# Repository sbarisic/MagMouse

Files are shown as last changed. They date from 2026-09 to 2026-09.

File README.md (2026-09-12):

# MagMouse

An open-source wired mouse exploring contactless magnetic buttons, programmable
electromagnetic click feedback, and a motorized haptic scroll wheel.

**Status: three Rev-A bench PCBs routed; supplier/CAM and hardware approval pending.**
Open the active [Main project](hardware/modular/main/Main.kicad_pro) or
[Wheel project](hardware/modular/wheel/Wheel.kicad_pro). Both have zero unrouted
connections and zero physical DRC/parity issues. See the
[routing review](hardware/modular/MAIN_SIGNAL_ROUTING.md) and
[modular hardware package](hardware/modular/README.md). The original monolithic
project is retained as a reference. These are not fabrication-ready designs;
mechanics, manufacturing and hardware qualification remain open. Contactless sensing removes
electrical switch contacts; it does not eliminate mechanical wear or other failures.

The current [Rev-A bench package](hardware/bench/README.md) targets five bare
three-board panels, one self-assembled population and one stencil, with U32
unpopulated. Encoder now uses the common four-layer construction. The
[cost checkpoint](hardware/bench/COST_CHECKPOINT.md) records historical delivered
prices of EUR 224.55 for economy panels/stencil, EUR 252.46 with paid impedance
control and EUR 335.96 for separate boards. These precede the wire revision. Components, wires and bench
mechanisms are additional; the complete delivered total remains unverified.
The files are for quote/review only, pending supplier, assembly, bench-fit and
CAM checks. Earlier [PCBA quote packages](hardware/quotes/README.md) remain as
historical comparisons, not the selected purchasing plan.

Nine internal connectors now use labelled soldered-wire arrays. The
[wire map](hardware/bench/package/wire-map.svg) retains all conductors and grounds;
[printable PETG fixtures](mechanical/bench/README.md) include editable build123d,
STEP/STL parts and assembly drawings. Fixed button magnets use
[per-button calibration](docs/button-calibration.md); runnable firmware remains
separate. The revised electronics subtotal from saved prices is EUR 73.84 for
one set, excluding optics, freight/taxes and unpriced fixture/wire materials.

## V1 concept

- ESP32-S3 with native USB Full-Speed HID; target report interval: 1 ms.
- PMW3360DM-T2QU + LM19-LSI optical sensor for cursor movement; ICM-42688-P for supplementary motion.
- Three elastic button paddles provide passive return. Each uses a TMAG5253
  position sensor with its own magnet, plus a custom moving-magnet actuator with
  a stationary wound coil, ADS7038 feedback, and a DRV8231A bidirectional driver.
- MA735 angle sensing and a GB1806 motor driven by DRV8316R for scroll haptics.
- One USB-C cable for data and 5 V power, with force limits based on detected
  source capability. A powered Type-C hub/adapter is the intended full-power source.

## Repository map

| Directory | Contents |
| --- | --- |
| [hardware](hardware/README.md) | Electronics, preliminary BOM, schematic and PCB work |
| [mechanical](mechanical/README.md) | Housing, button mechanisms, scroll assembly |
| [firmware](firmware/README.md) | Embedded architecture and bring-up plan |
| [software](software/README.md) | Future PC configuration application |
| [docs](docs/README.md) | Requirements, interfaces, power and roadmap |

Start with the [architecture](docs/architecture.md), [interface plan](docs/interfaces.md),
and [button prototype plan](mechanical/button-mechanisms/README.md), then the
[roadmap](docs/roadmap.md). [ideas.md](ideas.md) preserves the original
brainstorming notes; the organized documents distinguish selected directions from
open engineering questions.

## Contributing and licensing

See [CONTRIBUTING.md](CONTRIBUTING.md). The next milestone is mechanical-interface
CAD, resulting PCB adjustments and whole-board review before manufacturing closure.

Hardware/mechanical: **CERN-OHL-S-2.0**. Firmware, PC software and supporting code:
**GPL-3.0-or-later**. General documentation: **CC-BY-SA-4.0**.
See [LICENSE.md](LICENSE.md) for scope and full texts.

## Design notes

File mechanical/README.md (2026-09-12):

# Mechanical design

Status: editable Rev-A bench fixture CAD and optical datums; final shell and
in-mouse mechanisms remain provisional.

- [housing](housing/README.md): enclosure, optics and component packaging.
- [scroll-wheel](scroll-wheel/README.md): wheel, shaft, motor and encoder alignment.
- [button-mechanisms](button-mechanisms/README.md): three contactless haptic buttons.
- [optical](optical/README.md): PMW3360/LM19-LSI stack and aperture reference dimensions.
- [bench](bench/README.md): build123d source, 19 printable PETG part designs,
  STEP/STL exports, removable supports, wire clamps and dimensioned assembly views.

The bench fixture uses build123d 0.11.1. Optical and motor dimensions that lack
supplier evidence remain parameters requiring measurement.
Validate magnet separation with wheel and custom button-coil fields active, including
temperature and full travel. Preserve physical stops and passive return behavior
so loss of power does not depend on actuator control to constrain the mechanism.
The elastic button paddles provide passive return; validate their material,
geometry, print process, creep and fatigue as functional springs.

License: CERN-OHL-S-2.0; see [LICENSE](LICENSE).
Source location: <https://github.com/sbarisic/MagMouse>.

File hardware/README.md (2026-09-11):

# Electronics

Status: the independent main and wheel PCBs are routed, with zero unrouted
connections and zero physical DRC/parity issues. Mechanical integration,
manufacturing review and hardware qualification remain open.

- [Main project](modular/main/Main.kicad_pro) and [Wheel project](modular/wheel/Wheel.kicad_pro): active editable designs.
- [Rev-A bench panel and assembly package](bench/README.md): current cost-reduction
  variant, four-layer Encoder, one-population purchasing list and quote-only
  manufacturing files. The derived panel does not replace the source boards.
- [Modular package and reviews](modular/README.md): current routing, cable and mechanical status.
- [Original KiCad project](kicad/README.md): retained monolithic reference and circuit documentation.

- [schematics](schematics/README.md): circuit partition and review requirements.
- [pcb](pcb/README.md): layout and release requirements.
- [bom](bom/README.md): candidate component inventory.

Use the [interface allocation](../docs/interfaces.md) and
[power plan](../docs/power.md) as design inputs. Exact package variants, GPIOs,
passive values, protection circuitry and connectors remain to be validated.

License: CERN-OHL-S-2.0; see [LICENSE](LICENSE).
Source location: <https://github.com/sbarisic/MagMouse>.

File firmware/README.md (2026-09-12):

# Firmware

Target: ESP32-S3. Status: subsystem plan only; no build, flash command, device
drivers or USB implementation yet. Framework/toolchain selection is pending the
timing feasibility work. The revision 0.4 [GPIO/peripheral allocation](../docs/interfaces.md)
is checked against the schematic; runtime deadlines remain unproven.
Do not interpret this directory as runnable firmware.

The small-batch [button calibration contract](../docs/button-calibration.md)
uses secured magnets with measured released/pressed endpoints and hysteresis.
Precision matching of button magnets is not a Rev-A fabrication prerequisite.

## Planned responsibilities

| Subsystem | Responsibility |
| --- | --- |
| Board support | Validated pin map, rails, safe boot and recovery |
| Device drivers | PMW3360, ICM-42688-P, two ADS7038 devices, MA735, DRV8231A and DRV8316R |
| Input processing | Optical reports, calibrated Hall thresholds/hysteresis and wheel movement |
| Button control | Position/current feedback and bounded bidirectional click/release pulses; elastic paddle supplies passive return |
| Wheel control | Encoder calibration, commutation/FOC and bounded detent torque |
| Power/fault manager | Source capability, total budget, hardware faults and stale-sample shutdown |
| USB HID | Three buttons, relative X/Y and wheel; target 1 ms report interval |
| Configuration | Versioned profiles, validation and persistence |
| Status | Single-data-pin addressable RGB through RMT; exact LED protocol pending |

Reserve MCPWM group 0 for wheel 3-PWM and group 1 for six independent button
commands. SPI2 owns five shared devices; SPI3 serves only the wheel ADC.
Use one bounded owner per bus. Generic per-sample SPI API calls are not proof
of the required motor-current acquisition timing; measure the complete path.
Do not let a motor/LED library silently reallocate these resources.

Bring up USB and sensing with actuators disabled first. Add one current-limited
coil, then the wheel, then combined power allocation. Firmware must enforce
limits regardless of values supplied by the PC application. Define explicit
uninitialized, ready, active and fault states with actuator-off reset behavior.

The custom actuator needs a measured force/current map across position and both
polarities. Firmware commands only the added haptic force; it does not generate
the paddle's baseline spring force. Account for direction changes, current decay
and valid ADC sampling windows rather than assuming current follows PWM instantly.
Calibrate sensing with coil and wheel interference present.

Use explicit per-effect duration, duty/repeat-rate and current limits, with zero
commanded coil current after an effect and while held at rest. Include driver
wake latency in click timing and use the actual IN1/IN2 controls documented in
[interfaces](../docs/interfaces.md). The revision 0.3 schematic gates commands
with a hardware heartbeat timeout. Implement its startup, heartbeat and USB-state
contract from [power](../docs/power.md); do not assume button-driver fault telemetry
is available.

When implementation begins, add reproducible builds, host-testable control/power
logic, hardware integration checks and CI. USB VID/PID assignment, report layout,
control-loop rates and configuration transport are unresolved. Check redistribution
rights before adding optical-sensor firmware blobs or third-party motor libraries.

See [interfaces](../docs/interfaces.md), [power](../docs/power.md), and
[roadmap](../docs/roadmap.md). License: GPL-3.0-or-later; see [LICENSE](LICENSE).

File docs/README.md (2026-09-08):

# Design documentation

- [Architecture and requirements](architecture.md)
- [Electrical interfaces](interfaces.md)
- [Wheel driver, acquisition and brake implementation contract](wheel-control.md)
- [Power and actuator constraints](power.md)
- [Custom button mechanism and prototype targets](../mechanical/button-mechanisms/README.md)
- [Development roadmap](roadmap.md)
- [Reference sources](references.md)

These documents maintain the design decisions, including the custom button
actuator revision. [The original ideas](../ideas.md) are preserved as historical
notes. The current documents are a planning baseline, not a verified schematic
or a declaration of hardware compatibility.

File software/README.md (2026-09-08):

# PC configuration software

Status: scope only; no application, dependencies, build or installation workflow.
Choose supported operating systems and an application stack once the firmware
configuration protocol is defined.

Planned functions:

- Discover the mouse and display firmware/protocol compatibility.
- Configure button actuation thresholds and bounded haptic profiles.
- Configure wheel detent behavior and profile selection.
- Guide calibration and display power/fault state.
- Import/export versioned profiles with validation and explicit device writes.

Ordinary mouse input must work without this application. The device remains
responsible for current, thermal and source-power limits. Define units, ranges,
schema versioning, persistence and incompatible-profile behavior before UI work.
Configuration transport is TBD; do not assume a vendor HID or serial protocol yet.

License: GPL-3.0-or-later; see [LICENSE](LICENSE).

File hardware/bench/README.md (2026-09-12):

# MagMouse Rev-A bench prototype

**Rev-A bench prototype — pending supplier/CAM approval. Do not order yet.**

Purchasing is limited to private-consumer suppliers; the user has no business.
CODICO business-only offers are excluded. Distinguish EU-stock items from
imports with Croatia shipping; see SOURCING.md for current evidence.

This variant targets five bare panels, one populated Main/Wheel/Encoder set,
and one unframed stencil. Main and Wheel remain the maintained routed source
boards. Encoder now shares their four-layer construction. U32 is omitted only
from the bench purchasing and paste variant; its schematic and footprint remain.

## Review files

- `MANUFACTURING_REVIEW.md`: completed local manufacturing review and JLC handoff.
- `package/CAM-review-attachments.zip`: consolidated, hashed CAM review attachments.
- `L1_REVIEW.md`: implemented Bourns replacement and local buck review.
- `HARNESS_REVIEW.md`: soldered-wire pin maps, lengths and pending optical identity.
- `STENCIL_REVIEW.md`: package dispositions and remaining process limits.
- `BENCH_ACCESS_REVIEW.md`: probe access, support and local copper findings.
- `supplier-drafts/`: unsent Ploopy/JLC CAM drafts and the superseded Würth follow-up;
  exported CAM draft identifies the actual ZIP hashes.

- `Panel.kicad_pro` / `Panel.kicad_pcb`: derived 151 x 139 mm, three-design panel.
- `panel-mechanical.svg`: printable outline and component-boundary review.
- `panel-manifest.json`: source hashes, board/reference mapping and translations.
- `package/Panel-Gerbers-QUOTE.zip`: copper, mask, silkscreen, routed edges and drills.
- `package/Stencil-QUOTE.zip`: top paste with U32 and hand-fitted parts excluded.
- `package/one-set-purchasing.csv`: exact MPN groups, references, quantities,
  minimum purchases, spares and public supplier observations.
- `package/all-vias.csv`: via-only fill/cap inventory. Never fill component holes,
  tooling holes or perforation holes.
- `BENCH_FIXTURE.md`, `bench-fixture.svg`: adjustable bench arrangement; no shell claim.
- `mechanical/bench/`: editable build123d, STEP/STL parts and dimensioned fixture views.
- `package/button-calibration.md`: fixed magnet endpoint calibration; runnable firmware is separate.
- `package/harness-pin-map.csv`: all 46 wires, component-side and mirrored solder-side views.
- `population-contract.json`: 282 retained parts, nine replaced connectors and U32 exclusion.
- `ASSEMBLY_AND_BRINGUP.md`: preparation, practice assembly and staged hardware tests.
- `SOURCING.md`, `WURTH_ENQUIRY.md`: supplier evidence and unresolved interfaces.
- `ORDER_READINESS.md`: remaining PCB work for a testable bench revision.
- `COST_CHECKPOINT.md`, `quote-observations.json`: live bare-board comparisons
  and the incomplete one-population cost estimate.
- `package/evidence/acceptance.json`: fresh native and strict electrical checks.
- `package/copper-review/`: exported copper and reference-plane views.

## Construction for both quotes

Order quantity five panels, **three different designs per panel**. Use FR4 TG155,
nominal 1.6 mm, four layers **JLC041611-2116**, 1 oz outer and 1 oz inner copper,
green mask, white silkscreen, ENIG 1 microinch and epoxy-filled/copper-capped vias.
The smallest vias are 0.20 mm drill / 0.45 mm pad; retain the source drill sizes.
The website's drill selection bucket does not authorize enlarging these holes.
Require CAM confirmation of the drill and fill specification.

The guaranteed variant requests 90 ohm differential USB, tolerance +/-10%.
The economy variant omits paid impedance control/testing only. Both retain
F.Cu width 0.1466 mm, gap 0.1501 mm and In1 ground reference. Do not accept a
stack substitution without a fresh impedance and return-path review.

All functional copper belongs to an individual board. No electrical connection
crosses a tab. The panel uses 2 mm separation clearance, ten 5 mm tabs with
five 0.6 mm perforations each, 0.9 mm pitch and 0.3 mm webs. Cut while supported
and **before population**. Do not bend populated boards to depanel them.

Selected Rev-A stencil: one 220 x 200 mm unframed stainless sheet, 0.10 mm thick,
three identifiable TOP aperture groups. Apply `paste_variant.py` for the
reviewed Hall/WSON/ADC apertures; copper and coordinates remain 1:1. JLC's multi-board option requires
permission to rearrange groups: approve the final CAM group positions before
building the alignment jig. A reordered stencil requires a regenerated jig.

## Reproduce and verify

Run with KiCad 10.0.6 Python, Shapely 2.1.2 and NumPy 2.4.6. The builder searches
`build/bench-python` for the latter libraries; dependencies are not vendored.

```powershell
& '<KiCad>/bin/python.exe' hardware/bench/build_panel.py
& '<KiCad>/bin/python.exe' hardware/bench/verify_bench.py
& '<KiCad>/bin/python.exe' hardware/bench/export_bench.py
& '<KiCad>/bin/python.exe' -m unittest discover -s hardware/bench -p 'test_*.py'
```

Two native panel builds were byte-identical. Export ZIP hashes change with KiCad
timestamps; the package hashes identify each exported snapshot. Copper/pad/via
and saved ground-fill transforms are checked against the individual source
boards. Source modification requires rebuilding and rerunning checks.

## Manufacturing and assembly items still open

The L1 replacement and soldered-wire migration are implemented; see ORDER_READINESS.md.
Ploopy is the user's selected optical supplier; exact lens/part confirmation
remains open. Wire/fixture fit, optical mounting and final ergonomic shell
development are assembly/mechanical tasks, not bench bare-board ordering gates.

1. Exact wire product, insulation/strand fit, continuity and strain-relief checks.
   The FFC enquiry requirement is superseded; no follow-up is sent.
2. Complete delivered parts/harness/mechanism/consumables pricing. Catalogue
   stock is not a reserved order; missing lines are not zero-cost parts.
3. Received lens/motor dimensions and practical bench fixture fit. Final shell,
   paddle geometry, optical retention and ergonomic wheel support remain open.
4. The 0.10 mm stencil design is selected; see STENCIL_REVIEW.md for accepted
   aperture geometry and volume tradeoffs. CAM confirms manufacturability.
   Paste/profile setup, practice reflow and hidden-joint inspection are assembly
   tasks, not bare-board ordering gates.
5. Fabricator acceptance of tab support, routability, minimum vias and selective
   fill/cap instructions. Zero native DRC is not manufacturing approval.
6. Complete delivered project total. The identical-stack separate-board
   comparison is complete and favors the panel. Never treat a partial subtotal
   as the €400 target.

CAD connectivity, DRC and regression results do not establish USB operation,
motor/brake behavior, analog noise, thermal performance or assembly yield.

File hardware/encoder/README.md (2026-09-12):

# Upright wheel encoder

## Current soldered-wire revision

J7 now uses eight plated solder holes in a 2×4 array on 2.54 mm pitch,
0.8 mm nominal holes / 1.8 mm pads. All eight signals, including three grounds,
remain connected to Main J6 by the 150 mm AWG28 harness. There is no JST purchase
or paste on these lands. Sensor position and board outline are preserved; local
termination routing is updated. See the [wire map](../bench/package/wire-map.svg)
and [printable carrier](../../mechanical/bench/README.md). The historical connector
description below is superseded for Rev-A.

## Rev-A bench stack migration, 2026-09-11

The current PCB uses the same four-layer **JLC041611-2116** construction as
Main and Wheel. Original outer-layer routing, 17 through vias, sensor datum
and connector orientation are preserved. In1/In2 have ground copper. Native
DRC, schematic parity and connectivity pass. The historical description below
predates this migration; use [the bench package](../bench/README.md) for the
current panel, self-assembly variant and unresolved ordering gates.

Revision 0.8, 2026-09-09, KiCad 10.0.6. The separate **14 x 18 mm** encoder PCB
is fully routed. ERC, physical DRC and schematic parity pass; there are zero
unconnected items. These checks do not establish mechanical fit or operation.
**This is a prototype design, not a fabrication release.**

Open [Encoder.kicad_pro](Encoder.kicad_pro), then its
[schematic](Encoder.kicad_sch) and [PCB](Encoder.kicad_pcb). Keep the repository
directory structure: the library tables reference the shared MagMouse libraries
in `../kicad`. U27 and C62 have been removed from the motherboard project.

## Parts and connection

The encoder assembly BOM contains U27 MA735GGU-P, C62 local 1 uF bypass and
J7. The motherboard BOM contains J6, the switched encoder supply U28 and the
existing U29/U25 SPI buffers. No ESP32 pin allocation changed.

Both connectors use **JST SM08B-SRSS-TB(LF)(SN)**, an eight-pin, 1 mm pitch,
right-angle SMT SH header, [JLCPCB C160407](https://jlcpcb.com/partdetail/JST-SM08B_SRSS_TB_LF_SN/C160407).
The catalog listing was checked on 2026-09-09; refresh stock and assembly
eligibility when quoting. Use KiCad's standard
`Connector_JST:JST_SH_SM08B-SRSS-TB_1x08-1MP_P1.00mm_Horizontal` footprint.

| Motherboard J6 | Encoder J7 | Signal |
| --- | --- | --- |
| 1 | 1 | ENC_3V3, switched supply |
| 2 | 2 | GND |
| 3 | 3 | ENC_SCLK_LOCAL, buffered clock |
| 4 | 4 | GND |
| 5 | 5 | ENC_MOSI_LOCAL, buffered data |
| 6 | 6 | ENC_CS_LOCAL, buffered select |
| 7 | 7 | GND |
| 8 | 8 | ENC_MISO_LOCAL, return to U25 |

[harness.json](harness.json) is the machine-checked wiring specification.
Use eight separate conductors, including all three ground contacts. Check
continuity by pin number; connector appearance and wire colours do not prove
correct ordering. Do not substitute an unverified mirrored cable.

The harness needs two **SHR-08V-S-B** housings and sixteen **SSH-003T-P0.2-H**
contacts. JST specifies AWG 28-32 wire with 0.4-0.8 mm insulation diameter for
these contacts. The prototype wire-length target is **50 mm**, subject to fit
and waveform measurements. Housings, crimp contacts, wire and harness assembly
are separate from the two SMT assembly BOMs. See the
[JST SH drawing and contact specification](https://www.jst-mfg.com/product/pdf/eng/eSH.pdf).

## Placement and mechanical datums

The two-layer board has nominal 1.6 mm thickness and bounds X=50..64,
Y=50..68 mm in KiCad. All three components are on the front.

- U27 centre: (57,55.5) mm, 7 mm from the left edge and 5.5 mm from the top.
  The front of the sensor faces the shaft magnet.
- C62 centre: (56.8,52.2) mm. Its supply-pad-to-VDD route is 1.525 mm.
- J7 centre: (57,64.5) mm. Its mating direction is toward +Y, past the lower edge.
- Dwgs.User lines at X=51.5/62.5, Y=50..60 reserve provisional side clip lands.
  There are no mounting holes. The mating housing, cable bend and support need
  separate clearance beyond the PCB outline.

Signals use 0.15 mm tracks; the incoming supply uses 0.25 mm tracks.
Ground pours cover both copper layers with local return and stitching vias.
Through vias are 0.60/0.30 mm. The project uses 0.15 mm default clearance and
a 0.127 mm absolute minimum; final stackup and stencil review remain open.

For the proposed horizontal axle the board stands beside a shaft end. Sensor
height, magnet dimensions/gap and support geometry must follow the actual
wheel assembly. The 14 x 18 mm outline is provisional. A routed board does not
prove it fits the motherboard wheel reservation. See
[mechanical integration](../../mechanical/scroll-wheel/ENCODER_BOARD.md) and the
[MA735 datasheet](https://www.monolithicpower.com/en/documentview/productdocument/index/version/2/document_type/Datasheet/lang/en/sku/MA735GGU/).

## Reproduce the checks

Run from the repository root with Python 3 and KiCad 10:

    python hardware/kicad/export_review.py
    python hardware/kicad/export_review.py --schematic hardware/encoder/Encoder.kicad_sch
    python hardware/kicad/verify_encoder.py
    python hardware/kicad/test_encoder_checks.py
    python hardware/kicad/verify_wheel.py
    python hardware/kicad/test_wheel_checks.py
    python hardware/kicad/export_pcb_review.py
    python hardware/kicad/export_pcb_review.py --board hardware/encoder/Encoder.kicad_pcb --require-routed

Encoder outputs go to `build/encoder-review` and `build/encoder-pcb-review`;
motherboard outputs remain in their existing review directories. Each project
gets a separate draft BOM. The wheel checker reads both netlists. The encoder
checker validates the connector identities, switched/buffered boundaries, pin
ordering, local bypass and component split against the harness specification.
Eight encoder tests include seven injected faults. Five wheel tests also pass.

The motherboard has 317 footprints. Its [actuator distribution routing pass](../pcb/ACTUATOR_DISTRIBUTION_LAYOUT.md)
reduces native unrouted connections to 247. Physical DRC and parity pass, but
board-wide routing remains open. Before releasing either
board, verify cable continuity, 10 MHz SPI waveforms under concurrent operation,
power-off isolation, angle repeatability, magnetic interference and mechanical
retention. No Gerbers or placement files are released for ordering.

Motherboard J6 is now rotated 180 degrees at (113, 103.5) mm and mates toward
minus Y, the front edge. Check shell/USB clearance and harness bend radius.
Encoder J7 and the pin-to-pin harness map are unchanged.

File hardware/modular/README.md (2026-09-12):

> Rev-A bench update: internal interfaces now use soldered through-hole arrays.
> The active manufacturing-review package is `hardware/bench/`; its HARNESS_REVIEW.md
> and generated wire maps supersede historical FFC/JST details below. Order scope
> is five bare three-board panels, one component population and one stencil.
> No final-shell or supplier/CAM acceptance is claimed.

# Modular mouse planning package

2026-09-11. **Main and wheel routed with zero unrouted connections. Mechanics remain provisional.**

Independent [main](main/Main.kicad_pro) and [wheel](wheel/Wheel.kicad_pro)
schematics now exist. They include J8/J9 signal headers, J10/J11 power headers
and local disconnect bias. The wheel also has local bulk storage, TVS and a
discharge resistor. Both pass ERC. See the
[interface review](INTERFACE_REVIEW.md) for the implemented changes, verification
commands and remaining power-return, wheel-storage and SPI3 timing findings.
The [wheel PCB](wheel/Wheel.kicad_pcb) has all 87 footprints on its 55 x 60 mm
outline. All connections are routed, with zero native unrouted items and zero
physical DRC/parity issues. See the [routing review](WHEEL_ROUTING.md).
The new [main PCB](main/Main.kicad_pcb) has all 246 footprints placed on the
125 x 80/44 mm outline, with zero physical DRC/parity issues and **zero native
unrouted connections**. The [completed signal/return review](MAIN_SIGNAL_ROUTING.md)
covers analog, USB, both SPI buses, optical, remaining controls and supplies.
The [input-power](MAIN_POWER_ROUTING.md) and
[source/actuator/interlock](MAIN_CONTROLS_ROUTING.md) checks still pass.
See the [main placement review](MAIN_PLACEMENT.md) and
[mechanical interface register](MECHANICAL_INTERFACES.md).

**Panelization is on hold until both boards have stable placement and mechanical
interfaces.** Existing nesting-study files remain unchanged. Neither board is
being released for ordering in this pass.

The prototype assumes fully connected internal cables. Per the user's decision,
child-board damage after disconnection is acceptable; disconnect/partial-insertion
survival does not block layout or require extra protection. Normal connected
power, thermal, signal and regeneration checks remain applicable.

The target order is five assembled panels, each with one main, one wheel and
one encoder board, delivered to Croatia, 43000. The finished main-board outline
uses the approved 125 mm length, 80 mm maximum width and 44 mm front edge.
Curvature and width-transition locations are draft assumptions from the sketch.

Panel nesting concept

## Concrete outputs

- [Main.kicad_pcb](main/Main.kicad_pcb): all 246 split-main footprints placed
  in the shaped 80 x 125 mm outline, with a 44 mm front edge.
- [Main-envelope.kicad_pcb](planning/Main-envelope.kicad_pcb): historical
  outline-only planning source with the source motherboard's four-layer stackup.
- [Wheel-envelope.kicad_pcb](planning/Wheel-envelope.kicad_pcb): provisional
  55 x 60 mm reservation. Its electronics now fit the independent wheel PCB;
  mounts, mating cables and assembled mechanical fit remain unproven.
- [Encoder-envelope.kicad_pcb](planning/Encoder-envelope.kicad_pcb): 14 x 18 mm
  reservation with the common four-layer stack. The existing routed encoder
  has not yet been converted or transferred into this file.
- [Panel-nesting-study.kicad_pcb](planning/Panel-nesting-study.kicad_pcb):
  147 x 135 mm drawing on Dwgs.User. It has no manufacturing Edge.Cuts, slots
  or breakaway drills. Open in PCB Editor, not 3D Viewer.
- [Partition report](planning/partition-report.json): complete proposed
  reference ownership and both endpoints of every main/wheel boundary net.
- [Partition and harness specification](partition-plan.json): editable inputs.

The files under `planning/` are historical envelope/nesting studies. They are
separate from the editable main and wheel PCB sources. The original motherboard
and routed encoder project remain unchanged.

The panel reserves 5 mm outer handling rails and at least 2 mm between unit
envelopes. Grey areas in the drawing are support-web space, not a finished
solid panel: routed slots and supports must be designed around actual loaded
boards. Perforated tabs connect boards mechanically; no electrical nets cross
them. Final tooling, tab access and unit support are still open.

## Circuit partition and interface

The fresh source netlists account for 320 footprints: 241 main, 76 wheel and
3 encoder. Counts include test points and exclude new modular-interface parts.
They are not the number of components that JLCPCB would populate.
The split schematics add 13 interface and 3 local power parts: current counts
are 246 main, 87 wheel and 3 encoder. The nesting drawing retains baseline
ownership counts. See [local power review](LOCAL_POWER_REVIEW.md).

Wheel ownership contains U21 DRV8316, U22 disable gates, U23 ADC2 with local
filters/reference/bypass, U24/U26 forward buffers and the complete brake
including comparator, reference, MOSFET, resistors and local capacitors.
SOA/SOB/SOC, their filters and all brake sense/gate/reference connections stay
within that board. Re-place them together before carrying any routes across.

U25 and C53 remain on main for return buffering. The switched encoder power
U28, forward buffer U29/C55 and J6 also remain on main. Retain the existing
[J6-to-J7 harness](../encoder/harness.json) directly to the encoder; routing
encoder traffic through the wheel board is no longer the preferred plan.
The wheel board still needs the ESP32 or a test fixture to commutate the motor.

The main/wheel boundary has **17 nets: 14 digital signals, +3V3, ACT_5V and GND**.
The signal harness has 30 contacts. Main J8 odd pins are GND; the J8 even pins
below each have an adjacent return. A flat same-side FFC between facing headers
maps J8.N to J9.(31-N), so wheel J9 even pins are GND. A prototype Hirose
FH12-30S-0.5SH(55) header is selected; cable orientation and conductor construction
remain unapproved. See the interface review.

| Main J8 pin (wheel J9 = 31 minus this pin) | Net | Direction |
| --- | --- | --- |
| 2 | SPI_SCLK | Main to wheel |
| 4 | SPI_MOSI | Main to wheel |
| 6 | CS_DRV8316 | Main to wheel |
| 8 | DRV_MISO_LOCAL | Wheel to main |
| 10 | MOTOR_SPI_SCLK | Main to wheel |
| 12 | MOTOR_SPI_MOSI | Main to wheel |
| 14 | CS_ADC2 | Main to wheel |
| 16 | ADC2_MISO_LOCAL | Wheel to main |
| 18 | WHEEL_PWM_A | Main to wheel |
| 20 | WHEEL_PWM_B | Main to wheel |
| 22 | WHEEL_PWM_C | Main to wheel |
| 24 | ACT_DRIVE_EN | Main to wheel |
| 26 | WHEEL_RUN_REQ | Main to wheel |
| 28 | DRV_FAULT_LOCAL_N | Wheel to main |
| 30 | +3V3 | Main to wheel |

ACT_5V and its power return use a separate two-contact harness provisionally.
A candidate is JST SM02B-PASS-TB(LF)(SN),
[JLCPCB C495198](https://jlcpcb.com/partdetail/JST-SM02B_PASS_TB_LF_SN/C495198).
JST rates the [PA family](https://www.jst-mfg.com/product/pdf/eng/ePA-F.pdf)
at 3 A with AWG22. This is not approval for a 3 A motor load: voltage drop,
regenerative pulses, connector temperature, wire size and protection still
need a budget. The no-boss header footprint and mating parts are now specified
in the interface review; stock, cable sourcing and assembly sign-off remain
open. A 50 mm signal cable is a provisional target, not a tested limit.

## Implemented interface and remaining connected-operation review

Extraction and local bias additions are implemented. Current closure status
and quantitative findings are in
[INTERFACE_REVIEW.md](INTERFACE_REVIEW.md). Physical harness and power-ramp
acceptance remains open even where settled-DC bias checks pass.

- Keep the implemented wheel-local low defaults on RUN/PWM and main R77 boot
  strap. The existing bias circuitry remains fitted.
- Retain local ACT_DRIVE_EN pulldown R84 and review independent power-up/down
  of +3V3 and ACT_5V. Keep autonomous brake operation independent of the host.
- Retain the implemented CS and U25 return-input bias. Normal connected reset
  and startup logic levels still need to be correct.
- Review partial-power behavior of every buffer, ADC and gate, including
  signal injection when one rail is absent. Confirm from the actual parts'
  datasheets; moving the existing buffers is not proof of safe sequencing.
- Review normal current sharing between power and signal ground conductors
  with both cables fully seated. Open-return and disconnect survival are outside
  prototype acceptance; do not add protection solely for those cases.
- Budget SPI3 round-trip delay through cable, buffers and ADC, plus SPI2 loading
  and branches. Provide appropriate source termination after that review and
  verify waveforms on hardware. SPI frequency alone does not define edge quality.
- Select actual connector MPNs and matched cable pin numbering, then add both
  connector endpoints, new bias components and test access to the schematics.
  Verify all 17 boundary nets by pin number in both assembled harnesses and CAD.

## Quote obtained and what remains

New [quote-only manufacturing packages](../quotes/README.md) are available for
five separate Main, Wheel and Encoder boards each. They contain actual routed
Gerbers/drills, validated BOM/CPL files and exact via-fill inventories. All three
jobs are now priced: EUR 779.84 in merchandise; the address-specific DHL DDP
checkout is USD 1,187.35 including shipping and duties/taxes. Main R25, Wheel U31 and Encoder U27
are out of stock; the PMW3360 and non-PCBA items are separate. See the linked
quote report for the full scope. Encoder stays two-layer in this comparison;
no production panel has been created and no order was submitted.

The [live JLCPCB calculator](https://cart.jlcpcb.com/quote) displayed
**US $179.47 for five bare 147 x 135 mm panels**, or **$35.89 per set in PCB
fabrication alone**. See the [recorded inputs and itemization](jlcpcb-quote-2026-09-10.json).
Settings: three different designs, four layers, nominal 1.6 mm,
JLC041611-2116, 1 oz outer/inner copper, green mask, ENIG, impedance control
and epoxy-filled/copper-capped vias. The quoted dimensions are provisional.

The calculator also gave $157.08 with ordinary plugged vias. That option is
excluded from the baseline because the current U1/C32/U21 in-pad vias require
filled/capped processing. Merely changing the order checkbox is not a valid
cost reduction for that layout. The browser was restored to filled/capped.

**The earlier bare-panel session obtained no assembled or delivered total.** Its assembly screen required
Gerbers before proceeding. The destination selector returned an empty country
list, so shipping to Croatia could not be calculated. No files were uploaded,
no supplier quote ID was issued and no order was placed. Components, assembly,
cables, shipping and taxes are absent from the $179.47 figure.

JLCPCB treats separable circuits as
[different designs](https://jlcpcb.com/help/article/different-design-in-your-pcb-files).
One panel therefore does not avoid mixed-design fees. Obtain assembly acceptance
for three designs on this panel and delivery with tabs intact. Follow its
[panelization guidance](https://jlcpcb.com/blog/mouse-bite-panelization-guide)
when creating the actual slots and tabs. The price above does not establish
acceptance of the unimplemented assembly panel.

To obtain a final assembled quote, finish the interface schematics, place and
route all units, validate the common encoder stackup, finish panel tooling and
export matching Gerbers/drills/BOM/panel-coordinate CPL. Resolve sensor and
connector sourcing and any assembler exclusions, then price five panels with
all 15 unit boards populated and shipping/tax for Croatia 43000. Compare against
separate boards shipped together before choosing the manufacturing format.

## Regenerate and validate the planning package

Export fresh XML netlists with KiCad before running the generator:

```powershell
$kicadCli = 'C:/Users/cartm/AppData/Local/Programs/KiCad/10.0/bin/kicad-cli.exe'
New-Item -ItemType Directory -Force build/modular | Out-Null
& $kicadCli sch export netlist --format kicadxml -o build/modular/main-netlist.xml hardware/kicad/MagMouse.kicad_sch
& $kicadCli sch export netlist --format kicadxml -o build/modular/encoder-netlist.xml hardware/encoder/Encoder.kicad_sch
python hardware/modular/build_planning.py --main-netlist build/modular/main-netlist.xml --encoder-netlist build/modular/encoder-netlist.xml
```

The generator verifies reference ownership, encoder uniqueness, complete
logical boundary coverage, absence of sensitive analog/phase/brake nets on
the cable, main-board dimensions and panel-envelope spacing. These checks
establish planning consistency only; they do not establish electrical
connectivity, DRC, return paths, thermal performance, mechanical fit or
manufacturing readiness of the future split.

Validation on 2026-09-10: KiCad loaded all four planning files with four copper
layers and no footprints or tracks. All three unit outlines form closed native
polygons; the panel drawing correctly has no board outline. Source PCB reference
sets match the fresh netlists (317 main-source and 3 encoder). Moving an ADC2
filter resistor into the main partition was rejected as two uncovered analog
boundary nets. Quote line items sum to $179.47. The source motherboard SHA256
is unchanged from the start of this planning pass.

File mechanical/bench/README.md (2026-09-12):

# Rev-A printable bench fixture

These are adjustable bench supports, not mouse-shell or final mechanism CAD.
Use `build_fixture.py` with build123d 0.11.1. The editable dimensions are in
`PARAMS`; an optional JSON `--config` overrides them. Run `python
mechanical/bench/build_fixture.py` to regenerate STEP, STL, assembly views and
validation. Print the dimensioned SVG at 100% and check its 100 mm scale.

Print PETG parts separately, with the broad flat face on the bed. Use a nozzle
and line width that can resolve the 0.3 mm saddle lip (for example a 0.25 mm
nozzle); do not assume a 0.4 mm extrusion reproduces that feature. Start with
0.2 mm layers and four perimeters; orient the lever on its side so the thin
flexure is not printed as an unsupported cantilever. Inspect the flexure and clamp sample before
printing the complete set. These are trial print settings, not a strength or
fatigue qualification. The largest pieces are 125 × 130 mm, below 180 × 180.

Build one fixture from four base tiles. Join the vertical seam with four
`tile_joiner_x` bridges centred at x=127.5 and grid y coordinates clear of
boards; join the horizontal seam with four rotated `tile_joiner_y` bridges
centred at y=130 and grid x coordinates. Confirm all chosen holes align before
tightening. Use M3 screws, washers and nuts. Keep the optical window unobstructed.

Use eight saddles/caps for Main and Wheel at the coordinates in
`generated/assembly-clearance.json`. M3 threaded rods, paired nuts and washers
set board height from 15 to 35 mm above the base top. Use nonconductive caps
with no more than 0.3 mm edge engagement. Verify copper/component clearance
against `package/support-clearances.csv`; never clamp a solder joint. The STEP
assembly includes board-outline envelopes and supports; it does not model all
real component heights. Measure underside parts and retain at least 5 mm free
below the lowest part or joint. Solder protrusions must remain below 1.5 mm.

The motor plate has general-purpose slots, a shaft clearance hole and an
optional measured bolt circle. `motor_bolt_circle=None` means no motor pattern
is claimed. Mount only the stationary motor structure. The upright carrier
supports a separately adjusted Encoder board using removable side clips; fit
clips to clear edge regions and leave the sensor face unobstructed. Verify
shaft/magnet alignment and gap after receiving parts. Do not run an unsecured
magnet. Lens retention width is likewise unset until the Ploopy lens is measured.

Print one lever/stop sample, then three after checking passive return and travel.
The magnet pocket's 5 mm diameter / 2 mm thickness defaults are editable trial
dimensions. Bond the magnet securely after polarity checks. Position the holder
over the unchanged Hall sensor, add shims and a hard stop that prevents contact,
then calibrate in software. The printed flexure requires fatigue and return-force
tests; it is not a production paddle. See `docs/button-calibration.md`.

Use a clamp at each end: two ribbon clamp pairs, two encoder clamp pairs and
eight compact pair clamps for power and coils. Shim the channel to grip insulation without
crushing it; the channel is deliberately adjustable for the selected wire.
Allow slack between clamp and board. Install wires after reflow and before
optical fitting. No clamps or new mounting holes are added to the PCBs.

Hardware purchasing starts with 150 M3 nuts, 150 washers, 100 M3×16/25 screws and
twelve 60 mm M3 threaded rods, plus any measured motor-adapter fasteners. These
are a provisional kit allowance, not an exact priced BOM. Wire, PETG, adhesive,
fastener and mechanism prices remain unquoted in EUR. Assembly tools are excluded.

Open physical checks: wire insulation/strand fit, encoder clip fit, lens stack
and retention, motor pattern, probe-barrel approach, actuator/coil attachment,
flexure performance, thermal behaviour and complete assembly interference.
CAD solid validity and board-envelope checks do not close these checks.

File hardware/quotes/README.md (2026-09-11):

# JLCPCB quote packages

**Latest comparison:** the [corrected fabrication quote](cost-reduction-2026-09-11/CORRECTED_QUOTE.md)
is **USD 774.51 DHL DDP delivered, approximately EUR 665.85 for two assembled
sets**, without the optional IMU. Five PCBs per design are fabricated and two
assembled. This removes an unnecessary small-via pricing tier while retaining
the actual CAD, fill/cap and Main USB impedance specification. The price is
about EUR 73.47 below the earlier two-set quote. Stock/optical/mechanical
exclusions remain; no order was submitted. Main/Wheel consolidation has a
[placement assessment](cost-reduction-2026-09-11/COMBINED_BOARD_ASSESSMENT.md),
not a finished combined layout or supplier quote. Earlier observations follow.

The [2026-09-11 snapshot](2026-09-11/validation.json) exports the current routed
Main, Wheel and Encoder boards from CAD commit `743d7f1`. It is **for pricing
only**, not a fabrication or assembly release. The boards and schematics are
unchanged. All three Gerber/BOM/CPL jobs have been uploaded and priced in the
signed-in JLCPCB workflow. With the user-provided shipping address for Croatia
43000, checkout quotes **USD 1,187.35 delivered by DHL DDP for five sets**:
USD 907.11 merchandise + USD 36.20 shipping + USD 244.04 customs duties/taxes.
This is **USD 237.47 per set**, approximately **EUR 1,021 total / EUR 204 per set**.
The EUR conversion uses the same cart's EUR 779.84 / USD 907.11 merchandise
values; checkout itself displays USD, so this is not a guaranteed EUR payment
amount. **The stock and optical/mechanical exclusions below still apply.**
No order or payment was submitted; the payment step was not entered.
See the [itemized live quote](jlcpcb-live-2026-09-11.json).

The [cost-reduction study](cost-reduction-2026-09-11/README.md) contains an
independent Main quote with U32 omitted, at EUR 411.26 for five boards, and
six-layer manufacturing comparisons. The original CAD and baseline cart are
unchanged. The measured changes suggest about 19% delivered savings for the
half-ounce six-layer/no-IMU case, subject to redesign and a fresh checkout;
they do not establish the requested 50% reduction.

The later [two-set quote](cost-reduction-2026-09-11/TWO_SET_QUOTE.md) is
**USD 859.98 DHL DDP delivered, approximately EUR 739.32**, with U32 IMU omitted.
It fabricates five of each design and assembles two, leaving three bare spares
per design. This reduces total spending by about 28%, while increasing the
cost per assembled set. It retains the stock/optical/mechanical exclusions.
The new three cart jobs are separate from the preserved five-set baseline;
neither is a breakaway panel. No order or payment has been submitted.

| Five-board job | PCB | Components | PCBA including components | Quote-page total |
| --- | ---: | ---: | ---: | ---: |
| Main | EUR 152.24 | EUR 233.19 | EUR 351.06 | EUR 503.29 |
| Wheel | EUR 99.58 | EUR 77.18 | EUR 145.99 | EUR 245.57 |
| Encoder | EUR 17.62 | EUR 1.50 | EUR 13.35 | EUR 30.97 |

The PCBA column includes the components column; do not add them again. The cart
rounds individual PCB/PCBA lines separately and is EUR 0.01 above the sum of
the three quote-page totals. Component purchases total EUR 311.87, including
the supplier's attrition quantities. Main/Wheel use Standard PCBA; Encoder
uses Economic PCBA and remains two-layer.

**Stock exclusions:** Main R25 / C23259 (887k resistor), Wheel U31 / C139302
(LM4040AIM3-2.5/NOPB), and Encoder U27 / C17233427 (MA735GGU-P). Exact-MPN
encoder search also found zero public and idle stock. No substitutes were
selected. The priced population is 205 Main + 81 Wheel + 2 Encoder references
per set, rather than the requested 291. Main J2/J3/J4 and SW1/SW2 were initially
unchecked by matching and were explicitly included before pricing.

These are partial-population quotes, not functional complete sets. The optical
sensor and mechanical/cable exclusions below also remain. The earlier
country-level shipping estimate of EUR 23.09 gave EUR 802.93 before tax.
The later address-specific DDP quote above supersedes that delivered-cost
estimate. The user authorized entering the address and phone for this quote.
Those personal details are not stored in repository artifacts. Supplier
placement rotation, small-board handling and manufacturing review are not
approved by obtaining this price.

Quote five of each design (five complete electronic sets) for Croatia, 43000.
Upload each row as a separate job, using its matching Gerber archive, BOM and
CPL. Supply the [manufacturing notes](2026-09-11/MANUFACTURING_NOTES.md) and each
board's via map/inventory with the quote request.

| Job | Gerbers/drills | BOM | CPL | Quoted components per board |
| --- | --- | --- | --- | ---: |
| Main | [ZIP](2026-09-11/Main/Main-Gerbers-QUOTE.zip) | [BOM](2026-09-11/Main/Main-BOM-QUOTE.csv) | [CPL](2026-09-11/Main/Main-CPL-QUOTE.csv) | 206 |
| Wheel | [ZIP](2026-09-11/Wheel/Wheel-Gerbers-QUOTE.zip) | [BOM](2026-09-11/Wheel/Wheel-BOM-QUOTE.csv) | [CPL](2026-09-11/Wheel/Wheel-CPL-QUOTE.csv) | 82 |
| Encoder | [ZIP](2026-09-11/Encoder/Encoder-Gerbers-QUOTE.zip) | [BOM](2026-09-11/Encoder/Encoder-BOM-QUOTE.csv) | [CPL](2026-09-11/Encoder/Encoder-CPL-QUOTE.csv) | 3 |

These files request **291 placements per set, 1,455 across five sets**. Main U35
PMW3360 is separately sourced/installed and is excluded from both assembly input
files. Its existing catalog ID and status remain in Main's procurement list.
The 44 copper-only test points are excluded explicitly. Lens, motor, coils,
cables, magnets, bearings, wheel and shell need separate cost lines.

## Validation

All **336 schematic/PCB references** are accounted for: 291 assembly components,
44 copper test points and one separately installed sensor. BOM and CPL have
identical population sets and no duplicates. Component values, footprints,
DNP/exclusion flags, connected pin/net assignments, native placement positions,
rotations and board sides are checked against current CAD.

Fresh native DRC/parity and connectivity checks pass on all three boards:
zero physical violations, parity issues and unrouted connections. All required
copper, mask, paste, silkscreen, outline and separate PTH/NPTH drill files were
generated. Every exported via drill hit matches CAD diameter/position, allowing
0.000501 mm for the 1 µm Excellon coordinate precision. Gerbers use 4.6 metric
coordinates; all manufacturing files share the absolute origin.

| Board | CAD vias | Vias whose drill overlaps an SMD pad | Quote treatment |
| --- | ---: | ---: | --- |
| Main | 875 | 102 | Fill/cap all 875 actual vias |
| Wheel | 196 | 36 | Fill/cap all 196 actual vias |
| Encoder | 17 | 0 | Ordinary tented vias |

Component holes and USB shell slots must remain open. The overlap list includes
partial drill/pad intersections; it is broader than a list of vias centred in
exposed pads. [Main map](2026-09-11/Main/via-map.svg),
[Wheel map](2026-09-11/Wheel/via-map.svg) and exact per-board CSV coordinates
identify the locations. Main/Wheel use the selected four-layer JLC041611-2116
stack; Main requests the existing 90 Ω USB geometry. Encoder stays two-layer.

Eight exporter fault-injection tests pass, including missing/duplicate references,
wrong quantities, mirrored coordinates and an off-centre drill/pad overlap.
Native assembly and via-map SVGs were visually inspected. Source hashes were
checked unchanged after export; each snapshot contains output checksums and
fresh netlist/DRC/position/drill evidence. This validates the pricing inputs;
it does not establish stock, JLC rotation conventions, mechanical fit or production
process acceptance. The existing 59 routing tests were not rerun because no CAD
or routing code changed.

## Generate a new snapshot

Use KiCad 10's Python interpreter and a **new** output directory:

```powershell
& 'C:/Users/cartm/AppData/Local/Programs/KiCad/10.0/bin/python.exe' hardware/quotes/export_quote_packages.py --output build/new-pcba-quote
& 'C:/Users/cartm/AppData/Local/Programs/KiCad/10.0/bin/python.exe' -m unittest discover -s hardware/quotes -p 'test_quote_exports.py'
```

The exporter does not overwrite existing snapshots or save/refill CAD sources.
It aborts on coverage/DRC/parity/source-change failures and leaves an
`INCOMPLETE_DO_NOT_UPLOAD.txt` marker. Do not use incomplete output. Read
`validation.json` and verify the current source hashes before reusing an older
snapshot. The generated CSVs are CAD machine inputs, not a cost spreadsheet.

## Next pricing and release steps

Resolve the three stock shortages and optical sourcing, then reprice with full
population. Inspect supplier placement rotations and confirm via processing,
stackup, 90 Ω tolerance/testing, connector soldering and assembler handling
panels. Reprice final production files and population before payment. The earlier
$179.47 bare-panel estimate is a different scope.

Final production panel work remains after mechanical freeze, PCB adjustments,
whole-board review, encoder stack migration and manufacturing closure.

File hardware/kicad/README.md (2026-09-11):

# KiCad electronics

This directory is the **retained monolithic reference**. Current work uses the
independent [Main project](../modular/main/Main.kicad_pro) and
[Wheel project](../modular/wheel/Wheel.kicad_pro), both now routed with zero
unrouted/DRC/parity issues. See the [modular package](../modular/README.md).
The revision and instructions below describe the older reference project.

Revision 0.8, 2026-09-09, KiCad 10.0.6. USB-C power, MCU allocation and wheel/brake, IMU, RGB and PMW3360 circuits are connected.
A [60 x 95 mm motherboard placement](../pcb/README.md) is available as of
2026-09-09, with all 317 footprints on-board. U27/C62 and J7 are in a separate,
fully routed [14 x 18 mm encoder project](../encoder/README.md). Both are editable
development drafts; **the motherboard is partially routed and neither board is
order-ready**. Firmware, measurements and mechanical fit remain open.

## Open the retained reference

1. Open [MagMouse.kicad_pro](MagMouse.kicad_pro) in KiCad Manager.
2. Open [MagMouse.kicad_sch](MagMouse.kicad_sch).
3. Enter a sheet and press **E** on a component to inspect its MPN, footprint,
   LCSC number and sourcing status.
4. Open [MagMouse.kicad_pcb](MagMouse.kicad_pcb) in PCB Editor for the initial
   layout. Enable Dwgs.User for reservations and F.Fab/B.Fab for references.

Use the standard KiCad 10 libraries. The local symbol and footprint libraries
are registered by [sym-lib-table](sym-lib-table) and [fp-lib-table](fp-lib-table).
No JLCPCB plugin is needed. Edit the schematic files directly.

| Sheet | Implemented content |
| --- | --- |
| Overview | Eighteen-page hierarchy and remaining work |
| 01 Power / USB | USB-C data/CC protection, TUSB320 sink detection, TPS62162 fixed 3.3 V regulator |
| 02 MCU | ESP32-S3 module, USB, reset/boot, recovery pads and power-control GPIOs |
| 03 Buttons | Three DRV8231A bridges, VREF/current feedback, input pulldowns and coil connectors |
| 04 Sensing | Three switchable Hall sensors, ADS7038; all eight ADC channels assigned |
| 05 Protected power | Separate input/actuator eFuses, UVLO/OVLO, ramps, fault/reset and enable clamp |
| 06 Actuator interlock | Hardware heartbeat timeout, source/reset/sensor-qualified arm and six input gates |
| 07 Power monitor | CC-selected current-limit resistors, buffered input-current sensing, VBUS presence and ACT voltage |
| 08 Actuator rail | Input/actuator transient clamps, ACT storage/discharge and test pads |
| 09 Interface reservations | MCU interfaces, test pads and boot/control bias |
| 10 Wheel driver | DRV8316R, 3-PWM hardware shutdown, charge pump, unused-buck termination and motor wire pads |
| 11 Wheel SPI | Driver/ADC2/encoder power-domain buffers and fault return |
| 12 Wheel feedback | Second ADS7038, phase-current filters, switched encoder supply and J6 cable header |
| 13 Regeneration brake | ACT-powered comparator/reference, MOSFET and four power resistors |
| 14 IMU | ICM-42688-P, shared SPI2, INT1 and supply bypass |
| 15 RGB status | Single-data-pin LED, enabled regulator and logic buffer |
| 16 Optical power | Sensor-enabled ramp switch, 1.9V LDO, illumination feed and bypass |
| 17 Optical sensor | PMW3360, isolated SPI/CS and strong reset buffer |

VBUS_USB feeds PWR_5V through U12; U13 supplies ACT_5V. These rails replace the
disconnected pending nets. The TPS62162 and 3.3 uH inductor replace the original
TLV62569/divider circuit. See [power behavior and firmware requirements](../../docs/power.md)
and [power sourcing/package review](POWER_REVIEW.md).

Each button bridge retains the provisional 0.333 A trip setting:
1.65 V / (0.0015 × 3300 ohms). Actual force, current accuracy, winding heating
and pulse duration require the mechanical experiment. Coils, magnets, paddles
and wiring are external assemblies, not SMT parts.

## Review exports

From the repository root, run these commands with Python 3 and KiCad 10:

    python hardware/kicad/export_review.py
    python hardware/kicad/export_review.py --schematic hardware/encoder/Encoder.kicad_sch
    python hardware/kicad/verify_encoder.py
    python hardware/kicad/test_encoder_checks.py
    python hardware/kicad/verify_power.py
    python hardware/kicad/verify_resources.py
    python hardware/kicad/verify_wheel.py
    python hardware/kicad/test_wheel_checks.py
    python hardware/kicad/verify_peripherals.py
    python hardware/kicad/test_peripheral_checks.py
    python hardware/kicad/verify_optical.py
    python hardware/kicad/test_optical_checks.py

The exporter accepts --kicad-cli PATH. The checker accepts --footprints PATH
for a nonstandard KiCad footprint installation. Generated files go to
build/kicad-review: eighteen SVG sheets, XML netlist, ERC JSON, DRAFT-bom.csv,
review-status.json, power-checks.json, resource-checks.json, wheel-checks.json, peripheral-checks.json and optical-checks.json. Sources are not overwritten.

The motherboard has **273 BOM components**, all with catalog IDs, MPNs and
footprints; 43 copper test pads, J5 motor wire pads and four power flags are
excluded from its BOM. The separate encoder has one schematic sheet and three
BOM components/footprints: U27, C62 and J7. Across both projects there are 19
schematic pages, 276 BOM components and 320 footprints. Encoder review outputs
and its separate draft BOM go to `build/encoder-review`; its two incoming power
flags are excluded from assembly. Export both netlists before running the wheel
checker. The encoder checker also verifies the actual harness contract.
**Both projects: ERC zero errors and zero warnings, without new waivers.**
The additional checker verifies 195 critical power pin connections, 317 motherboard footprint
assignments, complete source-to-export coverage and 4,096 Boolean interlock
cases. The resource checker verifies all 39 module GPIOs: 38 assigned and GPIO46
reserved low for boot-safe expansion. See [the full allocation](../../docs/interfaces.md).
The wheel checker adds 266 pin checks, 32 shutdown cases, 58 custom land checks
and 128 brake corners; five wheel tests include four fault injections.
Optical adds 81 pin checks, ten identities, 16 land coordinates and eight fault injections.
See [optical implementation](OPTICAL_DESIGN.md) for pending sample and firmware evidence.
See [wheel design and evidence](WHEEL_REVIEW.md) and [IMU/RGB review](PERIPHERAL_REVIEW.md). Analog timing, firmware
deadlines, thermal behavior and USB compliance are not simulated.

Catalog identity does not reserve stock. U11's current JLCPCB listing requires
Standard PCBA; refresh service eligibility and pricing before placing an order.
These schematic tools do not produce manufacturing files. Use
`python hardware/kicad/export_pcb_review.py` for the separate PCB placement/DRC
review; see [board setup and remaining layout work](../pcb/README.md).
The first [buck routing pass](../pcb/BUCK_LAYOUT.md) also provides native copper
connectivity checks and fault-injection tests, run with KiCad's bundled Python.

## Work before full-board freeze

A bench prototype and preliminary placement can proceed before all measurements
are complete. Full-mouse routing needs settled circuitry, pin allocation and
mechanical dimensions. The following tests are acceptance gates, including tests
that require a prototype PCB; finished firmware is not required to start layout.

- Implement and measure USB startup, configuration, suspend/resume and source
  changes. Verify the 100 mA startup and 2.5 mA suspend requirements.
- Prototype one button; measure force/current, winding properties, current-sense
  accuracy, heating, passive return and magnetic interference.
- Test timeout/reset/short-circuit behavior, cable drop, inrush, reverse current,
  regenerative clamp behavior and component temperatures.
- Qualify the [PMW3360 circuit](OPTICAL_DESIGN.md), samples, SROM and optical stack.
  Review and measure the [IMU/RGB circuits](PERIPHERAL_REVIEW.md). Validate wheel current/angle
  acquisition and the provisional autonomous regeneration brake on hardware.
- Validate the [allocated SPI/PWM timing budgets](../../docs/interfaces.md), review symbols,
  land patterns and stencil requirements, then perform board layout and DRC.

See [SOURCING.md](SOURCING.md) for retained component evidence and
[the roadmap](../../docs/roadmap.md) for the broader project.

The [input-power routing pass](../pcb/INPUT_POWER_LAYOUT.md) adds C88,
USB-to-eFuse-to-buck copper, protection and source-selection routes, and
a board-wide In1 ground reference. USB geometry is recorded in the
[selected stackup](../pcb/STACKUP.md); the [USB/ILM pass](../pcb/USB_LAYOUT.md)
now routes the pair over continuously checked In1 ground. Full-board routing remains open.

The [Type-C routing pass](../pcb/TYPEC_LAYOUT.md) completes the detector inputs,
returns and source-selection supplies. The [U13 local routing pass](../pcb/ACTUATOR_POWER_LAYOUT.md)
adds C89 and connects its feed, bypass and protection network. Native connectivity
has 204 unrouted connections after the [USB/ILM pass](../pcb/USB_LAYOUT.md).
Actuator feeds, driver/brake outputs, current sensing, interlocks and gate supplies
are connected and checked, as are USB data and buffered input-current telemetry.
SPI, optical and remaining board routing are open.
Six component-land vias at U1/C32/U21 require filled/capped fabrication and stencil review.

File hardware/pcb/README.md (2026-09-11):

# Motherboard PCB

The active shaped [Main PCB](../modular/main/Main.kicad_pcb) and separate
[Wheel PCB](../modular/wheel/Wheel.kicad_pcb) are now routed. See the
[current modular package](../modular/README.md). The rest of this document
describes the retained monolithic routing baseline.

Routing draft, 2026-09-09, KiCad 10.0.6. Open the editable
[MagMouse.kicad_pcb](../kicad/MagMouse.kicad_pcb) from the
[KiCad project](../kicad/MagMouse.kicad_pro).
**This is a partially routed prototype draft, not a fabrication release.**

The [new modular-panel brief](MODULAR_PANEL_PLAN.md) records the user's
125/80/44 mm shaped PCB dimensions and requested detachable assembly panel.
The existing board below remains the historical 60 x 95 mm baseline. The shaped
main and wheel extraction are implemented in the modular projects; the production
panel remains on hold for stable mechanical interfaces and manufacturing closure.

## Starting geometry

The board is a provisional **60 x 95 mm**, nominal 1.6 mm (1.578 mm CAD laminate), with 3 mm corner
chamfers. Its bounds are X = 95..155 mm and Y = 100..195 mm in KiCad;
the USB/front edge is Y = 100 mm. These are layout assumptions, not dimensions
from a measured enclosure. No mounting holes or optical aperture have been cut.

All **317 motherboard footprints** are inside the outline: 273 BOM components,
43 test pads and J5 motor wire pads. The [60 mm placement pass](PLACEMENT_60MM.md)
was followed by the [separate encoder project](../encoder/README.md): U27/C62
moved to that board and J6 was added here. The input-power pass added local
output bypass C88; the U13 pass added input bypass C89 and moved C40 beside
U13 OUT. No off-board staging parts remain.
All BOM components on the motherboard remain on the front; 40 test pads are on
the back and three on the front. Pads do not require backside component assembly.

The outline was widened symmetrically from 50 to 60 mm. The USB connector,
ESP32 module and optical centre remain fixed. U35 is at X=125.5, Y=157.5mm on
F.Cu, rotation 270 degrees. Some earlier circuit groups and optical supplies
were moved to make space for the wheel driver, ADC2, brake, IMU and RGB.
The [optical placement notes](OPTICAL_PLACEMENT.md) describe the current arrangement.
The shell will be designed around the PCB and its mechanical interfaces.
Test pads and J5 are excluded from the BOM and placement export. MPN, LCSC and datasheet fields are
retained. Future schematic changes can use KiCad's **Update PCB from Schematic
(F8)**; do not import another set of footprints manually.

| Area | Initial placement |
| --- | --- |
| Front | USB-C connector, data/CC protection, Type-C detection, input eFuse, buck and J6 encoder cable header |
| Front sides | Left/right coil connectors, bridge drivers and Hall sensors |
| Left middle | Middle button, actuator storage/clamp, current monitor, ADC1 and optical supplies |
| Right middle | Actuator eFuse, wheel driver and ADC2; brake resistors along the edge |
| Centre | Provisional wheel/encoder mechanics, optical group and IMU; RGB near USB |
| Rear | ESP32, interlock, ADC2 SPI buffer, brake comparator/reference, reset/boot and test access |

Drawings on **Dwgs.User** identify the reserved areas. The wheel rectangle
prohibits copper, vias, pads and footprints on all four copper layers. The optical
rule area now follows the proposed aperture at X=121.20..129.80,
Y=148.68..165.94mm and prohibits copper, vias and pads on all four layers.
Footprints may straddle that aperture, as U35 must; review physical body clearance
separately. A 20 x 22mm drawing reserves space below for the lens assembly.
These are planning envelopes, not verified clearances for the GB1806,
shaft, bearings, encoder, lens or sensor. The complete wheel assembly may need
more area or a separate board. Hall positions and coil connector locations must
move to match the measured paddle/magnet assembly; their present proximity does
not establish acceptable magnetic crosstalk.

The ESP32 antenna faces the rear. Its library keepout is retained on all copper
layers; preserve the clearance outside the board in the enclosure too. The
ESP32-S3-MINI-1 uses KiCad's shared **ESP32-S2-MINI-1** land pattern. See
[Espressif's module layout guidance](https://docs.espressif.com/projects/esp-hardware-design-guidelines/en/latest/esp32s3/pcb-layout-design.html)
and the [module datasheet, v1.7](https://documentation.espressif.com/esp32-s3-mini-1_mini-1u_datasheet_en.html).

## Draft routing setup

Four copper layers are enabled. The intended allocation is front components and
signals, In1 ground reference, In2 power/slow signals, and back signals/test pads.
The [buck routing pass](BUCK_LAYOUT.md) is now followed by the
[input-power and source-selection subset](INPUT_POWER_LAYOUT.md), including
USB-to-U12 and U12-to-buck power copper and a filled In1 ground plane. The
[Type-C pass](TYPEC_LAYOUT.md) connects detector inputs and source-logic supplies.
The [U13 pass](ACTUATOR_POWER_LAYOUT.md) adds its local feed, bypass and protection copper.
The [control pass](ACTUATOR_CONTROL_LAYOUT.md) connects enable fanout and power-fault/reset wiring.
The [distribution pass](ACTUATOR_DISTRIBUTION_LAYOUT.md) connects actuator feeds,
driver/brake current paths, sensing and remaining interlocks. U21 now requires
four filled and capped vias in its exposed pad. The [USB pass](USB_LAYOUT.md)
adds two more at U1/C32, compacts U12 ILM and routes the data pair with a
checked continuous In1 reference. Include all six component-land vias in the quote.
[JLC041611-2116](STACKUP.md) is selected with 1 oz outer/inner copper;
board-wide routing and thermal review remain open.

The project starts with 0.15 mm net clearance, a 0.127 mm absolute minimum,
0.25 mm default tracks, 0.60/0.30 mm through vias and 0.30 mm copper-to-edge
clearance. The four supply nets have a 0.75 mm suggested track width. These are
editor starting values: size power paths, copper and thermal vias from measured
current and temperature limits. Neck-downs and pad escapes require local review.
The USB netclass now uses the supplier-calculated 0.1466 mm width and
0.1501 mm gap for the 90-ohm target on the selected stackup. The saved USB
route/reference audits pass; manufacturer impedance acceptance and USB hardware
tests remain open. See [USB layout](USB_LAYOUT.md) and [stackup notes](STACKUP.md).

Reference designators are on the fabrication layers for placement review;
component outlines remain on silkscreen. Add a readable final silkscreen after
placement is settled. No parts require backside soldering in this draft.

## Review and next work

From the repository root:

    python hardware/kicad/export_pcb_review.py

This reads the live schematic/PCB and produces front/back SVGs, native DRC JSON
and a summary under `build/pcb-review`. The legacy-named
`placement-with-staging.svg` now has no off-board encoder parts. The
exporter accepts `--kicad-cli PATH`.
The default exit status checks placement and schematic parity; add
`--require-routed` to also fail on incomplete connectivity. Neither mode
establishes manufacturing or electrical acceptance.

Current check: **0 physical DRC violations and 0 schematic parity issues**,
without new DRC exclusions. Native connectivity counts **200 unrouted connections**;
the current DRC report also lists 200 entries. The buck, input-power/source-selection,
U13, actuator distribution, driver/brake, interlock, ILM/telemetry and USB subsets are routed.
See [USB layout and native copper checks](USB_LAYOUT.md) and the subsequent
[actuator high-current review](HIGH_CURRENT_REVIEW.md) for resistance screening,
local ground spreading and the corrected capacitor inventory.
The subsequent [analog pass](ANALOG_LAYOUT.md) connects the Hall outputs and
checks all analog nets. Correct project-aware filling resolves the fixed analog
front-reference shadows; switching proximity and other analog findings remain open.
Hall geometry is explicitly deferred, while Hall connectivity remains mandatory.
The analog/brake cleanup removes redundant track branches and adds whole-net
copper length guards. BRAKE_OUT is now 12.336 mm total copper; the 80.480 mm
BRAKE_GATE and remaining sense/phase coupling still require review.
The following control pass reroutes BTN_R_IN2 and DRV_INHC, removes redundant
command/PWM branches and clears five fixed wheel-sense proximity findings.
There are 36 fixed findings left; the strict analog review still fails.
Component placement, analog copper and high-current tracks are unchanged in
that pass, and all BOM components remain on the front.
For future refills, run `hardware/kicad/refill_pcb_zones.py` with KiCad Python
against the PCB beside its matching project/rule files, then rerun native DRC
and saved-copper checks. A scratch PCB without its project can use default
netclasses and produce different reference-plane clearances.
This checks local footprint geometry and synchronization, not board fit, operation, magnetic
separation, heat dissipation, signal integrity or enclosure fit.

1. Fit the implemented upright encoder board, its harness and the complete wheel
   assembly; allocate paddle magnets, mounting holes and connector access.
   Design the shell/base around the board and verified optical height.
2. Qualify [PMW3360 samples, SROM and optical fit](../kicad/OPTICAL_DESIGN.md).
   Optical, [IMU and RGB](../kicad/PERIPHERAL_REVIEW.md) circuits are drawn.
   The wheel/ADC2/encoder and provisional brake circuits are drawn; their
   [timing and energy measurements](../kicad/WHEEL_REVIEW.md) remain open.
3. Qualify the reviewed actuator current paths, effective decoupling and analog
   returns on hardware; measure driver/brake heating and confirm the
   filled/capped U1/C32/U21 vias. Static resistance and local ground-area checks
   now protect the saved geometry; they do not replace these measurements.
4. Route SPI, optical and remaining sensing/control; obtain USB impedance acceptance.
   Shorten circuitous control routes, add ground stitching and review return
   paths, thermal paths and test access.
5. Complete ERC/DRC and package/stencil review before exporting revision-matched
   Gerbers, drills, assembly drawings, BOM and placement files for JLCPCB.

The custom button coils remain mechanical assemblies wired to J2/J3/J4; there
are no PCB spiral actuators. No manufacturing files are provided yet. See the
[roadmap](../../docs/roadmap.md) for schematic and bench-validation gates.

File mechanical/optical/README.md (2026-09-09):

# PMW3360 / LM19-LSI mechanical starting point

The selected pair is PMW3360DM-T2QU + **LM19-LSI**. Dimensions below come from
Figures 3, 4 and 6 of the
[PixArt PMW3360 datasheet R1.50](https://datasheet.lcsc.com/datasheet/pdf/c018c3e1d470821feefadd37e2f785d5.pdf?productCode=C20612443).
They are reference dimensions, not measurements of delivered parts or approval
of the current 60x95mm motherboard outline.

Optical vertical datums

The drawing is a dimensional diagram, not an optical solid model. Z=0 is the
tracking surface. The **2.4mm nominal working height starts at the bottom of
the lens flange**, not at the PCB. The specified operating range is 2.2..2.6mm.
With the illustrated 1.6mm PCB, its top is nominally 7.40mm above the surface
and its bottom 5.80mm above it. The lens sets the sensor height; changing PCB
thickness does not authorize changing lens-to-surface spacing.

| Datum or envelope | Nominal reference |
| --- | --- |
| Lens flange bottom above tracking surface | 2.40mm; operating range 2.20..2.60mm |
| PCB top / bottom above surface | 7.40mm / 5.80mm with 1.60mm PCB |
| Chip die / package top above surface | 8.84mm / 9.81mm |
| Bottom of sensor lead frame to lens flange bottom | 6.71mm, +0.08/-0.04mm |
| Lead frame bottom to package top | 0.70mm, +/-0.05mm |
| Lens flange XY envelope | 21.15 x 18.85mm; not centered on the optical axis |
| Recommended PCB opening | 17.26 x 8.60mm, asymmetric about optical center |

The custom footprint uses the optical center as (0,0). In its top view the
mouse front points along -X. Pin 1 is (5.66,-5.35)mm; pins 1..8 run left in
1.78mm steps. Pin 9 is (-7.69,5.35)mm; pins 9..16 run right in 1.78mm steps.
Recommended finished holes are 0.70mm. The opening spans X=-8.82..8.44mm and
Y=-4.30..4.30mm. It is shown on Dwgs.User only until fit is reviewed. It is not
a standard DIP-16 footprint, nor is that opening the baseplate light aperture.

The lens drawing is PNLR-019-LSI-G8_011. Do not replace its guide posts, molded
optical surfaces, retention details or baseplate opening with the rectangular
envelope above. Obtain the matching supplier drawing/application note
PMS0122-LM19-LSI-AN before designing retention or heat staking.

The PCB-first placement now uses optical centre X=125.5, Y=157.5mm in KiCad,
30.5mm from the board's left edge and 57.5mm behind its front edge. U35 is on
F.Cu at 270 degrees so its front points toward USB (-Y). The sensor body sits
above the PCB and its lens below; do not flip the sensor to B.Cu. A conservative
20 x 22mm underside assembly envelope is drawn about this centre, allowing for
the flange's asymmetric position. This envelope is a planning guide, not a
replacement for the lens shape or a verified clearance to every part.

Provisional motherboard placement can proceed without an outer-shell model.
Before freezing the optical mounting, measure an exact sensor/lens pair, confirm
the seating relationship and lead fit, and make a 1:1 aperture coupon. Set the shell,
feet thickness/compression/wear and local PCB supports so button forces do not
change optical height. Keep feet close enough to stabilize the tracking region.
Check travel across the full working-height range and representative surfaces,
with wheel/button haptics active. Then freeze mounting holes, the baseplate
light opening and board cutout together. No supplier has confirmed samples yet.

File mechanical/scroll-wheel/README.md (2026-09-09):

# Scroll-wheel assembly

Reserve editable wheel/shaft/mount CAD here. Integrate the encoder-free GB1806,
bearings and a dedicated diametric MA735 magnet. Define air gap, concentricity,
shaft retention, clearance and middle-button load path. Verify rotor and button
magnetic fields do not corrupt angle sensing. Motor dimensions and pole-pair
count from the notes require confirmation against the purchased variant.

The selected architecture uses a [small upright encoder board](ENCODER_BOARD.md)
for U27/C62, facing a shaft-end magnet. The motherboard is provisionally
60 x 95 mm. The [14 x 18 mm encoder PCB and JST harness](../../hardware/encoder/README.md)
are implemented; mounting, cable fit and full wheel fit remain to be verified.

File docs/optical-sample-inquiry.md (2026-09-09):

# Optical sample procurement draft

Prepared 2026-09-09. **Not sent; no order or supplier commitment.**
Candidate: [Yushakobo A080040-01-1](https://shop.yushakobo.jp/en/products/11274),
PMW3360DM-T2QU / LM19-LSI. Select the LM19-LSI option explicitly.

## Listing refresh, 2026-09-09

The selected A080040-01-1 PMW3360DM-T2QU / LM19-LSI option displayed
35 units in stock and JPY 3,190 including tax at the retailer link above.
The retailer states that it sources through an authorized domestic distributor.
These are listing observations, not a reservation or independent provenance
verification. Croatia shipping, final landed price, sample fit and SROM rights
remain unconfirmed. No inquiry has been sent and no parts have been ordered.

## Supplier inquiry text

We are developing a wired mouse prototype and would like to source two
PMW3360DM-T2QU sensors with matching LM19-LSI lenses, product A080040-01-1.
Please confirm:

- Delivery to Croatia, available quantity, lead time, total price and shipping.
- Exact sensor and lens MPNs/revisions, genuine-part provenance and whether
  each sensor includes its lens and protective aperture tape.
- Matching electrical/reference documentation, current lens drawing and
  PMW3360 initialization/SROM payload, including version/checksum information
  and permission to use and redistribute it in ESP32-based firmware.
- Required soldering temperature/process, cleaning restrictions and fixture
  or seating-height instructions; availability of PMS0122-LM19-LSI-AN.
- Whether the same exact pair can be supplied for a later small production run.

## Separate assembly quote requirements

Ask JLCPCB to quote the rest of the SMT assembly with U35 customer-supplied
or excluded for post-assembly fitting. Obtain explicit acceptance for the exact
sensor, protected no-wash soldering, seating-height fixture and optical aperture
protection. Quote lens installation separately; a catalog sensor listing does
not include the lens. Supply the final board cutout and assembly drawing only
after sample fit, package review and layout completion.

## Receiving checks

Record invoice/provenance, lot markings, lens identity and any supplied firmware
terms. Inspect contamination and aperture protection. Measure leads, holes,
seating, guide posts and flange height. Validate a coupon and bench motion read
before freezing the motherboard opening or ordering assembled motherboards.

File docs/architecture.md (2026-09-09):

# V1 architecture

V1 is a wired USB mouse with three independently sensed, actively haptic buttons
and a motorized scroll wheel. Wireless operation and additional functional ICs
are outside the current feature scope; supporting power/protection circuitry
is drawn; remaining peripheral circuitry and physical validation are open.

| Requirement | Target / interpretation |
| --- | --- |
| Cursor | PMW3360DM-T2QU + LM19-LSI optical X/Y tracking |
| Supplementary motion | ICM-42688-P lift/orientation experiments; not the cursor source |
| Buttons | Left, middle, right; magnetic position sensing without switch contacts |
| Button return | Elastic paddle/flexure supplies passive return with coil current off |
| Button feedback | Custom moving magnet and stationary wound coil; transient bidirectional effects with position/current feedback |
| Scroll | MA735 absolute angle, programmable BLDC detents/torque |
| Host connection | USB 2.0 Full-Speed HID, target 1 ms report interval |
| Power | 5 V USB-C, source-aware limits; intended 3 A advertised source for full effects |
| Indicator | One RGB status/profile LED |
| Recovery | Reset, boot, programming/test access |

```mermaid
flowchart TD
    PC[PC] --> Hub[Externally powered Type-C hub or adapter]
    Hub -->|USB data| MCU[ESP32-S3]
    Hub -->|5 V VBUS| Power[Protected power distribution]
    Power --> Logic[3.3 V logic supply]
    Logic --> MCU
    Logic --> Optical[PMW3360 and switched 3.3 V / local 1.9 V supplies]
    Optical -->|X/Y| MCU
    IMU[ICM-42688-P] --> MCU
    Hall[Three TMAG5253 sensors] --> ADC[ADS7038 #1]
    ADC --> MCU
    MCU --> Buttons[Three DRV8231A drivers and custom wound coils]
    Buttons -->|Current feedback| ADC
    Buttons -->|Magnetic force| Paddles[Elastic paddles with actuator magnets]
    Paddles -->|Separate sensing magnets| Hall
    MCU --> Wheel[DRV8316R and GB1806]
    Angle[MA735 wheel angle] --> MCU
    Wheel -->|Phase current| ADC2[ADS7038 #2, dedicated SPI3]
    ADC2 --> MCU
    Power --> Buttons
    Power --> Wheel
    CC[TUSB320 Type-C current detection] --> MCU
```

The button direction was revised on 2026-09-08: custom moving-magnet actuators
replace the industrial linear actuators, and elastic paddles provide return
instead of an active holding force or a dedicated magnetic return arrangement.
Each paddle carries separate sensing and actuator magnets. The stationary wound
coil adds bounded press/release effects; it is not required to support the paddle
continuously. Zero commanded coil current is the normal resting/held state after
an effect ends; driver and sensing electronics still consume power.

Retain bidirectional DRV8231A drive for resistance and brief assistance during
snap-through. A single-transistor driver, vibration exciter, and LRA are not the
selected V1 implementation. The smaller dimensions and 0.2-0.4 N actuator-force
target in the [button plan](../mechanical/button-mechanisms/README.md) are
unvalidated prototype targets. Measure force versus position and current before
freezing the coil, magnetic circuit, current limits, or PCB placement.

The mouse is a USB device. An external powered hub is a separate accessory, not
an assumption that every powered downstream port provides 3 A. A custom adapter
is optional future work; its controller, power switch, and Type-C source behavior
need their own design. USB2512B in the notes is only a candidate.

The [GPIO/resource allocation](interfaces.md) uses SPI2 for buttons/system ADC,
optical, IMU, angle and driver configuration; SPI3 is dedicated to the second
wheel ADC. Wheel control uses 3-PWM and RGB uses one RMT data pin. Validate
transaction latency, signal levels and sampling windows before routing. Loop
rates, current limits, USB identifiers, firmware framework and host protocol
still require implementation decisions and measurement.

Actuators must remain disabled until power capability, calibration, fault handling,
and limits are valid. Optical tracking and ordinary HID operation should remain
usable with haptics disabled.

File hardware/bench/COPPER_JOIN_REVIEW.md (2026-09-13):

# Complete element/contact review — current revision

Final result: 14 native/electrical acceptance checks, 62 bench/contact tests,
60 modular tests, and 47,426 exported contact checks PASS. Whole-copper
comparison covers 17,819 element/layer instances; no additional repair was required.

The latest review found **no additional copper repair required**. The three
marked Main U16 pad entries (6, 10, 13) already extend to pad centres in the
current source boards. Their screenshot showed earlier geometry. A dedicated
U16 regression and regenerated close-up now make this verifiable.

`contact_review.py` inventories every trace, pad and via on each copper layer,
including saved zone contacts. It distinguishes schematic NC pads, unused via
layers and unused layers of plated pads. An unclassified isolated element is a
failure; these classifications do not replace native DRC/parity/connectivity.
Each distinct zone-contact patch is checked locally, without another contact
elsewhere rescuing it. Routed joins retain the existing narrower-conductor
width minus 0.002 mm. Thermal entries use the actual configured spoke width.
Generic solid land-to-zone entries use the existing 0.15 mm zone feature rule,
limited by the land width; this is a geometry screen, not a power-current
rating. Existing strict power and return-path checks remain mandatory.

The Main ground trace near (57.05, 24.55) enters a thermally relieved pad;
it must retain that pad's intentional thermal geometry. Wheel U24.12 has a
pad-local filled island extending about 0.05 mm around the pad. The inventory
explicitly does not count this island as an external plane return; its via and
other-layer connection are checked independently. Neither detail requires
bridging a clearance or widening unrelated copper.

The exported-copper checker now compares **all source copper on all layers**
with the parsed Gerbers (0.0005 mm polygon/export tolerance), and repeats all
enumerated contact witnesses, in addition to the 2,457 historical repair
witnesses. Non-plated USB locating holes are excluded from the expected copper
model. Separate Excellon, plated-hole, via-fill and layer-transform checks
remain required. No source board, pad/via position, drill, route width, USB
geometry, component placement, board outline or stencil aperture was changed
in this pass.

The gallery displays each source hash and uses revision-qualified image links.
See `Main-U16-pad-via.png` for the reported examples. Current validation results
are in `package/evidence/acceptance.json`, `contact-inventory.json`,
`gerber-joins.json` and `full-contact-*.log`. The revised package is local only;
the submitted 2026-09-12 archive remains byte-for-byte unchanged.

## Previous repair pass (historical)

# Latest full-entry review

Final validation: 56 bench/panel/stencil/contact tests and 60 modular tests
pass, with 13 native/electrical/contact acceptance checks and 2,457 current
exported-Gerber width witnesses. Logs are in package/evidence/full-entry-*.log.

All layers on Main, Wheel and Encoder now pass the expanded contact audit.
It checks near-tangent trace caps (including up to 0.002 mm polygon gaps),
trace-to-pad/via entries, and direct pad/via contacts without a trace.
The required corridor is the narrower participating conductor minus 0.002 mm.
Where a narrower trace already supplies a local path between lands, its width
sets that path requirement; incidental overlap does not require widening it
to the whole pad diameter. Intentional zone thermal reliefs are preserved.

The Main B.Cu example is ENC_MOSI_LOCAL at (20.8,32.2) mm. Its 0.20 mm
rounded ends overlapped by about 1 nm. Polygon approximation made the contact
look disjoint, so the old intersection-only candidate search missed it. A
shared-centerline link now closes it at the original 0.20 mm width.

This pass repaired 303 Main contact observations (two observations share one
new bridge) and four Wheel via entries. Encoder needed no copper repair.
Original supply tracks retain their widths. Four added Main entries use the
existing narrower via-land diameter (0.45/0.60 mm) to preserve clearance;
no original power trace was narrowed. A later 0.60 mm entry bridges two
observations of the same PWR_5V via contact.

The Wheel F.Cu diamond was a redundant ADC2_MISO_LOCAL loop. Thirteen local
segments were removed, one incoming segment shortened, and one 0.15 mm link
added. The replacement runs through (36.8,8.45) -> (37.1,8.75) -> (34.15,11.7).
No pad/via was attached to the removed loop. Its two obsolete historical
Gerber witnesses are retained under superseded_loop_witnesses in the manifest.

All native DRC/unrouted/parity and 13 electrical/contact checks pass. The
negative tests now exercise the actual one-nanometre case, a one-micron gap,
a thin pad entry, land-only contact, and the removed Wheel loop. This extends
the earlier test coverage instead of treating connectivity as width acceptance.
Pad/via locations, drills, board outlines, USB segments and fixture geometry
were compared with the pre-pass boards and are unchanged. Manufacturing files
are regenerated locally; the submitted archive remains unchanged.

Close-ups: copper-images/Main-encoder-MOSI.png and Wheel-ADC2-MISO.png.
The following sections retain the previous review history and checkpoint counts.

---

# Copper joins and panel support — 2026-09-13

Working Rev-A bench revision; revised CAM package prepared locally, not submitted.
The exact 2026-09-12 submitted archive remains unchanged.

## Copper

Main has 2,105 repaired contacts and Wheel has 45. Encoder required no repair.
The audit covers straight-track contacts on every populated copper layer,
including ACT_5V, VBUS, GND and control routes. It checks the saved copper union,
not native connectivity alone. Original widths are retained. Pads, vias,
footprint positions and all 152 Main USB segments are unchanged.

Repairs connect track centerlines. Interior landings are split into explicit
vertices; three unused tails of at most 0.05 mm were removed. Two ACT_5V repairs on In2
use short local bends to preserve SPI_MOSI clearance. No arbitrary copper blobs
or thermal-relief changes were introduced.

A required-width corridor uses the narrower adjoining width minus 0.002 mm.
Where an existing corner supplies an alternative local path, erosion by half
that required width must leave both endpoints connected within a local window.
A long board-wide electrical connection cannot satisfy that local test.
All three final source audits have zero findings. The independent Gerber reader
applies dark/clear primitives in order and checks every repair corridor against
exported panel copper. See `evidence/gerber-joins.json` in the generated package.
`copper-join-repairs.json` records coordinates, widths, bends and source hashes.

## Tabs and fixture

Main's right tab is at local (80,68), panel (87,75) mm. Encoder's replacement
top tab is at local (53,50), panel (95,80) mm. The other eight tabs, 5 mm tab
width, perforations, unit outlines, panel dimensions and spacing are retained.
Each tab must intersect both its intended board and frame across its full
5 mm width; global panel connectivity cannot replace this check.
The Main right fixture saddle moves to fixture (105,88) mm. Printable solids,
assembly drawings and clearance evidence are regenerated.

## Verification and boundaries

Native DRC, unrouted and schematic parity are zero on all units; panel DRC is
zero. Existing strict electrical acceptance limits are unchanged. Regression
negatives cover thin/broken joins, wrong-net bridges, dangling/corner-only tabs
and narrowed tabs. Package source, layer, copper and drill transforms remain
checked by the existing panel tests. These are CAD checks, not hardware tests.

Reproduce: build_panel.py; export_fixture_interfaces.py; build_fixture.py;
verify_bench.py; export_bench.py; bench/modular unittest suites;
export_copper_images.ps1. The Gerber reader needs gerbonara installed under
build/gerber-python. Keep the submitted archive separate from regenerated files.

Validation logs: package/evidence/join-repair-*.log. The 47-test bench suite and
60-test modular suite pass; the final focused join suite passes all 10 tests,
including two added local-bend/distant-bypass cases. Final Gerber witnesses:
615 F.Cu, 601 In2.Cu and 934 B.Cu; no In1 repair was needed.

Visual inspection covered the pictured corner beside the OPT_RESET_N via near
Main (51.05,66.75), both replacement tabs and the revised fixture overview.
See the copper-images gallery for labelled close-ups.

## U6.6 via entry follow-up

The original track-to-track audit did not cover the narrow entry to the
BTN_R_COIL_P via at Main (64.9,45.05). A 0.30 mm track now connects the
existing endpoint (64.5,45.25) to the via center. The via and pad stay fixed.
A negative test reproduces the old thin overlap; a board regression checks
the full-width repaired entry. This adds one Gerber witness (2,151 total).
It does not claim a completed board-wide pad/via-entry audit.

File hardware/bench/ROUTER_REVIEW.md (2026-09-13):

# Rev-A panel routing review

Final validation: 71 bench/panel/router tests, 60 modular tests and 14
native/electrical checks PASS. Exported routing has eight closed openings;
minimum perforation-to-slot web is 0.4385236 mm. All 40 retained corner
patches were inspected. Source boards and stencil aperture geometry are
unchanged. See router-images/index.html for the corner review gallery.

Design basis: nominal 2.00 mm router, 1.00 mm internal radius, 0.002 mm
geometric verification tolerance. Factory cutter selection and CAM acceptance
remain pending. These verification paths are not machine G-code.

All eight openings are generated as cutter envelopes, with rounded tab ends.
Wide waste pockets include clearing paths in the coverage model. Exactly
2 mm corridors retain a 0.001 mm-wide numerical centre corridor instead of
being lost by polygon erosion. The nominal 2 mm sweep is checked within
0.002 mm; published removal contours are clipped to the original permitted
removal region. Contours are simplified by at most 0.00025 mm and snapped
to KiCad's grid before serialization; the final Gerber must still pass the
0.002 mm sweep comparison and have exactly closed, non-branching contours.
All individual source-board outlines remain unchanged.

The frame's curved offsets now use finer arc tessellation. The router pass
also corrects a tight transition near the encoder opening. Retained material
is permitted only near convex corners/curves; a narrow passage or inaccessible
pocket cannot silently disappear. Convex external board corners remain valid.

Panel size, board positions/outlines, tab centres, fifty 0.6 mm perforations,
four tooling holes and all functional copper remain unchanged. Tabs are checked
against the actual routed material for a full 5 mm bridge into board and frame,
with at least 0.2 mm of material from perforation edges to routing. Hole-to-hole
webs remain 0.3 mm. Factory routing tolerances still require CAM confirmation.

The panel manifest records the cutter paths, retained corner patches and tab
web measurements. Independent mechanical-Gerber validation is recorded in
package/evidence/router-gerber.json. Source hashes, electrical acceptance,
fixture validation and test logs accompany the local package. Bench fixtures
support individual depanelled boards; remove tab remnants to the documented
unit outline before seating boards in the saddles.

No stencil aperture or source board changed. The submitted 2026-09-12 archive
is preserved separately. This package is local and unsubmitted.

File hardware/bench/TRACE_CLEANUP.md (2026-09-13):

# Copper trace cleanup — 2026-09-13

Simplified Main, Wheel and Encoder copper polylines on every routed layer.
The search handles shared endpoints, nanometre coordinate rounding, and
mutually nearest forward-facing ends with overlapping copper caps. It keeps
net/layer/width transitions, branch vertices, pad and via positions fixed.
Simplified centerlines stay within 0.05 mm of the original run, including the
small cap-overlap joins. Existing USB pair copper is unchanged.

Native DRC rejected some candidate shortcuts; their original chains were
restored. Main VBUS_USB, ACT_5V and CS_PAW were retained after the initial
strict checks exposed power-path screening and reference-coverage regressions.
No electrical acceptance limits were relaxed. This is a clearance-constrained
cleanup, not a claim that every remaining short segment can be removed.

| Board | Accepted runs | Original segments in those runs | Replacement segments |
|---|---:|---:|---:|
| Main | 1,572 | 8,627 | 1,572 |
| Wheel | 358 | 3,308 | 358 |
| Encoder | 5 | 19 | 5 |

The polyline edits remove **10,019 track segments**. One additional zero-length
track inside an unchanged +3V3 via was removed, for **10,020 fewer segments**.
Pads, vias, components, board outlines,
trace widths and net assignments remain unchanged. Native connectivity, physical
DRC and schematic parity pass on each board. The strict analog, USB/reference/ESD,
power, interlock and signal-return checks also pass.

The Main total includes one explicit local repair of the screenshot's CC_OUT1
run: 21 short segments between R26 and the diagonal exit were replaced with
one 0.15 mm trace from (56.325, 31.100) to (57.350, 34.500) mm. This manual
pad-to-exit shortcut is separate from the automatic 0.05 mm corridor rule and
passes the same native and electrical checks.

`straighten_tracks.py` implements the cleanup and rolls back candidates that
fail native DRC. `test_straighten_tracks.py` covers grid runs, overlapping and
separated caps, width transitions, branch points, corners and protected USB.
Re-run the full electrical checks separately after using the tool; its native
DRC result alone is not full electrical acceptance.

Updated images are in `copper-images/index.html`; the vector SVGs are preferable
for detailed inspection. The known unsupported panel tabs are not part of this
trace edit and remain unresolved. No replacement package has been sent to JLC.
The frozen 2026-09-12 submitted archive is preserved under `submissions/`.

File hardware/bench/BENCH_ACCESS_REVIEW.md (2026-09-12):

# Bench access and local return review

2026-09-12. This closes a source-geometry review, not physical fixture assembly.
No board holes, Hall locations or final-shell datums are changed.

- Main L1/C2 close-up: the switch exits directly from U2 to L1 on F.Cu;
  C1 and the exposed-pad ground exits stay local. C2 retains its ground stub
  and nearby via. The changed output connection remains wide. Saved In1 is
  continuous under the local signals. Native DRC and electrical regressions
  remain the quantitative acceptance checks.
- `package/thermal-return-inventory.csv` records ground pads and local vias
  for the regulator, eFuses, bridges, wheel driver, brake MOSFET/resistors and
  encoder. Every checked device ground pad reaches saved In1. Via counts alone
  are not thermal acceptance: U13 has one GND via within 3 mm and Q5 has none
  within that radius, so their connected copper spreading and measured heating
  must be evaluated during limited-current operation. No current limit is raised.
- `package/probe-access.csv` enumerates test pads by side and coordinates, with
  nearby ground test points and a 0.5 mm probe-tip screening envelope. Wheel
  **TP34 is obstructed by C90**; use the accessible J11 pin 1 for ACT_5V and
  pin 2 for its return with a secured, insulated test lead. Do not reach beneath
  C90 with a loose powered probe. Bottom test pads require tilting/removing the
  carrier. Prefer a short local ground spring for switching measurements;
  the nearest named ground pad is not automatically an adequate HF return.
- `support-clearances.csv` locates eight tab-adjacent saddles and two upright
  encoder clips in unit coordinates. It checks 5 mm saddle / 6 mm encoder-clip
  widths and 0.3 mm deep underside contact strips against
  exposed pads. Use nonconductive saddles and removable clamps; inspect top-side
  caps, mask, vias and real component envelopes before tightening.
- The motor/encoder carrier remains in the fixture's 100 x 100 mm area. Start
  with the projected encoder connector near base (150,60) mm, keep its cable
  route <=120 mm before slack/insertion allowance and use the selected 150 mm
  harness. The shorter historical 50 mm encoder lead is not the bench harness.
- Main-Wheel power uses 150 mm paired AWG22. J8/J9 use 150 mm AWG28 ribbon,
  fanned to the numbered solder lands. Fixture clamps grip insulation and
  leave slack at joints. There are no internal latches or FFC stiffeners.
  All 86 lands are also recorded as probe-access locations with nearby ground;
  a soldered wire may require approaching a land from below. USB/SPI probing
  uses compact existing lands, not added wire-loop test points.
- Button harnesses are 200 mm paired AWG24 leads to independent fixtures.
  Keep experimental coils/motor away from the fixed-magnet levers until interference
  is measured. No final actuator gap, paddle motion or motor bolt pattern is
  inferred from a provisional drawing.
- Set the optical slider from the confirmed lens drawing; the adjustable base
  height is not the optical working distance. Ploopy identity and physical lens
  retention remain open. Protect the aperture and keep the slider opening clear.

The generated connector pin views, copper close-ups and full panel/placement
views accompany this review. Planes and returns are checked electrically as
well as rendered; screenshots do not establish impedance or ADC accuracy.
Before combined effects, record local temperatures, rail droop, ADC noise,
brake response and wire/joint voltage drop with secured motor and magnets.

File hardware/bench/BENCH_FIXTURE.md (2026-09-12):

# Adjustable bench fixture

Rev-A electronics test arrangement, not an ergonomic shell. Dimensions are mm.
Use the [1:1 fixture drawing](bench-fixture.svg) as an assembly layout, not as
a drill template for the PCBs. No motherboard or daughterboard holes are added.

## Support and adjustment

Print the editable parts in `mechanical/bench/build_fixture.py` in PETG.
Use four 125 × 130 × 6 mm base tiles to form a 250 × 260 mm base with a 10 mm accessory-hole grid, except
within the optical slider window. Fit removable edge saddles to M3 slots in
the base; saddle lips engage no more than 0.3 mm of the board underside.
Support Main at the four clear tab-adjacent sites recorded in the panel
manifest, then inspect both faces before tightening. Nylon clamping caps bear
only on clear board edges, never on components or test pads. Wheel uses its
four clear tab-adjacent sites; Encoder uses the two reserved side clips.

Main top-view origin is (25,20), component side up. Wheel origin is (60.5,160),
component side up, so the signal headers align in X. Use threaded standoffs
and locking nuts to adjust both board undersides from 15 to 35 mm above the
base. Keep at least 5 mm clear beneath non-optical components and permit
removing the base or tilting the carrier for bottom-side probing. All board
supports are removable: these coordinates do not freeze mouse-shell mounts.

Use a 150 mm 30-way AWG28 ribbon between the new J8/J9 solder arrays, with
printed clamps attached to the fixture. Route the ribbon clear of components
and leave slack at both ends. Follow the selected wire's bend limit; no FFC
stiffener or exposed-contact tolerance applies. Begin digital bring-up at
reduced clock rates and measure at both ends before accepting the final SPI3
schedule. Preserve J8.N to J9.(31-N) mapping and every ground conductor.

## Optical slider

Reserve a 50 x 60 opening in the base centred beneath Main's optical datum
(65.5,92.5). A removable, opaque matte target rides on two external slide rails
below the retained LM19-LSI lens. Provide 0-15 mm target-height adjustment in
0.1 mm steps with screws and shims. Set the final lens/target distance from the
received lens and its drawing; the adjustment range is not a claimed optical
operating range. Add a scale to measure target motion. The lens clip contacts
its retention shoulders only and keeps the optical surfaces and sensor
aperture free of adhesive. No PCB hole is inferred from the copper keepout.

## Motor, encoder and button experiments

Reserve the upper-right 100 x 100 base area for an independent slotted motor
bracket. Attach only to the stator mounting pattern of the exact received
GB1806 variant. The supplier provides a [motor drawing](https://islandcloud.co/link/69c5eb717e87e6e5cd073cc6/5299e636-5e71-45ad-96e0-71a6370926ea),
but the motor-only stock and purchased variant are not yet verified. Therefore
the bolt adapter is explicitly unfrozen; do not clamp the rotating bell.

Use the 150 mm AWG28 soldered encoder harness (the former 50 mm target
is not the bench cable). Start with its connector projected near base
(150,60) mm and keep the routed cable span at most 120 mm before slack.
Use an independently adjustable upright Encoder carrier, with axial slide,
height adjustment and tip/tilt shims. Centre U27 on the shaft magnet and set
the gap by the MA735 field indication and magnet specification. Mount the
encoder magnet mechanically before rotation; do not run an unsecured magnet.
Keep this magnet and the motor away from Hall experiments until interference
has been measured.
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

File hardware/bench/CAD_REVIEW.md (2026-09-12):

# Bench panel review evidence

Review snapshot: 2026-09-12, KiCad 10.0.6. **Pending supplier/CAM approval.**

Main L1 now uses the reviewed Bourns pattern and local routing described in
L1_REVIEW.md. Main/Wheel/Encoder now have soldered-wire arrays with local routing repairs. The derived panel
has been rebuilt from the individual boards.

`package/evidence/acceptance.json` records exact source/panel hashes and native
DRC/connectivity/parity plus strict Main analog, routing, USB/ESD, power,
interlocks and Wheel electrical checks. The modular and bench regression logs
include negative checks for wrong L1 lands and underprinted Hall paste.
Read the generated records for current results, not a historical count.
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

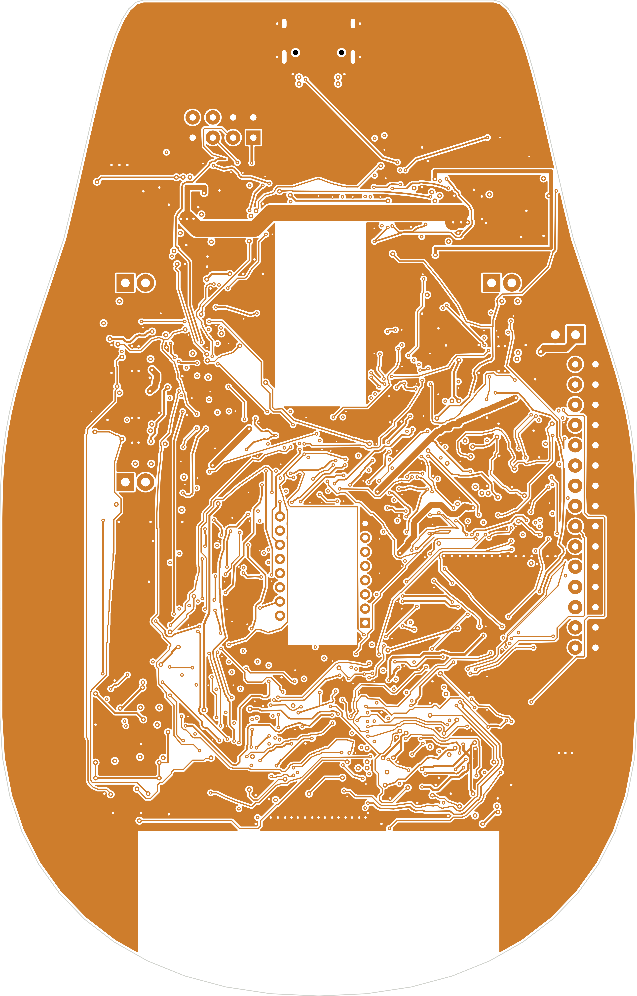
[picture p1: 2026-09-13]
hardware/bench/copper-images/Main-In2.Cu.png

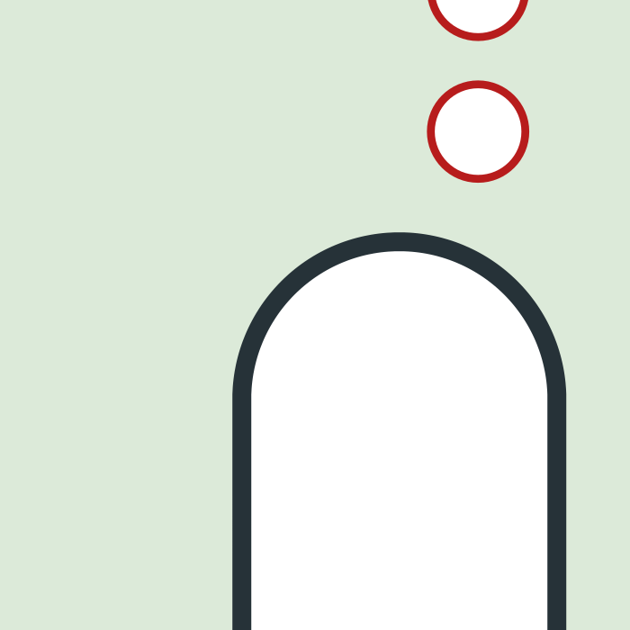
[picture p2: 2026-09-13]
hardware/bench/router-images/corner-11.png

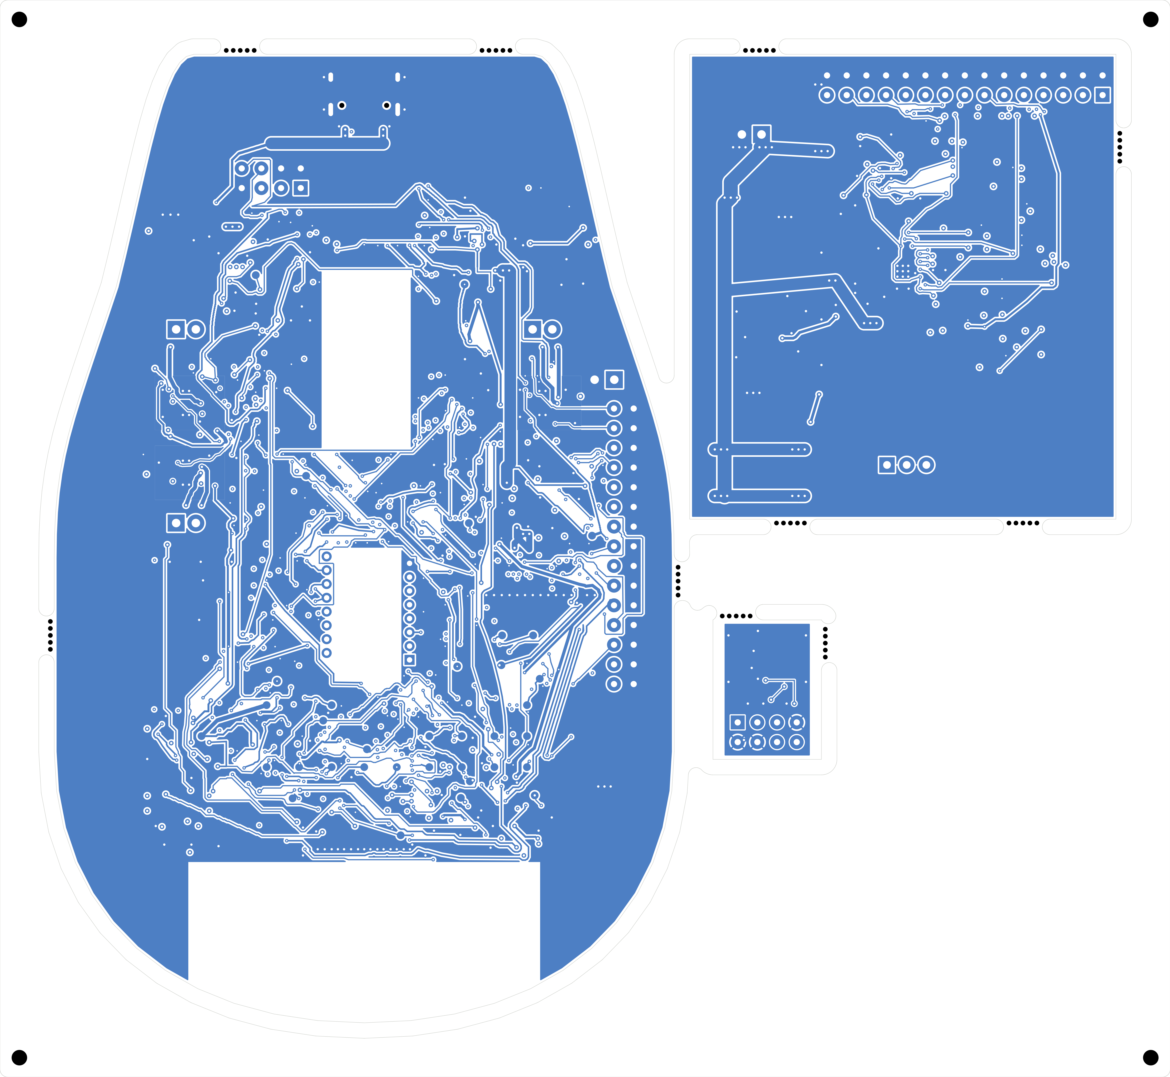
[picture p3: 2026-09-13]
hardware/bench/copper-images/Panel-B.Cu.png

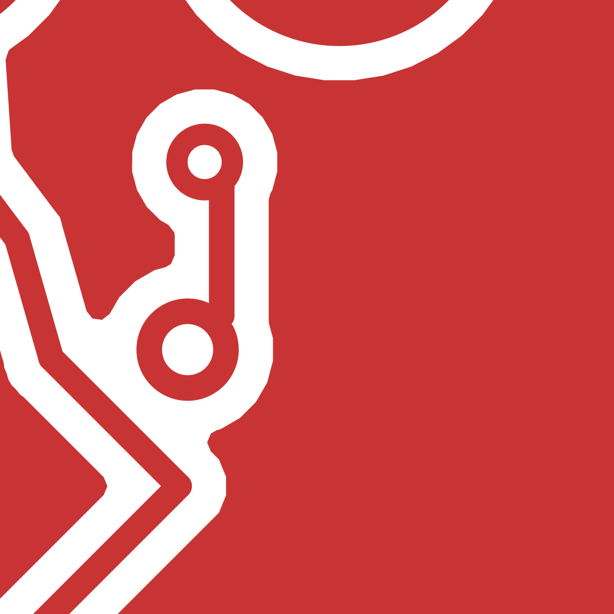
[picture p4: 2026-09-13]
hardware/bench/copper-images/Wheel-ADC2-MISO.png

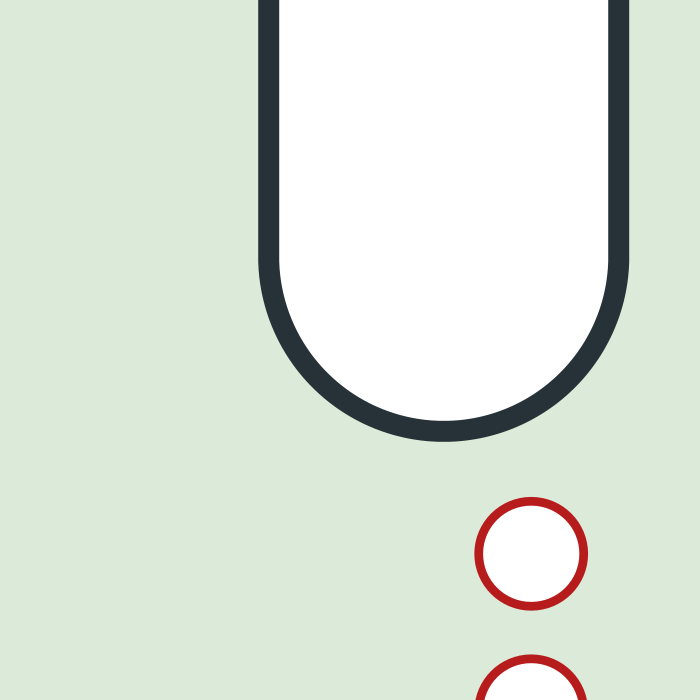
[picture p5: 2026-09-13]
hardware/bench/router-images/corner-02.png

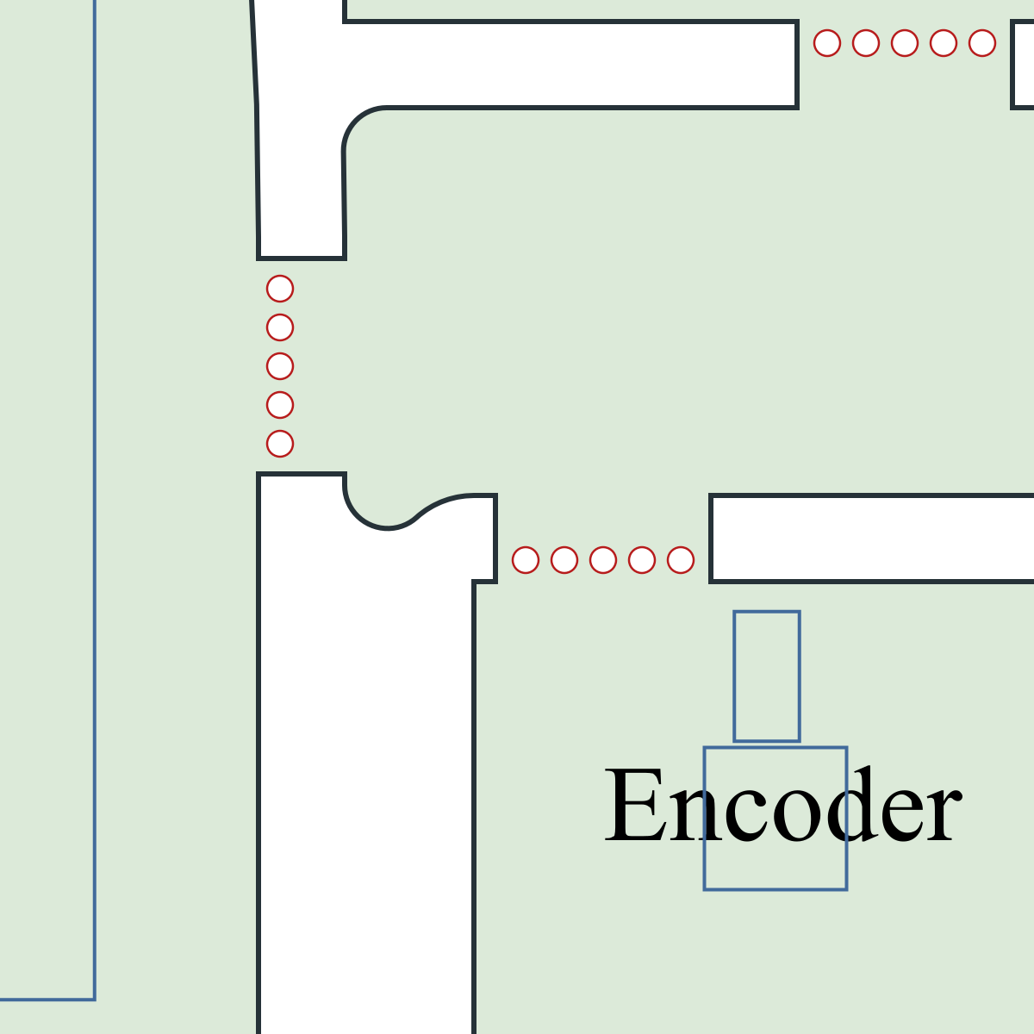
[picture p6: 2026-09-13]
hardware/bench/package/copper-review/Panel-relocated-tabs.png

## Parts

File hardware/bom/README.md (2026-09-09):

# Preliminary V1 component inventory

Planning inventory updated for the elastic-paddle/custom-coil direction selected
on 2026-09-08; not a purchasing or assembly BOM. `ideas.md` is historical.
Quantities are per mouse; alternatives are not additive. Confirm exact orderable
parts, packages, footprints, ratings and availability before procurement.

The [KiCad starter BOM](../kicad/README.md) is the source of truth for circuits
already drawn: revision 0.7 has 272 component instances with complete MPN,
catalog ID and footprint fields. The broader inventory below also includes
subsystems that have not been implemented. See [sourcing evidence](../kicad/SOURCING.md).

| Qty | Candidate | Purpose / unresolved detail |
| --- | --- | --- |
| 1 | ESP32-S3-MINI-1-N8 | GPIO/resource allocation recorded; firmware timing validation pending |
| 1 | PMW3360DM-T2QU | Optical X/Y tracking; U35, sample/SROM and assembly acceptance pending |
| 1 | LM19-LSI | Selected optical lens; reference stack documented, sample fit pending |
| 1 | TLV75519PDBVR | Local optical 1.9V LDO, U36 |
| 1 | ICM-42688-P | Supplementary accelerometer/gyro |
| 3 | TMAG5253BA2 | Left, middle and right analog Hall sensing |
| 3 | Axial NdFeB sensing magnet, TBD | Separate button position magnets; dimensions/grade set by Hall gap/range |
| 2 | ADS7038 | Both drawn: ADC1 for buttons/system; ADC2 phase currents on dedicated SPI3 |
| 3 | Custom stationary wound-copper coil | One per moving-magnet button actuator; prototype OD 6-8 mm, height 2-4 mm; winding TBD |
| 3 | N52 actuator magnet, prototype diameter 4-5 mm x 1.5-2 mm | Moves with paddle; separate from sensing magnet; size/grade not frozen |
| 3 | Printed coil former/mount | Stationary coil support; integrated or separate bobbin TBD |
| 0-3 | Soft-steel yoke/back iron, experimental | Optional magnetic-circuit trial; geometry and effect on passive return TBD |
| 3 | Elastic paddle/flexure assembly | Passive return, mechanical stops and magnet mounts; replaceable-part design target |
| 3 | DRV8231ADSGR | Bidirectional coil drivers with current feedback/regulation; C5139865 |
| 1 | MA735GGU-P | Drawn as U27, C17233427; magnetic alignment and filtering need validation |
| 1 | Diametric magnet, TBD | Dedicated coaxial encoder magnet |
| 1 | SteadyWin/TSL GB1806 (PM1806), no encoder | Scroll motor; verify exact winding and variant |
| 1 | DRV8316RRGFR | Drawn as U21, C5218861; gated 3-PWM with analog current outputs |
| 5 | SN74LVC125APWR | Wheel SPI isolation U24–U26/U29 and optical SPI/reset U37 |
| 1 | TPS22919DCKR | Switched encoder supply, U28 |
| 1 set | TLV1811DBVR, LM4040AIM3-2.5/NOPB, AO3400A and four 47 ohm / 2 W resistors | Autonomous prototype brake; measured energy/thermal limits remain open |
| 1 | SK6805-EC15 | Single-data-pin RGB, D5; RMT data on GPIO45 |
| 1 set | TPS7A2450DBVR + SN74LV1T34DBVR | RGB supply/data interface, U33/U34 |
| 1 | TPS62162DSGR | Selected fixed 3.3 V buck; C40256 |
| 1 | TYPE-C-31-M-12 | Data and VBUS; C165948 |
| 0 | External CC Rd resistors | TUSB320 integrates Rd; do not populate extra parallel terminations |
| 1 | TUSB320LAIRWBR | CC sink/current detector; C132554; GPIO mode |
| 1 | TPD2EUSB30DRTR | USB data ESD protection; C97502 |
| 2 | 33 ohm USB series resistors | Draft value per ESP32 implementation |
| 1 | TS-1088-AR02016 reset/EN button | Recovery; C720477 |
| 1 | TS-1088-AR02016 boot button | Download-mode recovery; C720477 |
| 1 set | Programming/test pads | 3V3, GND, EN, GPIO0, UART and measurements |
| TBD | Decoupling and bulk capacitors | Device-specific, logic and driver transients |
| TBD | Pull-ups/pull-downs | Boot, control and fault states |
| 1 set | SWPA4020S3R3MT and local output capacitors | 3.3 uH filter and 30 uF nominal capacitance; see KiCad BOM |
| 1 set | Optical supply/isolation and passives | TPS22918 U38, SN74LVC1G125 U39 and sheet 16/17 passives; see optical design |
| TBD | Current-setting/scaling/filter components | DRV8231A IPROPI/VREF and wheel feedback |
| 1 set | TPS259470LRPWR x2, TVS clamps, TLV9001 and passives | Input/actuator protection and telemetry; see power review |
| 3 | B2B-PH-SM4-TBT(LF)(SN) | Two-pin SMT coil headers; C265003; harnesses separate |
| 1 | J5 phase-wire pad group | PCB copper only; GB1806 wire gauge and strain relief remain mechanical tasks |
| TBD | Other connectors and mounting hardware | Mechanical assembly |
| 1 set | SN74LVC1G123, SN74LVC08A x4 and SN74LVC2G04 | Heartbeat timeout, source/reset qualification, sensor enable and six drive gates |

The external powered hub/adapter is not included in this mouse BOM. Do not fit
external Rd resistors in parallel with integrated Rd without checking the detector
datasheet. A complete schematic will establish reference designators and values.

The coil/magnet/former rows above describe three custom actuators; do not add a
second set of complete actuators when pricing them. There are six button magnets
(three sensing plus three actuator) and one separate wheel encoder magnet.
Custom windings and paddle/magnet assembly are separate from PCB assembly.

## Cost planning

The supplied design analysis estimates USD 2-10 per custom actuator (USD 6-30
for three), excluding its H-bridge, winding/assembly labor, tooling and development.
Its approximate USD 100-150 total electronics/electromechanics target is an
unquoted planning hypothesis, not a verified BOM total. Confirm winding fabrication,
driver package, optical sourcing, motor variant and supplier quantities before
updating the purchasing estimate. PCB fabrication/assembly, shipping and tax are
additional. See the [prototype plan](../../mechanical/button-mechanisms/README.md).

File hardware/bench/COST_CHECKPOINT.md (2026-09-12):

# Bench prototype cost checkpoint

Fabrication checked 2026-09-11; supplier delivery reviewed 2026-09-12. **Quotes only; no order submitted or payment made.**
Destination Croatia 43000. Five bare complete sets plus one 0.10 mm unframed
stencil. Components, cables and mechanisms are excluded from this first table.

| Fabrication option | PCB fabrication, EUR | Stencil, EUR | Delivered total, EUR (converted) |
|---|---:|---:|---:|
| Five three-design panels, fixed stack, no paid impedance test | 138.11 | 6.59 | 224.55 |
| Same panels, paid 90 ohm impedance service | 166.34 | 6.59 | 252.46 |
| Five each separate Main/Wheel/Encoder, fixed stack, no paid impedance test | 232.25 | 6.59 | 335.96 |

The cart displayed EUR; checkout displayed USD. Delivered figures above are
converted using the ECB 2026-09-11 rate, EUR 1 = USD 1.1592; they are not a
new EUR-denominated checkout guarantee. They include DHL Express DDP and
JLC's calculated duties/taxes. The economy panel saves about EUR 27.91 against
guaranteed impedance and EUR 111.40 against separate boards.
All options retain ENIG, filled/capped vias and the specified four-layer stack.
These historical quotes predate the soldered-wire revision and its drill/paste changes; the regenerated
files have not been uploaded or accepted by CAM in this draft-only task.
The saved separate quotes are Main Y11, Wheel Y12 and Encoder Y13. The panel
is Y10 and the shared stencil is SO12609120215.

## One population of electronics

The generated purchasing list covers 282 populated component references, grouped into
63 MPN/footprint lines. U32 is the only deliberately omitted functional IC.
Sixty-two lines retain public stock/quantity pricing observations, including L1:

| Supplier | Parts subtotal | Scope |
|---|---:|---|
| LCSC | EUR 41.67 | 51 lines; supplier multiples and inexpensive spares included |
| DigiKey | EUR 28.12 | 8 lines, including both ADCs, MA735 and three button drivers |
| Mouser | EUR 4.04 | 3 lines, including three Hall sensors and Main L1 |
| Optical sensor/lens | Separate below | Ploopy consumer candidate; exact identity remains unqualified |

These are **catalogue subtotals, not delivered component quotes**, converted
at the ECB rate above. Priced component lines total approximately EUR 73.84.
The previous sensor/lens estimate is excluded after the failed Croatia/EU
checkout check. Stock is not reserved. See `package/one-set-purchasing.csv`
for original supplier currencies, exact MPNs, quantities and evidence.

Main L1 has now been replaced in CAD by Bourns SRP4020CC-3R3M, using the
recorded Mouser Croatia price of EUR 0.671 for one, included in the historical
priced-electronics subtotal of approximately **EUR 73.84**, before supplier
freight/tax. The generated checkpoint contains 62 priced MPN lines out of 63.
These are the earlier catalogue observations, not a refreshed checkout. CODICO
business-only offers remain excluded.

Ploopy now provides a consumer import candidate: one PMW3360 sensor/optic set
plus tracked shipping to Bjelovar 43000 totals approximately **EUR 29.26**,
before import VAT and handling. The cart quoted CAD 47.01, converted at
EUR 1 = CAD 1.6064 (ECB 2026-09-11). Exact sensor suffix/lens identity still
need confirmation, so this is separate from the qualified parts subtotal.

## Required costs still unverified

- Component shipping/import taxes from the suppliers above; Ploopy's Croatia
  shipping quote is recorded, but optical identity and import charges remain open.
- Fresh stock reservation and delivered quote for L1 and the other component lines.
- AWG28 ribbon and encoder wiring, AWG22 power pair and AWG24 coil pairs:
  exact consumer products, minimum purchases and delivered EUR prices pending.
  No internal connector, housing, contact or FFC purchases remain.
- GB1806 motor: an approximately EUR 10.87 listing has contradictory availability indicators;
  it is excluded from the confirmed subtotal.
- Magnets, coil wire, flexures, bearings/shaft as needed, removable fixture
  supports and fasteners, solder paste, flux, wick and cleaning consumables.

Tools are excluded as requested. No core feature was removed to meet the
target. The **complete delivered total and gap to EUR 400 remain unknown**.
The fixed-stack economy panel is the supported fabrication choice, subject
to CAM acceptance; buying it now would precede the unresolved supplier and
bench-fit checks. Public listing evidence and the separate cost categories
are recorded in `sourcing-observations.json` and `quote-observations.json`.

The connector removal reduces the earlier priced component subtotal by about
**EUR 8.07**, before replacement wire costs. This is a recalculation from saved
observations, not a new supplier checkout. Historical economy fabrication plus
recalculated electronics plus the recorded Ploopy delivery quote sum to
**EUR 327.65**. That is an incomplete planning subtotal, not a delivered project
quote: new fabrication pricing, component freight/tax, optical import charges,
wire, motor, magnets, coils, PETG, fasteners, adhesive and consumables remain open.
Do not treat the apparent EUR 72.35 remainder to the EUR 400 target as savings.

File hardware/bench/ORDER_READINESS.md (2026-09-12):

# Rev-A bench PCB order readiness

Reviewed 2026-09-12. **Pending supplier/CAM approval; not approved to order.**
Scope: five bare three-board panels, one component population and one unframed
stencil. U32 remains DNP; all other core features are retained. Final shell and
ergonomic mechanisms are a later revision. No enquiries, orders or payments
were sent during this review; the supplier communications are drafts only.

## Completed in CAD and the review package

- Local manufacturing review is complete: corrected economy-order job metadata,
  checked actual round/slot drill outputs, and prepared a consolidated CAM
  handoff with exact settings and fill/open-hole drawings. See MANUFACTURING_REVIEW.md.
- Main L1 changed to Bourns SRP4020CC-3R3M with manufacturer lands, a local
  rotation/placement adjustment and a 0.15 mm C2 move. Schematics, PCB and
  purchasing identity agree; original LCSC identity removed. See L1_REVIEW.md.
- Main, Wheel and Encoder remain four-layer, routed and individually checked
  for zero unrouted, physical DRC and schematic-parity findings. Panel/native
  and strict Main/Wheel electrical checks refer to the new source hashes.
- Nine internal connectors are replaced by 86 plated solder holes on 2.54 mm
  pitch. Generated pin maps verify all 46 AWG28/AWG22/AWG24 conductors and
  preserve all grounds. Component-side and mirrored solder-side views identify
  every pad. No connector purchasing identity or paste remains on these lands.
- Hall, WSON and ADC paste patterns now follow the cited package geometry.
  Actual polygon area/perimeter/coverage/volume measurements and package
  dispositions replace the earlier rectangle-only screening as review evidence.
- Support contact strips, test-pad access, local ground/thermal inventory and
  copper close-ups are included. Wheel TP34 is obstructed by C90; J11.1/J11.2
  are the designated ACT_5V/return alternative with secured test leads.
- Panel, Gerber/drill and stencil ZIPs, source/transform manifest, via-only
  filling inventory, purchasing list and assembly aids are regenerated together.
  The exported JLC enquiry draft identifies the exact ZIP hashes.

## Manufacturing handoff and later assembly tasks

1. **During assembly — wire selection and bench fit:** consumer-source wire product, stripped
   strand/insulation fit, clamp fit and solder inspection. The Würth enquiry
   requirement is superseded; its follow-up draft must not be sent.
2. **During bench assembly — optical mounting:** use the selected matched
   Ploopy PMW3360/lens kit and adjust the fixture/case to its alignment and
   working height. No incompatibility is currently confirmed; supplier identity
   evidence remains open, but is not an indefinite bare-board ordering gate.
3. **Stencil design complete:** 0.10 mm is selected for Rev-A with the existing
   reviewed aperture patterns and documented volume tradeoff. Manufacturing
   confirmation remains with CAM. Paste choice, reflow limits and practice
   printing/reflow are required before assembly, not before bare-board ordering.
4. **JLC CAM response:** confirm slots/tabs, three designs, drill sizes,
   selective epoxy fill/copper cap, exact JLC041611-2116 stack and final stencil
   groups. A quotation or automatic DRC result is not CAM acceptance. If JLC
   requires an order before formal review, retain this gate as pending.

## Before assembly and powered tests

Purchase one population and specified wire materials, confirm received parts and
lot moisture limits, build adjustable supports and secure motor/magnets.
Measure real wire, clip, cable and optical fit. Inspect cut edges and
hidden-pad practice assemblies; visual appearance alone does not prove joints.
Component freight, mechanisms and consumables still need complete EUR pricing.

Bring up with current-limited power and actuator-off defaults: unpowered checks,
logic rails, USB, ADC1/Hall, optical, encoder/ADC2, low-current motor/brake, then
one button actuator at a time. Firmware, USB compliance, analog noise, actual
torque, temperature and assembly yield require hardware measurements.

Fixed button magnets use software endpoint calibration; precision magnet positioning
is not a fabrication blocker. Printed flexure/stop fit, monotonic unclipped travel
and coil/wheel interference remain hardware tests. Editable PETG fixtures and
STEP/STL/dimensioned views are supplied; no new PCB mounting holes were added.

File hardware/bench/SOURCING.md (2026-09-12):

> Current Rev-A uses soldered wires. All internal FFC/JST sourcing and mating
> requirements below are superseded historical observations. See HARNESS_REVIEW.md
> and the current purchasing list; no connector purchases or follow-up enquiries
> are required. Optical identity and other component evidence remain applicable.

# One-set sourcing checkpoint

**Purchasing constraint (2026-09-12): private-consumer suppliers only.** The
user has no business. CODICO sample-shop offers are excluded from selection,
not pending business credentials. Prefer EU stock; identify imports explicitly.

## Consumer optical candidate with Croatia shipping quote

The user selected Ploopy as the intended supplier on 2026-09-12 and will
place the order themselves later. Supplier selection is settled; exact part
identity and optical fit remain engineering checks. No order is authorized.

[Ploopy replacement PMW3360 sensor and optic](https://ploopy.co/shop/replacement-pixart-pmw-3360-mouse-sensor/),
SKU PLMKMOPMW001, is offered individually to consumers from Canada. On
2026-09-12 its cart accepted one set and calculated tracked shipping to
Bjelovar, 43000, Croatia: CAD 24.99 parts + CAD 22.02 shipping = CAD 47.01.
At the ECB 2026-09-11 rate EUR 1 = CAD 1.6064, these are approximately
EUR 15.56 + EUR 13.71 = EUR 29.26 (convert the unrounded total). The cart
displayed zero collected tax; import VAT and any handling fees are additional
and unquoted. Transit estimate is 12-32 business days, excluding dispatch time.
This confirms a shipping service quote, not stock reservation or an order.

The listing names 'PMW3360 sensor' and 'PMW3360 optic', but does not state
the exact sensor suffix and lens MPN. Confirm PMW3360DM-T2QU / LM19-LSI and
SROM availability before counting it as a qualified purchase for Main U35.
The candidate is kept separate from the qualified purchasing subtotal.
No personal street address, phone, email or payment information was entered;
no order was placed. This is an import option, not EU stock.

The EU consumer option checked, Keycapsss KC10125 (PMW3360 assembled module
with lens, EUR 29.90 displayed including VAT), has zero stock. It is also a
module rather than loose parts for Main U35. No immediately available EU-stock
consumer sensor/lens pair has been confirmed.

Wheel R113 also has an unavailable original listing, UNI-ROYAL 0603WAF3482T5E.
The bench purchasing variant uses Vishay **CRCW060334K8FKEA**, 34.8 kohm,
1%, 100 ppm/C, 0603, 0.125 W. It retains the resistance/tolerance and fits the
same non-polarized 0603 lands. R113 is in the BRAKE_DIV_TOP-to-BRAKE_SENSE
divider; even a conservative 6 V across it dissipates only 1.04 mW. The
75 V working-voltage rating and power rating exceed this use. The divider
values and existing threshold tolerance calculation are unchanged. Recheck
the received part marking/packaging before assembly; source CAD identity is
retained and the purchase substitution is explicit in `population.csv`.
[Manufacturer data](https://www.vishay.com/docs/20035/dcrcwe3.pdf),
[DigiKey exact part](https://www.digikey.com/en/products/detail/vishay-dale/CRCW060334K8FKEA/1174842).

Public listings checked 2026-09-11. The project has switched to one manually
assembled bench prototype, with five bare sets as fabrication spares. Reflow
tools are supplied by the user and are excluded from the project price.

The exact MA735GGU-P is available in cut tape at DigiKey (253 shown, USD 4.23
at quantity one). The exact LM4040AIM3-2.5/NOPB is also available there (14,529
shown, USD 2.51 at quantity one). These resolve supplier candidates for the
JLC-unavailable ICs, but not delivered pricing or reserved inventory. Sources
and observed quantities are in [the evidence record](sourcing-observations.json).

**2026-09-12 delivery correction:** Yushakobo's checkout for A080040-01-1
(PMW3360DM-T2QU with LM19-LSI) offers neither Croatia nor any EU country.
The earlier approximately EUR 17.87 catalogue estimate is not a directly
deliverable option and is excluded from the purchasing subtotal. No forwarding
service has been qualified or priced. SROM supply remains unconfirmed.

CODICO Austria lists [PMK3360IS Sample Kit (CDC)](https://www.codico.com/en/pmk3360is-sample-kit-cdc),
code 261681: five PMW3360DM-T2QU sensors plus five lenses for EUR 57.00 before
VAT. Its shipping page advertises worldwide free delivery, but its
[sample-shop terms](https://www.codico.com/en/gtc-sample-shop) restrict sales to
businesses. Availability says 'Deliverable in short time', not a firm stock
count or delivery date. Exact included lens MPN, buyer eligibility and final
Croatia checkout were not confirmed. This historical candidate is excluded
under the user's private-consumer-only purchasing constraint.

## R25 purchasing substitution

Original UNI-ROYAL 0603WAF8873T5E is out of stock, minimum 100. Select Vishay
CRCW0603887KFKEA for the bench purchasing variant: 887 kohm, 1%, 0603,
100 ppm/K, 75 V, 0.125 W versus the original 0.100 W. Its unchanged resistance,
tolerance, voltage rating and temperature coefficient preserve the divider
calculation; the package fits the existing 0603 lands. This is a nonpolar
two-terminal resistor, so there is no pin-map change. The higher power rating
does not authorize raising the circuit operating limits.

The [Vishay manufacturer specification](https://www.vishay.com/docs/20035/dcrcwe3.pdf)
and [DigiKey listing](https://www.digikey.com/en/products/detail/vishay-dale/CRCW0603887KFKEA/1175004)
support this substitution. The listing showed USD 0.10 at quantity one. Retain
the original CAD identity and record both original and purchase MPNs in the
variant BOM; do not silently change the JLC baseline or its regression checks.

## Unresolved procurement and interface items

Main L1 now uses **Bourns SRP4020CC-3R3M**, with the manufacturer land pattern
and local copper update. See [L1_REVIEW.md](L1_REVIEW.md). The earlier Mouser
Croatia observation on 2026-09-12 was EUR 0.671, MOQ one, 1,784 available;
this is not reserved stock or a delivered cart. The purchasing list now uses
this exact part and no longer carries the original Sunlord item for Main L1.
Hardware regulator temperature, ripple and load steps still require testing.

- The Wurth FFC still has stripped-length and width/pitch-span tolerance
  differences from the Hirose drawing. A Molex Type-A lead was investigated,
  but its public page did not supply the required mating tolerances. Neither
  is declared a qualified replacement. Keep the existing reverse contact map
  J8.N to J9.(31-N); no wiring or buffer changes are made.
- The SteadyWin motor-only listing shows USD 12.60 but ambiguous availability.
  Confirm the motor-only variant and its drawing before freezing a bolt-on
  adapter. Do not use an encoder-equipped price for a motor-only BOM.
- Power, encoder and button harnesses need matching housings, contacts or
  precrimp leads, in addition to the headers already in the PCB BOM.
- Magnets, coil materials, adjustable fixture materials and consumables remain
  explicit open purchasing lines. Tools are excluded, not these materials.

No complete delivered component total is claimed. Unknown costs remain blank,
never zero. The authorized Wurth enquiry was sent; see WURTH_ENQUIRY.md.
No orders or payment have been submitted.

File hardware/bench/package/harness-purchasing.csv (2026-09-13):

Description | Required_m | Suggested_purchase_m | Spare_m | Mapping | Supplier | Price_EUR | Shipping_EUR | Status
30-way stranded AWG28 ribbon, 1.27 mm conductor pitch | 0.3 | 0.5 | 0.2 | Main/J8-Wheel/J9 0.15 m; trim 8 conductors for Main/J6-Encoder/J7 0.15 m | Private-consumer source; exact wire product and price pending |  |  | No crimp housings or contacts; inspect strand fit/insulation and verify continuity
Stranded AWG22 insulated wire, two identifiable colours | 0.3 | 1.0 | 0.7 | Main/J10-Wheel/J11; two 0.15 m leads | Private-consumer source; exact wire product and price pending |  |  | No crimp housings or contacts; inspect strand fit/insulation and verify continuity
Stranded AWG24 insulated wire, marked paired leads | 1.2 | 2.0 | 0.8 | Main/J2/J3/J4; six 0.20 m leads | Private-consumer source; exact wire product and price pending |  |  | No crimp housings or contacts; inspect strand fit/insulation and verify continuity

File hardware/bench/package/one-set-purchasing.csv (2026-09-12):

MPN | Original_MPN | Footprint | References | Required | Suggested_purchase | Spares | MOQ | Multiple | Supplier | URL | Stock_observed | Currency | Unit_price | Extended_price | Status
0603B103K500NT | 0603B103K500NT | Capacitor_SMD:C_0603_1608Metric | Main/C25;Main/C26 | 2 | 50 | 48 | 50 | 50 | LCSC | https://www.lcsc.com/product-detail/C57112.html | 1463250 | USD | 0.0109 | 0.545 | Public listing; delivery and tax not quoted
0603WAF0000T5E | 0603WAF0000T5E | Resistor_SMD:R_0603_1608Metric | Main/R125;Wheel/R105;Wheel/R106;Wheel/R107;Wheel/R108;Wheel/R109 | 6 | 100 | 94 | 100 | 100 | LCSC | https://www.lcsc.com/product-detail/C21189.html | 13791800 | USD | 0.0026 | 0.26 | Public listing; delivery and tax not quoted
0603WAF1000T5E | 0603WAF1000T5E | Resistor_SMD:R_0603_1608Metric | Wheel/R119 | 1 | 100 | 99 | 100 | 100 | LCSC | https://www.lcsc.com/product-detail/C22775.html | 7474000 | USD | 0.004 | 0.4 | Public listing; delivery and tax not quoted
0603WAF1001T5E | 0603WAF1001T5E | Resistor_SMD:R_0603_1608Metric | Main/R28;Main/R44;Main/R45;Main/R64;Main/R69 | 5 | 100 | 95 | 100 | 100 | LCSC | https://www.lcsc.com/product-detail/C21190.html | 9866800 | USD | 0.0033 | 0.33 | Public listing; delivery and tax not quoted
0603WAF1002T5E | 0603WAF1002T5E | Resistor_SMD:R_0603_1608Metric | Main/R3;Main/R4;Main/R7;Main/R8;Main/R9;Main/R10;Main/R11;Main/R14;Main/R15;Main/R16;Main/R17;Main/R20;Main/R21;Main/R22;Main/R23;Main/R30;Main/R46;Main/R47;Main/R48;Main/R49;Main/R50;Main/R51;Main/R52;Main/R53;Main/R54;Main/R55;Main/R70;Main/R61;Main/R72;Main/R73;Main/R74;Main/R75;Main/R76;Main/R77;Main/R78;Main/R79;Main/R80;Main/R99;Main/R126;Main/R127;Main/R130;Main/R131;Main/R135;Wheel/R82;Wheel/R84;Wheel/R86;Wheel/R98;Wheel/R111;Wheel/R137;Wheel/R138;Wheel/R139;Wheel/R140 | 52 | 100 | 48 | 100 | 100 | LCSC | https://www.lcsc.com/product-detail/C25804.html | 4617800 | USD | 0.0027 | 0.27 | Public listing; delivery and tax not quoted
0603WAF1003T5E | 0603WAF1003T5E | Resistor_SMD:R_0603_1608Metric | Main/R26;Main/R27;Main/R31;Main/R32;Main/R33;Main/R34;Main/R35;Main/R36;Main/R37;Main/R38;Main/R39;Main/R40;Main/R62;Main/R63;Main/R66;Main/R67;Main/R71;Main/R101;Main/R110;Main/R129;Main/R133;Main/R134;Main/R136;Wheel/R83;Wheel/R90;Wheel/R91;Wheel/R92;Wheel/R89;Wheel/R94;Wheel/R95;Wheel/R96;Wheel/R97;Wheel/R100;Wheel/R112;Wheel/R114;Wheel/R120 | 36 | 100 | 64 | 100 | 100 | LCSC | https://www.lcsc.com/product-detail/C25803.html | 18218500 | USD | 0.0042 | 0.42 | Public listing; delivery and tax not quoted
0603WAF1004T5E | 0603WAF1004T5E | Resistor_SMD:R_0603_1608Metric | Wheel/R115;Wheel/R116;Wheel/R117 | 3 | 100 | 97 | 100 | 100 | LCSC | https://www.lcsc.com/product-detail/C22935.html | 5905300 | USD | 0.0024 | 0.24 | Public listing; delivery and tax not quoted
0603WAF220JT5E | 0603WAF220JT5E | Resistor_SMD:R_0603_1608Metric | Wheel/R81 | 1 | 100 | 99 | 100 | 100 | LCSC | https://www.lcsc.com/product-detail/C23345.html | 5676500 | USD | 0.0019 | 0.19 | Public listing; delivery and tax not quoted
0603WAF2212T5E | 0603WAF2212T5E | Resistor_SMD:R_0603_1608Metric | Main/R29;Main/R41;Main/R65;Main/R68 | 4 | 100 | 96 | 100 | 100 | LCSC | https://www.lcsc.com/product-detail/C25961.html | 24400 | USD | 0.0062 | 0.62 | Public listing; delivery and tax not quoted
0603WAF3300T5E | 0603WAF3300T5E | Resistor_SMD:R_0603_1608Metric | Main/R128;Wheel/R102;Wheel/R103;Wheel/R104 | 4 | 100 | 96 | 100 | 100 | LCSC | https://www.lcsc.com/product-detail/C23138.html | 2567900 | USD | 0.0028 | 0.28 | Public listing; delivery and tax not quoted
0603WAF3301T5E | 0603WAF3301T5E | Resistor_SMD:R_0603_1608Metric | Main/R12;Main/R18;Main/R24;Main/R42;Main/R43;Main/R56;Main/R57;Main/R60 | 8 | 100 | 92 | 100 | 100 | LCSC | https://www.lcsc.com/product-detail/C22978.html | 5296900 | USD | 0.0028 | 0.28 | Public listing; delivery and tax not quoted
0603WAF3302T5E | 0603WAF3302T5E | Resistor_SMD:R_0603_1608Metric | Main/R141;Main/R142;Main/R143;Wheel/R144;Wheel/R145 | 5 | 100 | 95 | 100 | 100 | LCSC | https://www.lcsc.com/product-detail/C4216.html | 2693800 | USD | 0.0026 | 0.26 | Public listing; delivery and tax not quoted
0603WAF330JT5E | 0603WAF330JT5E | Resistor_SMD:R_0603_1608Metric | Main/R5;Main/R6;Main/R58 | 3 | 100 | 97 | 100 | 100 | LCSC | https://www.lcsc.com/product-detail/C23140.html | 4105100 | USD | 0.0028 | 0.28 | Public listing; delivery and tax not quoted
0603WAF390JT5E | 0603WAF390JT5E | Resistor_SMD:R_0603_1608Metric | Main/R132 | 1 | 100 | 99 | 100 | 100 | LCSC | https://www.lcsc.com/product-detail/C23154.html | 92300 | USD | 0.0045 | 0.45 | Public listing; delivery and tax not quoted
0603WAF4701T5E | 0603WAF4701T5E | Resistor_SMD:R_0603_1608Metric | Main/R59;Wheel/R87;Wheel/R88;Wheel/R146 | 4 | 100 | 96 | 100 | 100 | LCSC | https://www.lcsc.com/product-detail/C23162.html | 18282200 | USD | 0.003 | 0.3 | Public listing; delivery and tax not quoted
16SVPC100M | 16SVPC100M | Capacitor_SMD:CP_Elec_6.3x5.9 | Wheel/C90 | 1 | 1 | 0 | 1 | 1 | LCSC | https://www.lcsc.com/product-detail/C136275.html | 14403 | USD | 0.7054 | 0.7054 | Public listing; delivery and tax not quoted
2N7002 | 2N7002 | Package_TO_SOT_SMD:SOT-23 | Main/Q1;Main/Q2;Main/Q3;Wheel/Q4 | 4 | 50 | 46 | 50 | 50 | LCSC | https://www.lcsc.com/product-detail/C8545.html | 1643800 | USD | 0.0164 | 0.82 | Public listing; delivery and tax not quoted
ADS7038IRTER | ADS7038IRTER | Package_DFN_QFN:WQFN-16-1EP_3x3mm_P0.5mm_EP1.68x1.68mm | Main/U10;Wheel/U23 | 2 | 2 | 0 | 1 | 1 | DigiKey | https://www.digikey.com/en/products/detail/texas-instruments/ADS7038IRTER/11502258 | 1496 | USD | 6.93 | 13.86 | Exact MPN cut tape listing; delivery and tax not quoted
AO3400A | AO3400A | Package_TO_SOT_SMD:SOT-23 | Wheel/Q5 | 1 | 5 | 4 | 5 | 5 | LCSC | https://www.lcsc.com/product-detail/C20917.html | 505665 | USD | 0.0853 | 0.4265 | Public listing; delivery and tax not quoted
BAT54-7-F | BAT54-7-F | Package_TO_SOT_SMD:SOT-23 | Main/D3;Main/D4 | 2 | 20 | 18 | 20 | 20 | LCSC | https://www.lcsc.com/product-detail/C106920.html | 95240 | USD | 0.0356 | 0.712 | Public listing; delivery and tax not quoted
CC0603KRX7R9BB104 | CC0603KRX7R9BB104 | Capacitor_SMD:C_0603_1608Metric | Main/C22;Main/C6;Main/C7;Main/C9;Main/C10;Main/C12;Main/C13;Main/C15;Main/C16;Main/C17;Main/C18;Main/C28;Main/C29;Main/C30;Main/C31;Main/C32;Main/C33;Main/C34;Main/C35;Main/C36;Main/C53;Main/C55;Main/C64;Main/C70;Main/C75;Main/C76;Main/C83;Main/C85;Main/C80;Main/C86;Main/C87;Wheel/C41;Wheel/C42;Wheel/C43;Wheel/C49;Wheel/C51;Wheel/C52;Wheel/C54;Wheel/C65;Wheel/C66 | 40 | 50 | 10 | 50 | 50 | LCSC | https://www.lcsc.com/product-detail/C14663.html | 9087200 | USD | 0.0125 | 0.625 | Public listing; delivery and tax not quoted
CL10A105KB8NNNC | CL10A105KB8NNNC | Capacitor_SMD:C_0603_1608Metric | Main/C4;Main/C19;Main/C20;Main/C21;Main/C24;Main/C89;Main/C27;Main/C63;Wheel/C46;Wheel/C48;Wheel/C56;Wheel/C57;Wheel/C58;Encoder/C62 | 14 | 50 | 36 | 50 | 50 | LCSC | https://www.lcsc.com/product-detail/C15849.html | 35600 | USD | 0.0176 | 0.88 | Public listing; delivery and tax not quoted
CL10A475KP8NNNC | CL10A475KP8NNNC | Capacitor_SMD:C_0603_1608Metric | Main/C84 | 1 | 50 | 49 | 50 | 50 | LCSC | https://www.lcsc.com/product-detail/C1705.html | 1761800 | USD | 0.0178 | 0.89 | Public listing; delivery and tax not quoted
CL10B102KB8NNNC | CL10B102KB8NNNC | Capacitor_SMD:C_0603_1608Metric | Main/C79 | 1 | 50 | 49 | 50 | 50 | LCSC | https://www.lcsc.com/product-detail/C1588.html | 6304400 | USD | 0.009 | 0.45 | Public listing; delivery and tax not quoted
CL10B103KB8NNNC | CL10B103KB8NNNC | Capacitor_SMD:C_0603_1608Metric | Main/C72 | 1 | 50 | 49 | 50 | 50 | LCSC | https://www.lcsc.com/product-detail/C1589.html | 2516450 | USD | 0.0102 | 0.51 | Public listing; delivery and tax not quoted
CL10B225KP8NNNC | CL10B225KP8NNNC | Capacitor_SMD:C_0603_1608Metric | Main/C71;Main/C81;Main/C82 | 3 | 20 | 17 | 20 | 20 | LCSC | https://www.lcsc.com/product-detail/C100082.html | 367860 | USD | 0.0355 | 0.71 | Public listing; delivery and tax not quoted
CL10B473KB8NNNC | CL10B473KB8NNNC | Capacitor_SMD:C_0603_1608Metric | Wheel/C47 | 1 | 50 | 49 | 50 | 50 | LCSC | https://www.lcsc.com/product-detail/C1622.html | 560550 | USD | 0.0083 | 0.415 | Public listing; delivery and tax not quoted
CL10C220JB8NNNC | CL10C220JB8NNNC | Capacitor_SMD:C_0603_1608Metric | Wheel/C59;Wheel/C60;Wheel/C61;Wheel/C67 | 4 | 100 | 96 | 100 | 100 | LCSC | https://www.lcsc.com/product-detail/C1653.html | 1209800 | USD | 0.0068 | 0.68 | Public listing; delivery and tax not quoted
CL21A106KAYNNNE | CL21A106KAYNNNE | Capacitor_SMD:C_0805_2012Metric | Main/C1;Main/C2;Main/C3;Main/C23;Main/C5;Main/C8;Main/C11;Main/C14;Main/C88;Main/C37;Main/C38;Main/C39;Main/C40;Main/C73;Main/C74;Main/C77;Main/C78;Wheel/C44;Wheel/C45;Wheel/C68;Wheel/C69 | 21 | 40 | 19 | 20 | 20 | LCSC | https://www.lcsc.com/product-detail/C15850.html | 2769000 | USD | 0.085 | 3.4 | Public listing; delivery and tax not quoted
CL21A226MAQNNNE | CL21A226MAQNNNE | Capacitor_SMD:C_0805_2012Metric | Wheel/C50 | 1 | 20 | 19 | 20 | 20 | LCSC | https://www.lcsc.com/product-detail/C45783.html | 2462600 | USD | 0.248 | 4.96 | Public listing; delivery and tax not quoted
CRCW060334K8FKEA | 0603WAF3482T5E | Resistor_SMD:R_0603_1608Metric | Wheel/R113 | 1 | 3 | 2 | 1 | 1 | DigiKey | https://www.digikey.com/en/products/detail/vishay-dale/CRCW060334K8FKEA/1174842 | 47827 | USD | 0.1 | 0.3 | Reviewed bench purchasing substitute for Wheel R113; see SOURCING.md; delivery/tax not quoted
CRCW0603887KFKEA | 0603WAF8873T5E | Resistor_SMD:R_0603_1608Metric | Main/R25 | 1 | 3 | 2 | 1 | 1 | DigiKey | https://www.digikey.com/en/products/detail/vishay-dale/CRCW0603887KFKEA/1175004 | 39578 | USD | 0.1 | 0.3 | Reviewed purchasing substitute for Main R25; see SOURCING.md
DRV8231ADSGR | DRV8231ADSGR | Package_SON:Texas_DSG0008A_WSON-8-1EP_2x2mm_P0.5mm_EP0.9x1.6mm | Main/U4;Main/U5;Main/U6 | 3 | 3 | 0 | 1 | 1 | DigiKey | https://www.digikey.com/en/products/detail/texas-instruments/DRV8231ADSGR/15853799 | 6936 | USD | 1.79 | 5.37 | Exact MPN cut tape listing; delivery and tax not quoted
DRV8316RRGFR | DRV8316RRGFR | MagMouse:Texas_RGF0040E | Wheel/U21 | 1 | 1 | 0 | 1 | 1 | LCSC | https://www.lcsc.com/product-detail/C5218861.html | 38 | USD | 4.5805 | 4.5805 | Public listing; delivery and tax not quoted
ESP32-S3-MINI-1-N8 | ESP32-S3-MINI-1-N8 | RF_Module:ESP32-S2-MINI-1 | Main/U3 | 1 | 1 | 0 | 1 | 1 | DigiKey | https://www.digikey.com/en/products/detail/espressif-systems/ESP32-S3-MINI-1-N8/15295890 | 9107 | USD | 5.43 | 5.43 | Exact MPN cut tape listing; shipping and tax not quoted
LM4040AIM3-2.5/NOPB | LM4040AIM3-2.5/NOPB | Package_TO_SOT_SMD:SOT-23 | Wheel/U31 | 1 | 1 | 0 | 1 | 1 | DigiKey | https://www.digikey.com/en/products/detail/texas-instruments/LM4040AIM3-2-5-NOPB/182330 | 14529 | USD | 2.51 | 2.51 | Exact MPN available as cut tape; delivery/tax not yet quoted
MA735GGU-P | MA735GGU-P | MagMouse:MPS_UTQFN14_2x2 | Encoder/U27 | 1 | 1 | 0 | 1 | 1 | DigiKey | https://www.digikey.com/en/products/detail/monolithic-power-systems-inc/MA735GGU-P/16896184 | 253 | USD | 4.23 | 4.23 | Exact MPN available as cut tape; delivery/tax not yet quoted
PMW3360DM-T2QU | PMW3360DM-T2QU | MagMouse:PixArt_PMW3360DM_T2QU | Main/U35 | 1 | 1 | 0 | 1 | 1 | Yushakobo | https://shop.yushakobo.jp/en/products/11274 | 35 | JPY |  |  | BLOCKED: checkout on 2026-09-12 offers neither Croatia nor any EU country; catalogue price excluded. No qualified forwarding service; SROM unconfirmed.
RC2512JK-7W47RL | RC2512JK-7W47RL | Resistor_SMD:R_2512_6332Metric | Wheel/R121;Wheel/R122;Wheel/R123;Wheel/R124 | 4 | 5 | 1 | 5 | 5 | LCSC | https://www.lcsc.com/product-detail/C136992.html | 3670 | USD | 0.0949 | 0.4745 | Public listing; delivery and tax not quoted
SK6805-EC15 | SK6805-EC15 | MagMouse:OPSCO_SK6805_EC15 | Main/D5 | 1 | 5 | 4 | 5 | 5 | LCSC | https://www.lcsc.com/product-detail/C2890035.html | 229075 | USD | 0.0956 | 0.478 | Public listing; delivery and tax not quoted
SMBJ12A | SMBJ12A | Diode_SMD:D_SMB | Main/D1 | 1 | 5 | 4 | 5 | 5 | LCSC | https://www.lcsc.com/product-detail/C151251.html | 17945 | USD | 0.1205 | 0.6025 | Public listing; delivery and tax not quoted
SMBJ6.0A | SMBJ6.0A | Diode_SMD:D_SMB | Main/D2;Wheel/D6 | 2 | 5 | 3 | 5 | 5 | LCSC | https://www.lcsc.com/product-detail/C83270.html | 7120 | USD | 0.1351 | 0.6755 | Public listing; delivery and tax not quoted
SN74LV1T34DBVR | SN74LV1T34DBVR | Package_TO_SOT_SMD:SOT-23-5 | Main/U34 | 1 | 5 | 4 | 5 | 5 | LCSC | https://www.lcsc.com/product-detail/C100024.html | 5230 | USD | 0.3256 | 1.628 | Public listing; delivery and tax not quoted
SN74LVC08APWR | SN74LVC08APWR | Package_SO:TSSOP-14_4.4x5mm_P0.65mm | Main/U16;Main/U17;Main/U18;Wheel/U22 | 4 | 4 | 0 | 1 | 1 | Mouser | https://www.mouser.com/ProductDetail/Texas-Instruments/SN74LVC08APWR?qs=FM6NhYOeeBVuqx5y44y2yw%3D%3D | 14237 | USD | 0.4 | 1.6 | Exact MPN cut tape listing; separate supplier shipping and tax not quoted
SN74LVC125APWR | SN74LVC125APWR | Package_SO:TSSOP-14_4.4x5mm_P0.65mm | Main/U25;Main/U29;Main/U37;Wheel/U24;Wheel/U26 | 5 | 5 | 0 | 1 | 1 | LCSC | https://www.lcsc.com/product-detail/C7813.html | 33688 | USD | 0.5172 | 2.586 | Public listing; delivery and tax not quoted
SN74LVC1G123DCUR | SN74LVC1G123DCUR | Package_SO:VSSOP-8_2.3x2mm_P0.5mm | Main/U15 | 1 | 1 | 0 | 1 | 1 | LCSC | https://www.lcsc.com/product-detail/C352969.html | 520 | USD | 1.6506 | 1.6506 | Public listing; delivery and tax not quoted
SN74LVC1G125DBVR | SN74LVC1G125DBVR | Package_TO_SOT_SMD:SOT-23-5 | Main/U39 | 1 | 5 | 4 | 5 | 5 | LCSC | https://www.lcsc.com/product-detail/C23654.html | 57630 | USD | 0.1206 | 0.603 | Public listing; delivery and tax not quoted
SN74LVC2G04DCKR | SN74LVC2G04DCKR | Package_TO_SOT_SMD:SOT-363_SC-70-6 | Main/U14 | 1 | 5 | 4 | 5 | 5 | LCSC | https://www.lcsc.com/product-detail/C105251.html | 4570 | USD | 0.204 | 1.02 | Public listing; delivery and tax not quoted
SRP4020CC-3R3M | SRP4020CC-3R3M | MagMouseModular:L_Bourns_SRP4020CC | Main/L1 | 1 | 1 | 0 | 1 | 1 | Mouser | https://hr.mouser.com/ProductDetail/Bourns/SRP4020CC-3R3M | 1784 | EUR | 0.671 | 0.671 | Recorded catalogue observation; Main L1 footprint and electrical substitution implemented. Stock not reserved; tax/freight not quoted.
TLV1811DBVR | TLV1811DBVR | Package_TO_SOT_SMD:SOT-23-5 | Wheel/U30 | 1 | 1 | 0 | 1 | 1 | LCSC | https://www.lcsc.com/product-detail/C5373003.html | 31861 | USD | 1.0538 | 1.0538 | Public listing; delivery and tax not quoted
TLV75519PDBVR | TLV75519PDBVR | Package_TO_SOT_SMD:SOT-23-5 | Main/U36 | 1 | 5 | 4 | 5 | 5 | LCSC | https://www.lcsc.com/product-detail/C2865381.html | 720 | USD | 0.1878 | 0.939 | Public listing; delivery and tax not quoted
TLV9001IDBVR | TLV9001IDBVR | Package_TO_SOT_SMD:SOT-23-5 | Main/U19 | 1 | 5 | 4 | 5 | 5 | LCSC | https://www.lcsc.com/product-detail/C398363.html | 101780 | USD | 0.0987 | 0.4935 | Public listing; delivery and tax not quoted
TMAG5253BA2IQDMRR | TMAG5253BA2IQDMRR | Package_SON:Texas_X2SON-4-1EP_1.1x1.4mm_P0.5mm_EP0.8x0.6mm | Main/U7;Main/U8;Main/U9 | 3 | 3 | 0 | 1 | 1 | Mouser | https://www.mouser.com/ProductDetail/Texas-Instruments/TMAG5253BA2IQDMRR?qs=mELouGlnn3fpVa%252Bc8W6ShA%3D%3D | 3785 | USD | 0.77 | 2.31 | Exact MPN cut tape listing; separate supplier delivery/tax not quoted
TPD2E2U06DCKR | TPD2E2U06DCKR | Package_TO_SOT_SMD:SOT-323_SC-70 | Main/U20 | 1 | 1 | 0 | 1 | 1 | DigiKey | https://www.digikey.com/en/products/detail/texas-instruments/TPD2E2U06DCKR/11502208 | 17 | USD | 0.6 | 0.6 | Exact MPN cut tape listing; delivery and tax not quoted
TPD2EUSB30DRTR | TPD2EUSB30DRTR | Package_TO_SOT_SMD:Texas_DRT-3 | Main/U1 | 1 | 1 | 0 | 1 | 1 | LCSC | https://www.lcsc.com/product-detail/C97502.html | 1810 | USD | 0.903 | 0.903 | Public listing; delivery and tax not quoted
TPS22918DBVR | TPS22918DBVR | Package_TO_SOT_SMD:SOT-23-6 | Main/U38 | 1 | 5 | 4 | 5 | 5 | LCSC | https://www.lcsc.com/product-detail/C131941.html | 1740 | USD | 0.294 | 1.47 | Public listing; delivery and tax not quoted
TPS22919DCKR | TPS22919DCKR | Package_TO_SOT_SMD:SOT-363_SC-70-6 | Main/U28 | 1 | 5 | 4 | 5 | 5 | LCSC | https://www.lcsc.com/product-detail/C2149796.html | 67890 | USD | 0.1243 | 0.6215 | Public listing; delivery and tax not quoted
TPS259470LRPWR | TPS259470LRPWR | MagMouse:Texas_RPW0010A | Main/U12;Main/U13 | 2 | 2 | 0 | 1 | 1 | LCSC | https://www.lcsc.com/product-detail/C3662793.html | 57 | USD | 1.021 | 2.042 | Public listing; delivery and tax not quoted
TPS62162DSGR | TPS62162DSGR | Package_SON:Texas_DSG0008A_WSON-8-1EP_2x2mm_P0.5mm_EP0.9x1.6mm | Main/U2 | 1 | 1 | 0 | 1 | 1 | LCSC | https://www.lcsc.com/product-detail/C40256.html | 1847 | USD | 1.1139 | 1.1139 | Public listing; delivery and tax not quoted
TPS7A2450DBVR | TPS7A2450DBVR | Package_TO_SOT_SMD:SOT-23-5 | Main/U33 | 1 | 5 | 4 | 5 | 5 | LCSC | https://www.lcsc.com/product-detail/C2864436.html | 1920 | USD | 0.297 | 1.485 | Public listing; delivery and tax not quoted
TS-1088-AR02016 | TS-1088-AR02016 | Button_Switch_SMD:SW_SPST_TS-1088-xR020 | Main/SW1;Main/SW2 | 2 | 10 | 8 | 10 | 10 | LCSC | https://www.lcsc.com/product-detail/C720477.html | 612750 | USD | 0.0562 | 0.562 | Public listing; delivery and tax not quoted
TUSB320LAIRWBR | TUSB320LAIRWBR | Package_DFN_QFN:Texas_X2QFN-12_1.6x1.6mm_P0.4mm | Main/U11 | 1 | 1 | 0 | 1 | 1 | LCSC | https://www.lcsc.com/product-detail/C132554.html | 388 | USD | 1.0807 | 1.0807 | Public listing; delivery and tax not quoted
TYPE-C-31-M-12 | TYPE-C-31-M-12 | Connector_USB:USB_C_Receptacle_HRO_TYPE-C-31-M-12 | Main/J1 | 1 | 5 | 4 | 5 | 5 | LCSC | https://www.lcsc.com/product-detail/C165948.html | 233345 | USD | 0.1873 | 0.9365 | Public listing; delivery and tax not quoted

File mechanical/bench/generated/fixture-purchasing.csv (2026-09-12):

Item | Required_quantity | Purchase_quantity | Material | Solid_volume_cm3 | Price_EUR | Shipping_EUR | Status
base_0_0 | 1 | 1 | PETG printed part | 74.107 |  |  | Price from selected filament and slicer usage remains pending
base_1_0 | 1 | 1 | PETG printed part | 89.656 |  |  | Price from selected filament and slicer usage remains pending
base_0_1 | 1 | 1 | PETG printed part | 89.601 |  |  | Price from selected filament and slicer usage remains pending
base_1_1 | 1 | 1 | PETG printed part | 89.656 |  |  | Price from selected filament and slicer usage remains pending
tile_joiner_x | 4 | 4 | PETG printed part | 9.019 |  |  | Price from selected filament and slicer usage remains pending
tile_joiner_y | 4 | 4 | PETG printed part | 9.019 |  |  | Price from selected filament and slicer usage remains pending
edge_saddle | 8 | 8 | PETG printed part | 3.416 |  |  | Price from selected filament and slicer usage remains pending
edge_cap | 8 | 8 | PETG printed part | 1.173 |  |  | Price from selected filament and slicer usage remains pending
ribbon_clamp_base | 2 | 2 | PETG printed part | 5.615 |  |  | Price from selected filament and slicer usage remains pending
ribbon_clamp_cap | 2 | 2 | PETG printed part | 4.623 |  |  | Price from selected filament and slicer usage remains pending
encoder_clamp_base | 2 | 2 | PETG printed part | 2.927 |  |  | Price from selected filament and slicer usage remains pending
encoder_clamp_cap | 2 | 2 | PETG printed part | 2.621 |  |  | Price from selected filament and slicer usage remains pending
pair_clamp_base | 8 | 8 | PETG printed part | 7.099 |  |  | Price from selected filament and slicer usage remains pending
pair_clamp_cap | 8 | 8 | PETG printed part | 6.692 |  |  | Price from selected filament and slicer usage remains pending
encoder_carrier | 1 | 1 | PETG printed part | 4.491 |  |  | Price from selected filament and slicer usage remains pending
encoder_edge_clip | 2 | 2 | PETG printed part | 0.516 |  |  | Price from selected filament and slicer usage remains pending
motor_plate | 1 | 1 | PETG printed part | 16.396 |  |  | Price from selected filament and slicer usage remains pending
button_lever | 3 | 3 | PETG printed part | 5.427 |  |  | Price from selected filament and slicer usage remains pending
button_stop | 3 | 3 | PETG printed part | 1.921 |  |  | Price from selected filament and slicer usage remains pending
M3 threaded rod 60 mm | 12 | 12 | Hardware allowance; verify lengths on assembled sample |  |  |  | Unquoted consumer hardware; no purchase authorised
M3 nuts | 110 | 150 | Hardware allowance; verify lengths on assembled sample |  |  |  | Unquoted consumer hardware; no purchase authorised
M3 washers | 110 | 150 | Hardware allowance; verify lengths on assembled sample |  |  |  | Unquoted consumer hardware; no purchase authorised
M3 screws 16/25 mm assortment | 70 | 100 | Hardware allowance; verify lengths on assembled sample |  |  |  | Unquoted consumer hardware; no purchase authorised

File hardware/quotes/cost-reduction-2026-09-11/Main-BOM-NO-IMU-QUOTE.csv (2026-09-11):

Comment | Designator | Footprint | LCSC Part # | MPN | Quantity
10uF/25V | C1,C2,C3,C5,C8,C11,C14,C23,C37,C38,C39,C40,C73,C74,C77,C78,C88 | Capacitor_SMD:C_0805_2012Metric | C15850 | CL21A106KAYNNNE | 17
1uF/50V | C4,C19,C20,C21,C24,C27,C63,C89 | Capacitor_SMD:C_0603_1608Metric | C15849 | CL10A105KB8NNNC | 8
100nF | C6,C7,C9,C10,C12,C13,C15,C16,C17,C18,C22,C28,C29,C30,C31,C32,C33,C34,C35,C36,C53,C55,C64,C70,C75,C76,C80,C83,C85,C86,C87 | Capacitor_SMD:C_0603_1608Metric | C14663 | CC0603KRX7R9BB104 | 31
10nF | C25,C26 | Capacitor_SMD:C_0603_1608Metric | C57112 | 0603B103K500NT | 2
2.2uF/10V | C71,C81,C82 | Capacitor_SMD:C_0603_1608Metric | C100082 | CL10B225KP8NNNC | 3
10nF | C72 | Capacitor_SMD:C_0603_1608Metric | C1589 | CL10B103KB8NNNC | 1
1nF/50V | C79 | Capacitor_SMD:C_0603_1608Metric | C1588 | CL10B102KB8NNNC | 1
4.7uF/10V | C84 | Capacitor_SMD:C_0603_1608Metric | C1705 | CL10A475KP8NNNC | 1
SMBJ12A | D1 | Diode_SMD:D_SMB | C151251 | SMBJ12A | 1
SMBJ6.0A | D2 | Diode_SMD:D_SMB | C83270 | SMBJ6.0A | 1
BAT54-7-F | D3,D4 | Package_TO_SOT_SMD:SOT-23 | C106920 | BAT54-7-F | 2
SK6805-EC15 | D5 | MagMouse:OPSCO_SK6805_EC15 | C2890035 | SK6805-EC15 | 1
TYPE-C-31-M-12 | J1 | Connector_USB:USB_C_Receptacle_HRO_TYPE-C-31-M-12 | C165948 | TYPE-C-31-M-12 | 1
COIL_L | J2 | Connector_JST:JST_PH_B2B-PH-SM4-TB_1x02-1MP_P2.00mm_Vertical | C265003 | B2B-PH-SM4-TBT(LF)(SN) | 1
COIL_M | J3 | Connector_JST:JST_PH_B2B-PH-SM4-TB_1x02-1MP_P2.00mm_Vertical | C265003 | B2B-PH-SM4-TBT(LF)(SN) | 1
COIL_R | J4 | Connector_JST:JST_PH_B2B-PH-SM4-TB_1x02-1MP_P2.00mm_Vertical | C265003 | B2B-PH-SM4-TBT(LF)(SN) | 1
ENCODER_8P | J6 | Connector_JST:JST_SH_SM08B-SRSS-TB_1x08-1MP_P1.00mm_Horizontal | C160407 | SM08B-SRSS-TB(LF)(SN) | 1
WHEEL_SIGNAL_30P | J8 | Connector_FFC-FPC:Hirose_FH12-30S-0.5SH_1x30-1MP_P0.50mm_Horizontal | C506793 | FH12-30S-0.5SH(55) | 1
WHEEL_POWER_2P | J10 | MagMouseModular:JST_PA_SM02B-PASS_1x02_P2.00mm_Horizontal | C495198 | SM02B-PASS-TB(LF)(SN) | 1
SWPA4020S3R3MT | L1 | Inductor_SMD:L_Sunlord_SWPA4020S | C83424 | SWPA4020S3R3MT | 1
2N7002 | Q1,Q2,Q3 | Package_TO_SOT_SMD:SOT-23 | C8545 | 2N7002 | 3
10k | R3,R4,R7,R8,R9,R10,R11,R14,R15,R16,R17,R20,R21,R22,R23,R30,R46,R47,R48,R49,R50,R51,R52,R53,R54,R55,R61,R70,R72,R73,R74,R75,R76,R77,R78,R79,R80,R99,R126,R127,R130,R131,R135 | Resistor_SMD:R_0603_1608Metric | C25804 | 0603WAF1002T5E | 43
33R | R5,R6,R58 | Resistor_SMD:R_0603_1608Metric | C23140 | 0603WAF330JT5E | 3
3.3k | R12,R18,R24,R42,R43,R56,R57,R60 | Resistor_SMD:R_0603_1608Metric | C22978 | 0603WAF3301T5E | 8
887k | R25 | Resistor_SMD:R_0603_1608Metric | C23259 | 0603WAF8873T5E | 1
100k | R26,R27,R31,R32,R33,R34,R35,R36,R37,R38,R39,R40,R62,R63,R66,R67,R71,R101,R110,R129,R133,R134,R136 | Resistor_SMD:R_0603_1608Metric | C25803 | 0603WAF1003T5E | 23
1k | R28,R44,R45,R64,R69 | Resistor_SMD:R_0603_1608Metric | C21190 | 0603WAF1001T5E | 5
22.1k | R29,R41,R65,R68 | Resistor_SMD:R_0603_1608Metric | C25961 | 0603WAF2212T5E | 4
4.7k | R59 | Resistor_SMD:R_0603_1608Metric | C23162 | 0603WAF4701T5E | 1
0R | R125 | Resistor_SMD:R_0603_1608Metric | C21189 | 0603WAF0000T5E | 1
330R | R128 | Resistor_SMD:R_0603_1608Metric | C23138 | 0603WAF3300T5E | 1
39R | R132 | Resistor_SMD:R_0603_1608Metric | C23154 | 0603WAF390JT5E | 1
33k | R141,R142,R143 | Resistor_SMD:R_0603_1608Metric | C4216 | 0603WAF3302T5E | 3
RESET | SW1 | Button_Switch_SMD:SW_SPST_TS-1088-xR020 | C720477 | TS-1088-AR02016 | 1
BOOT | SW2 | Button_Switch_SMD:SW_SPST_TS-1088-xR020 | C720477 | TS-1088-AR02016 | 1
TPD2EUSB30DRTR | U1 | Package_TO_SOT_SMD:Texas_DRT-3 | C97502 | TPD2EUSB30DRTR | 1
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

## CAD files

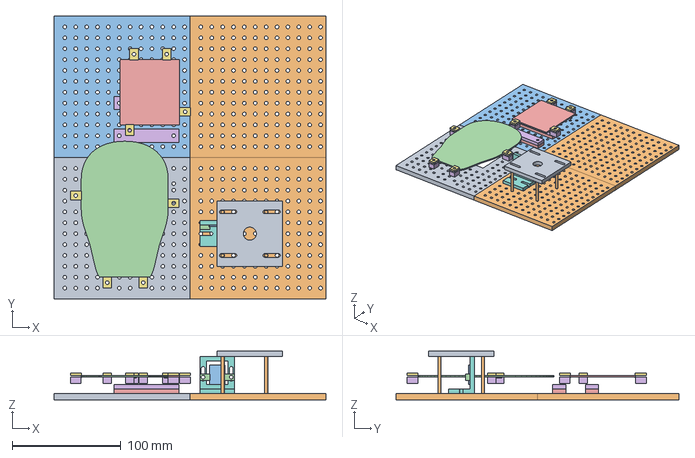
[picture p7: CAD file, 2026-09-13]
hardware/bench/package/fixture/assembly-envelope.step
250.0 x 260.0 x 45.0 mm

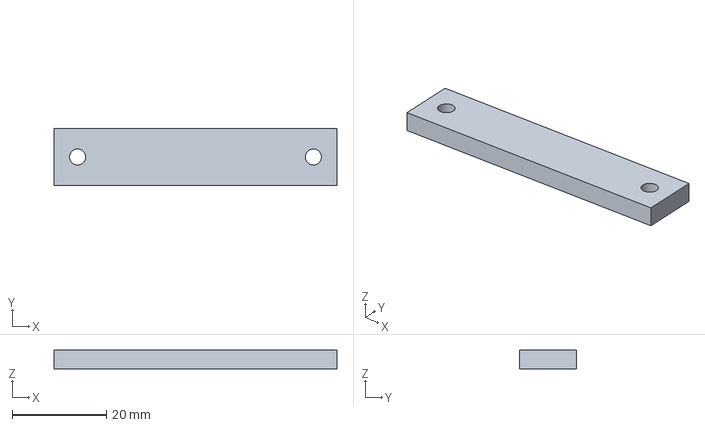
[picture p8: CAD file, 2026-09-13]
hardware/bench/package/fixture/ribbon_clamp_base.step
60.0 x 12.0 x 4.00 mm

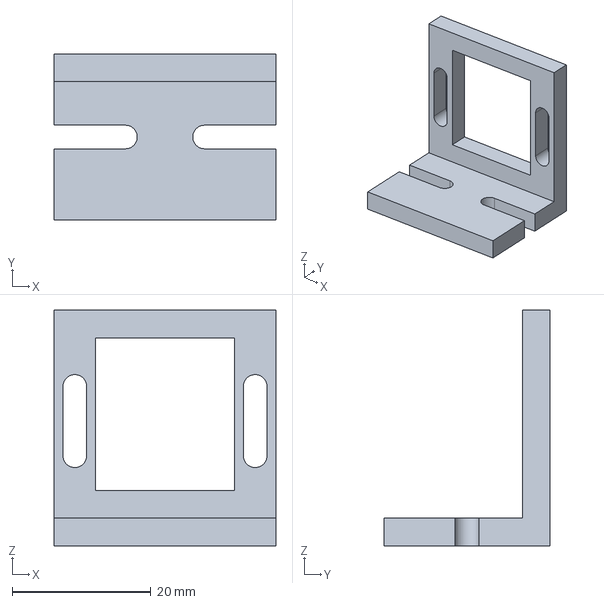
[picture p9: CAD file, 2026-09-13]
mechanical/bench/generated/encoder_carrier.step
32.0 x 24.0 x 34.0 mm

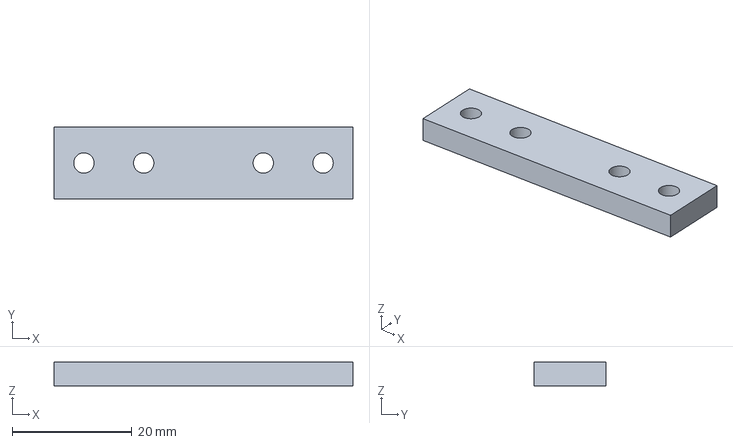
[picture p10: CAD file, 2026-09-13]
hardware/bench/package/fixture/tile_joiner_y.step
50.0 x 12.0 x 4.00 mm

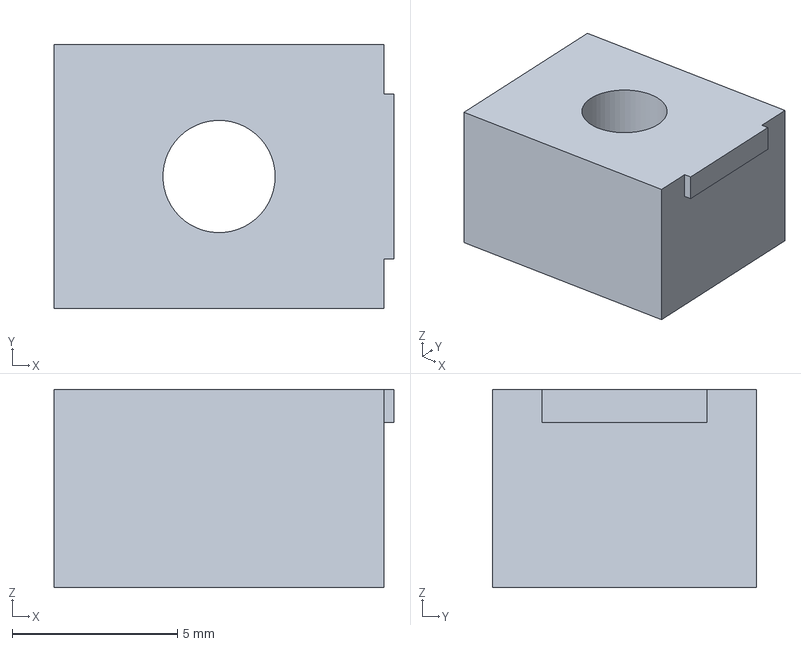
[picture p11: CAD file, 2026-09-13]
hardware/bench/package/fixture/edge_saddle.step
10.3 x 8.00 x 6.00 mm

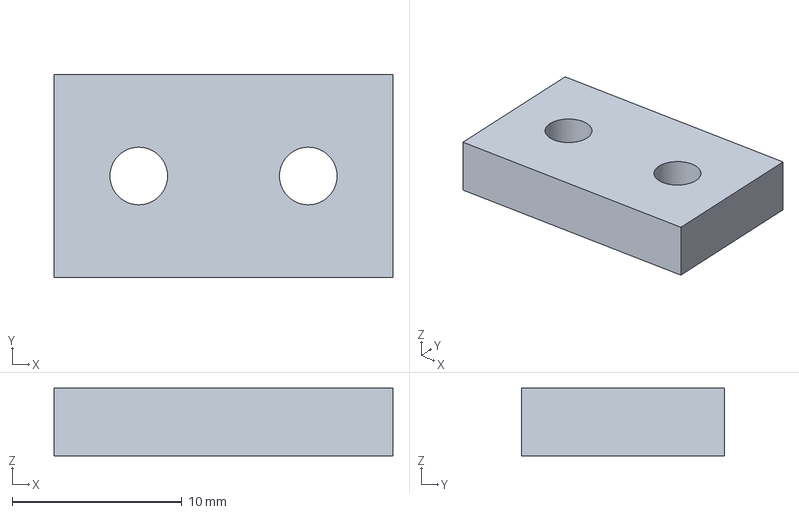
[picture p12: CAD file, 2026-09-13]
mechanical/bench/generated/pair_clamp_cap.step
20.0 x 12.0 x 4.00 mm

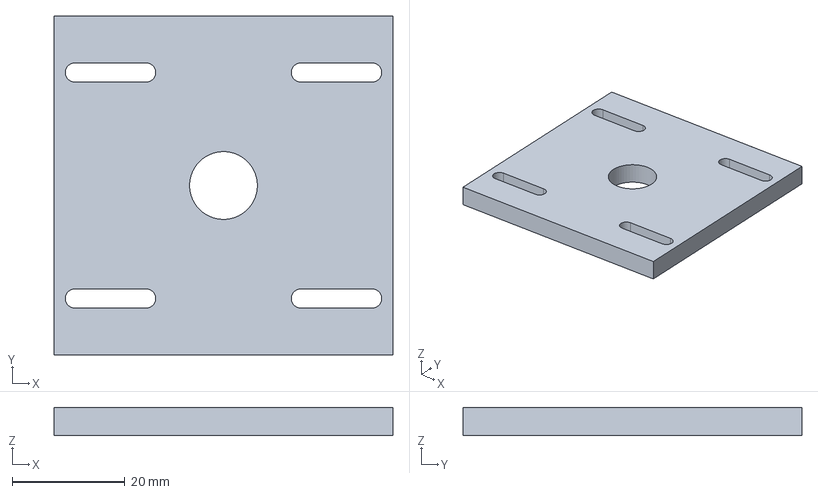
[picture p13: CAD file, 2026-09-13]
hardware/bench/package/fixture/motor_plate.step
60.0 x 60.0 x 5.00 mm

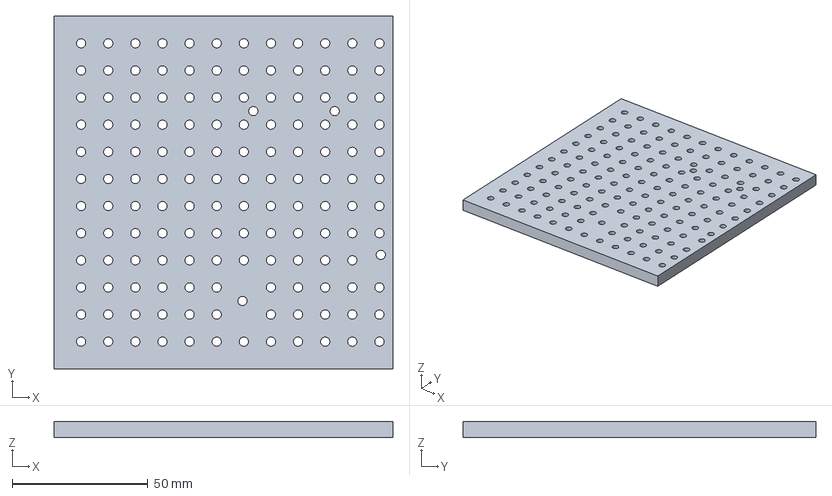
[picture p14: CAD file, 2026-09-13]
mechanical/bench/generated/base_0_1.step
125.0 x 130.0 x 6.00 mm

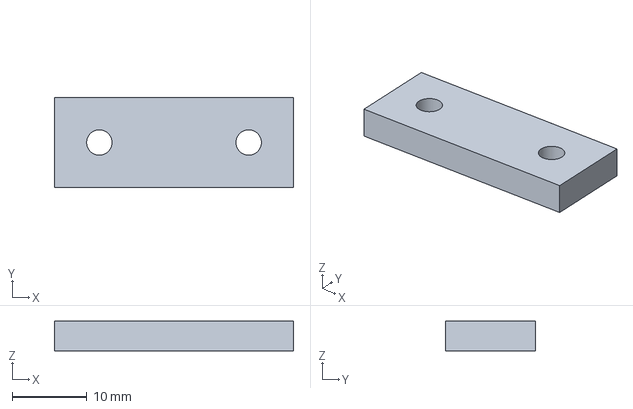
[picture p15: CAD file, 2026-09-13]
hardware/bench/package/fixture/encoder_clamp_cap.step
32.0 x 12.0 x 4.00 mm

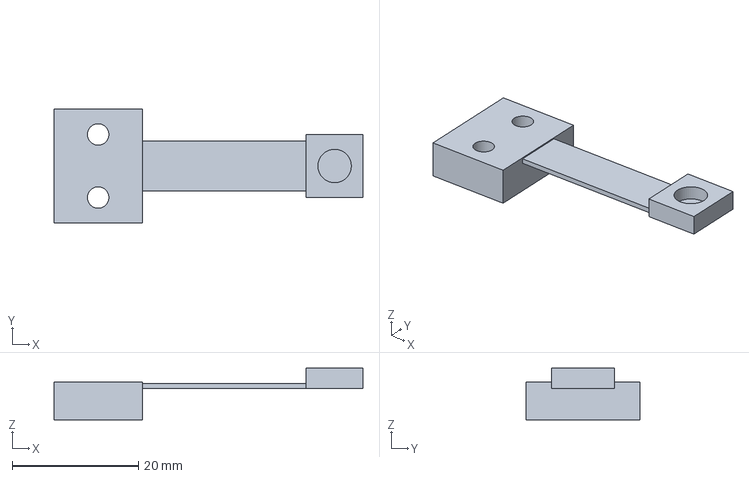
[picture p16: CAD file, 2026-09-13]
mechanical/bench/generated/button_lever.step
49.0 x 18.0 x 8.20 mm

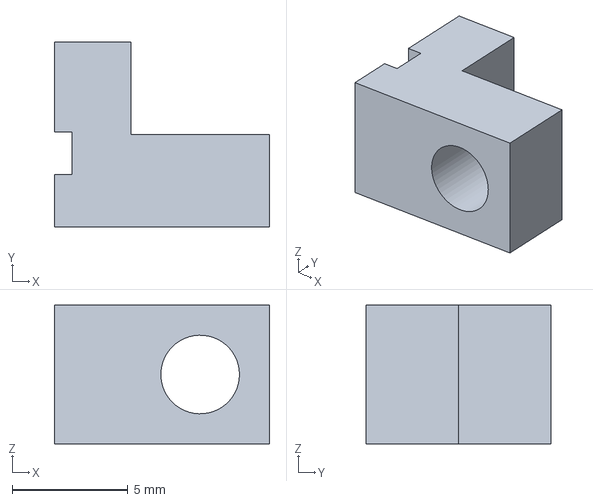
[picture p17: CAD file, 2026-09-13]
hardware/bench/package/fixture/encoder_edge_clip.step
9.30 x 8.00 x 6.00 mm

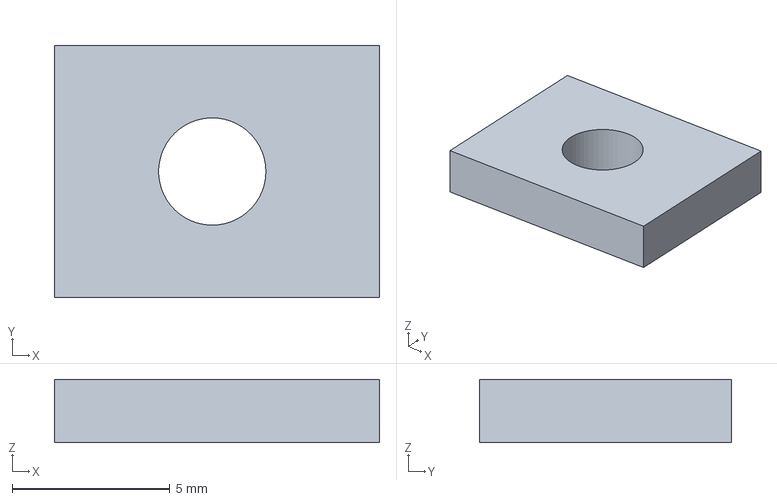
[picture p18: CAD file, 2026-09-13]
mechanical/bench/generated/edge_cap.step
10.3 x 8.00 x 2.00 mm

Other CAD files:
hardware/bench/package/fixture/base_1_1.step
hardware/bench/package/fixture/base_1_0.step
mechanical/bench/generated/encoder_clamp_base.step
hardware/bench/package/fixture/base_0_0.step
hardware/bench/package/fixture/base_0_0.stl
hardware/bench/package/fixture/base_0_1.stl
hardware/bench/package/fixture/base_1_0.stl
hardware/bench/package/fixture/base_1_1.stl
hardware/bench/package/fixture/button_lever.stl
hardware/bench/package/fixture/button_stop.step
hardware/bench/package/fixture/button_stop.stl
hardware/bench/package/fixture/edge_cap.stl
hardware/bench/package/fixture/edge_saddle.stl
hardware/bench/package/fixture/encoder_carrier.stl
hardware/bench/package/fixture/encoder_clamp_base.step
hardware/bench/package/fixture/encoder_clamp_base.stl
hardware/bench/package/fixture/encoder_clamp_cap.stl
hardware/bench/package/fixture/encoder_edge_clip.stl
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

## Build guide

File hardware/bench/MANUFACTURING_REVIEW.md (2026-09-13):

# Rev-A manufacturing handoff

## 2026-09-13 working revision

Latest revision includes all-layer pad/via-entry and near-tangent-cap fixes,
plus removal of the Wheel ADC2_MISO_LOCAL loop. See COPPER_JOIN_REVIEW.md.

Routing cleanup changed the working boards and regenerated exports after the
2026-09-12 submission. See [trace cleanup](TRACE_CLEANUP.md). The frozen archive
under `submissions/2026-09-12-jlc-cam/` remains the exact submitted revision;
the new working files have not been submitted. The Main-right tab and replacement Encoder-top tab now have individual full-width
board/frame checks. Copper joins use shared centerlines and retain nominal widths.
See COPPER_JOIN_REVIEW.md for the revised validation.
The earlier local-review statement below predates that finding.

Reviewed 2026-09-12. **Local review complete; JLC CAM confirmation pending.**
Five bare three-design panels and one stencil; no PCBA service. The user
authorized submission, and JLC's contact form confirmed receipt on 2026-09-12.
See [submission record](submissions/2026-09-12-jlc-cam/receipt.json) and the
frozen archive beside it. CAM approval is still pending. No order or payment
was made, and the historical price has not been refreshed. Other supplier
communications remain drafts.

## Findings and corrections

- Corrected the exported Gerber-job envelope from 151.05 x 139.05 mm (including
  drawing strokes) to the actual profile centerline size of **151 x 139 mm**.
- Corrected its impedance-service flag to **false**, matching the selected
  economy order. The 90 ohm design target, USB geometry and exact stack remain.
- Removed automatically inferred design-rule metadata, including zero-clearance
  entries that could be mistaken for fabrication permissions. Actual copper and
  all existing DRC/electrical acceptance records are unchanged.
- Generated an explicit open-hole inventory and colour-coded via-treatment map.
  The Excellon round holes and all four USB anchor slots match the board.
- Retained the selected uniform 0.10 mm stencil and the three existing groups.
  No aperture resizing or automatic rearrangement is authorized.

## Published capability screening

JLC lists 2 mm panel separation, at least 5 mm mouse-bite tabs, 0.5–0.8 mm bite
diameters and 0.2–0.3 mm webs. Our panel uses 2 / 5 / 0.6 / 0.3 mm respectively.
Minimum component-hole annulus is 0.20 mm; minimum trace width is 0.1466 mm.
These fit the published multilayer 1 oz ranges. See
[JLC capabilities](https://jlcpcb.com/capabilities/Capabilities).

There are **1,114 vias to fill/cap**: 641 at 0.20 mm, 472 at 0.30 mm and one
at 0.40 mm. All are within JLC's published epoxy-filling diameter guidance.
There are **109 plated component holes/slots and 56 NPTH holes to leave open**.
The 86 new wire holes are included in that 109. The fill selection applies to
actual vias only; use Excellon ViaDrill/ComponentDrill attributes and both CSVs.
[JLC via covering guidance](https://jlcpcb.com/help/article/pcb-via-covering).

JLC offers 0.10 mm as a standard stencil thickness and accepts several designs
in one paste file. The 151 x 139 mm layout fits the requested 220 x 200 mm sheet
with room for the published approximately 8 mm machining-clamp allowance.
Preserve group positions; a global centering translation is acceptable.
[JLC stencil instructions](https://jlcpcb.com/help/article/instructions-for-stencil-order).

Existing native DRC/parity and strict electrical reports match current source
hashes. This pass adds manufacturing checks; it does not repeat electrical
routing work. Small reference text may lose detail in printing; use the
placement and numbered wire-pad drawings during assembly.

## What JLC must check in the production files

1. **Exact construction:** JLC041611-2116, nominal 1.6 mm, nominal 1 oz inner
   and outer copper. STACK_AND_LAYERS.md carries the actual CAD layer table,
   including 0.109 mm outer dielectrics and 0.030 mm modeled inner copper.
   The public stack page did not expose this exact identifier during this
   review; retain the previously quoted selection and require confirmation.
   No substitution to another stack or half-ounce inner copper is authorized.
2. **Routed profile and tabs:** mill the supplied outline, preserve all three
   unit envelopes and ten tabs. Confirm the supplied 2 mm cutter / 1 mm internal
   radius geometry described in ROUTER_REVIEW.md before any CAM changes.
   Depanel before population.
3. **Hole treatment:** fill/cap only the listed actual vias. Keep component,
   wire, locating, tooling and perforation holes open. Select production-file
   confirmation so these treatments can be checked before fabrication.
4. **Stencil:** 0.10 mm, top only, supplied apertures as-is. Preserve the three
   groups and their relative orientation. If a rearrangement is unavoidable,
   return final coordinates before the alignment jig is used.

These are the normal manufacturing handoff items. Wire fit, lens mounting,
magnet calibration, practice printing and oven setup are assembly tasks and
do not add further bare-board ordering gates.

## Handoff files

The exact submitted bundle is preserved in
`submissions/2026-09-12-jlc-cam/CAM-review-attachments.zip`. The exported
`package/supplier-drafts/JLC_CAM_REVIEW.md` remains the prepared request;
its draft label and the exported package bytes were preserved after submission.
The contact-form cover requested the same manufacturing review and included
the PCB, stencil and complete bundle hashes. The bundle contains the PCB and
stencil ZIPs, exact settings, layer/stack table, profile drawing, hole-treatment
map and inventories, and stencil/jig review files. Its internal hash manifest
identifies each attachment; `package/file-sha256.json` identifies the complete
repository export. No supplier reply or approval is implied by this package.

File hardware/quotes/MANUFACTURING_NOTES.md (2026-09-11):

# MagMouse assembly pricing inputs

**QUOTE ONLY — NOT FOR FABRICATION OR ASSEMBLY.**

Request five assembled Main boards, five Wheel boards and five Encoder boards,
delivered together to Croatia, 43000. These are three separate jobs, one design
per job. No production panel, breakaway tooling, panel BOM or panel-coordinate
CPL is supplied. Quote any assembler handling panels, rails, tooling and fixture
charges separately. The small encoder may require a service panel for assembly.
Do not infer final manufacturing approval from the routed copper or file names.

## Board settings

| Job | Finished outline | Layers | Quote stack and finish | Via treatment |
| --- | --- | --- | --- | --- |
| Main | 125 mm long, 80 mm maximum width, 44 mm front | 4 | Nominal 1.6 mm, JLC041611-2116, 1 oz outer/inner, green solder mask, ENIG | All via holes epoxy-filled and copper-capped |
| Wheel | 55 × 60 mm | 4 | Same JLC041611-2116 stack and finish as Main | All via holes epoxy-filled and copper-capped |
| Encoder | 14 × 18 mm | 2 | Nominal 1.6 mm FR-4, 1 oz copper, green mask, ENIG quote assumption | Ordinary tented vias; see inventory for overlap check |

Main and Wheel preserve the selected four-layer CAD stack: 0.035 mm outer
copper, 0.109 mm 2116 RC54% prepreg, 0.030 mm In1 copper, 1.230 mm core dielectric,
0.030 mm In2 copper, 0.109 mm prepreg, 0.035 mm outer copper. The saved thickness
is 1.578 mm, including two 0.010 mm mask layers. Select the supplier's nominal
1.6 mm JLC041611-2116 option; ask engineering to confirm this exact construction
against the saved stack instead of substituting a generic four-layer stack.

The Encoder source specifies two layers and 1.6 mm, with no detailed saved
dielectric stack or finish. Its copper weight and ENIG above are explicit quote
assumptions. It has not been migrated to the common four-layer panel stack.
The Gerber-job bounding box can include Edge.Cuts line thickness (for example
80.1 × 125.1 mm); finished dimensions are measured at the outline centreline.

## Main USB controlled impedance

Request **90 Ω differential impedance, F.Cu referenced to continuous GND on
In1.Cu**, on Main's USB D+/D− path from J1 through U1 ESD protection and R67/R68
series resistors to U3 ESP32-S3. The selected coupled geometry is **0.1466 mm
trace width / 0.1501 mm edge-to-edge pair gap** on JLC041611-2116. Local pad
launches and component interruptions are present in the routed data path.
Quote the supplier's guaranteed tolerance and impedance coupon/test charge
explicitly; this package does not invent a guaranteed tolerance. Confirm any CAM
width/spacing compensation before production. Do not change the stack or thin
the ground reference to fit a cheaper service. Wheel uses the same stack for
consistency; it has no USB pair or separate controlled-impedance target.

## Via filling and capping

Quote **all actual through vias on Main and Wheel** as epoxy-filled and
copper-capped (planar solderable surface on both outer layers). This deliberately
avoids relying on selective filling to estimate cost. Tenting or solder-mask
plugging alone does not satisfy this request. Do not copper-fill an entire via
unless quoted as a separate alternative; the baseline is nonconductive epoxy
fill with copper caps.

Each job includes `all-vias.csv`, `via-in-pad.csv` and a top-view `via-map.svg`.
The inventory checks intersection of the actual drill disk with SMD pad copper,
including off-centre edge overlaps and bare test pads. Red points are these
overlaps; grey points are other vias. SVG hover text identifies each via and
pad, and the CSV gives UUID, drill/pad diameters, net and exact coordinates.
All Main/Wheel vias are covered by the quote request even if absent from the
smaller overlap table. The overlay is a location aid, not a Gerber machining layer.

**Do not fill component holes, USB shell slots, optical-sensor through holes,
connector holes, or NPTH alignment/mechanical holes.** Excellon X2 tool attributes
distinguish ViaDrill from ComponentDrill; the exporter verifies every via hit
against the CAD inventory. The CSV's Gerber/CPL coordinates use the drill-file
origin. Confirm ambiguous holes by position, not by diameter alone.

The CAD defaults still show tenting with filling/capping disabled; the exported
Gerbers do not by themselves specify the required additional process. These
written notes and the order's filled/capped selection are required for the quote.
Request supplier production-file confirmation of the via map and cap treatment
before any eventual order. Exposed-pad solder coverage, stencil apertures,
cap planarity and paste wicking still require manufacturing review.

## Assembly files and reference coverage

Upload each job's `*-Gerbers-QUOTE.zip`, `*-BOM-QUOTE.csv` and `*-CPL-QUOTE.csv`
as a matched set. They use one common **absolute KiCad origin**, X to the right
and Y upwards: CPL/Gerber Y is negative KiCad Y. Negative coordinates are
intentional. Gerbers, drills and CPL must receive the same translation if CAM
normalizes the outline. Coordinates are millimetres, with no bottom X mirroring.

CPL rotation is KiCad's native footprint rotation normalized to 0–360 degrees.
Supplier-library rotation and centroid corrections are not applied. Inspect the
JLC placement preview against `assembly-F.svg`, `assembly-B.svg`, pad 1 and the
actual footprint before accepting assembly; coverage validation alone cannot
prove feeder orientation. All quoted physical components are on the top side;
back-side copper test pads are not separate assembly parts.

J1 has through-hole shell anchors as well as SMT contacts. Ask the assembler to
include or explicitly exclude anchor soldering. Review connector handling,
exposed pads, MSL/baking, polarity and the custom RGB footprint. No added tooling
holes/fiducials or component substitutions are authorized by this package.

The BOM carries exact schematic MPNs and catalog IDs. **These are matching
requests, not live stock or assembly-service confirmations.** Retain the
manufacturer identity and ratings when matching. `procurement-review.csv`
preserves recorded sourcing status for every physical source component and
lists five-board quantities, excluding any supplier attrition allowance.
`excluded-from-assembly.csv` accounts for every omitted source reference.

Main U35 PMW3360DM-T2QU is excluded from both the uploaded BOM and CPL because
the recorded sourcing decision is customer supply/post-assembly installation.
It remains in the procurement list (catalog C20612443, recorded unavailable).
Ask for a separate sensor-supply/installation line if the assembler can accept
it. Its price is **not included** by the standard SMT quote. The LM19-LSI lens
is a separate optical/mechanical item, not an SMT placement. Copper-only test
pads are also excluded; no other physical component is silently omitted.

## Price scope and remaining release work

Request itemized PCB, setup, stencil, assembly, selected components, special via
processing, impedance testing, any service panel/fixtures, shipping and tax.
Record unpriced or unmatched components explicitly. Five sets means five of
each of the three designs, not five boards total. No current PCBA total has
been obtained from these files merely by generating them.

Keep separate cost lines for sensor/lens, FFC and JST harnesses, GB1806 motor,
shaft/bearings, magnets, wheel, coils, shell, assembly labour and test fixtures.
The old $179.47 five-panel bare-PCB calculator figure applies to a different,
provisional nesting study and is not a quote for these jobs.

Before release: freeze mechanical interfaces and cables, adjust PCBs, repeat
whole-board electrical/thermal/return reviews, migrate Encoder if sharing a
four-layer panel, finalize tooling/tabs and manufacturing details, match parts,
review rotations, regenerate all files and approve supplier production files.
This quote pass changes no board/schematic and starts no panelization.

## Supplier guidance checked 2026-09-11

- [JLCPCB KiCad 10 BOM/CPL export](https://jlcpcb.com/help/article/how-to-generate-the-bom-and-centroid-file-from-kicad): file columns and native KiCad export workflow.
- [JLCPCB BOM/CPL preparation](https://jlcpcb.com/help/article/advice-for-bom-and-cpl-files-preparation): matching reference designators and component review.
- [JLCPCB via covering](https://jlcpcb.com/help/article/pcb-via-covering): filled/capped options and identifying vias with drawings/order notes.

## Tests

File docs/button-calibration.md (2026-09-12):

# Rev-A button calibration

This is the bring-up contract, not implemented firmware. Magnets are secured
to their moving levers; their exact field strengths do not need to match.
Keep the Hall IC positions, passive return and physical end stops. Optical
height and wheel encoder alignment are independent mechanical requirements.

## Capture and conversion

With all actuators disabled, calibrate each of the three buttons separately.
Record at least 0.5 seconds of stationary ADC samples at released and fully
pressed positions. Store the mean and standard deviation of each capture,
the raw minimum/maximum, sample count and acquisition settings. Repeat each
endpoint three times to check the mount and stop repeatability.

Let `R` be the released mean and `P` the pressed mean. Calculate
`position = (raw - R) / (P - R)`. Either sign of `P - R` is valid. The
result is normalized sensor travel, not a linear displacement measurement.
Preserve the raw reading and unclamped result for diagnostics; clamp to 0..1
only for normal button processing.

Reject zero/invalid span, ADC or Hall clipping, unstable endpoints and a span
smaller than ten times the larger endpoint standard deviation. Use one ADC
count as the minimum noise estimate when a capture quantizes to a constant.
Endpoint repetitions must agree within 5% of the span. These are provisional
bench acceptance thresholds and should be recorded alongside the calibration.

Sweep the complete physical travel slowly. Reject reversals, saturation or
mechanical contact with the sensor. Two endpoint measurements cannot correct
a non-monotonic field or a loose magnet. Repeat the sweep after the fixture
has been disturbed and after the first heating tests.

## Button state and persistence

Start with press at 0.60 and release at 0.40. Retain the previous state between
thresholds. Initialize to released with haptics disabled until valid readings
and calibration are available. A pressed startup position must not trigger
an automatic haptic pulse.

Persist a versioned record per button and physical unit containing endpoints,
noise, polarity, capture settings and thresholds. Validate finite values,
nonzero span, threshold order and record integrity when loading. An invalid
record leaves that button/haptic channel disabled and reports calibration
required; unrelated optical/USB diagnostics may continue. Recalibration is an
explicit action, never silent adaptation to a held button.

## Powered verification

Verify repeated clicks, slow travel and resting noise first. Then operate one
coil at a time, the wheel alone and the combined mechanisms with bounded
current. Record false transitions and sensor disturbance at both endpoints
and around the thresholds. Static calibration does not cancel time-varying
actuator fields or establish a force/current map. Correct excessive physical
interference before accepting the device; do not hide it by silently moving
thresholds. Verify passive release with power removed.

No firmware implementation, final paddle mechanics or hardware acceptance is
claimed by this procedure.

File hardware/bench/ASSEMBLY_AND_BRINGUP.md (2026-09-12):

# Rev-A self-assembly and bring-up

This is a bench prototype with U32 deliberately omitted. Preserve all power
protection, brake, drivers, ADCs and buffers. Internal connectors are replaced
by nine bare through-hole wire arrays. Match the purchasing variant
to the generated reference map; R25 uses the documented Vishay substitute.

## Equipment and preparation

The user supplies tools: temperature-controlled reflow for at least an
individual 125 x 80 mm board, magnification, fine tweezers, soldering iron,
hot-air rework, temperature probe, multimeter and current-limited bench supply.
A scope is needed for USB reference, rail ramps, SPI timing and brake tests;
it is not replaced by a continuity meter. Fresh paste, flux, wick and cleaning
supplies remain consumables in the project budget. Follow the chosen paste
and each part's moisture/reflow limits, not a universal temperature recipe.

Practice printing, placing and reflowing a fine-pitch/hidden-pad exercise board
first. Inspect the paste before placing expensive parts. Do not rely on an
iron alone for underside joints. Optical inspection cannot prove every hidden
joint is wetted; abnormal current or temperature requires investigation.

## Assembly sequence

1. Support and cut each bare board from the panel. Keep cutting dust away from
   contacts, inspect the cut edge and clean before paste application. Remove
   residual tab material without cutting inside the unit's original outline.
2. Hold each unit flat in a room-temperature stencil jig. Use the matching
   region of the shared stencil and cover the unused regions. Align with pad
   outlines/pin-one drawing; prevent stencil motion during the single print.
3. Inspect for bridges and insufficient deposits. Populate the small hidden-pad
   parts first, then passives and remaining reflow-qualified parts. Keep U32
   empty. Confirm IC/diode/LED/capacitor orientation against the annotated
   drawing and package marking before reflow.
4. Reflow one unit at a time using a measured profile. Verify the USB connector and
   the polymer capacitor are within their specific reflow limits. Solder USB
   shell anchors and any intended hand-solder joints separately as needed.
5. Hand solder the 46 mapped wire conductors and designated USB anchor joints.
   No paste belongs on the 86 wire holes. Support the depanelled board with
   underside access. Keep stripping short, inspect each joint and trim ends
   below 1.5 mm. Attach printed strain-relief clamps to the fixture and retain
   all ground wires. Check the component-side and mirrored solder-side maps,
   continuity of each conductor, and isolation between unlike nets before
   powering the assembly. Never use cable colour alone as a pin-number check.
6. Fit PMW3360 after other soldering/cleaning. Keep the sensor aperture protected
   until lens fitting; use its specified lead-soldering process. Do not put the
   sensor or lens through a generic board reflow profile. Fit the matching lens
   and clean only by the optical manufacturer's permitted method.

## Bring-up gates

Record supply voltage/current, firmware version, observations and pass/fail
for each gate. Power off before changing internal cables or test wiring.

| Gate | Check and stop condition |
| --- | --- |
| Unpowered | Inspect polarity/hidden-pad alignment, resistance between every rail and GND, cable continuity and no adjacent-contact shorts. Investigate unexpected low resistance before power. |
| Logic supply | Motor and coils disconnected. Feed through the intended protected power entry with a suitable current-limited USB/source fixture. Verify logic rails and actuator-off reset defaults; do not inject a bench supply backwards into an attached host. Stop on current limiting, incorrect rail voltage or rapid heating. |
| USB | Enumerate repeatedly with actuators off. Exercise movement reports and reconnects on more than one host/cable. No paid impedance service means no guaranteed 90-ohm acceptance. |
| ADC1/Hall | Verify references and idle readings, then move one magnet at a time with mechanical stops. Record noise before any PWM activity. |
| Optical | Verify both rail ramps, correct product identity and permitted SROM initialization. Measure X/Y against the slider scale at the received lens's specified working height. |
| Encoder/ADC2 | Confirm angle direction, magnetic-field range, ADC references and idle phase readings. Check buffered SPI at both boards, starting slowly; do not assume the longer bench cable meets the final control-loop schedule. |
| Motor/brake | Secure motor and encoder first. Use bounded low-current commands and the design's source-current budget. Measure phase-current offsets and brake behavior, rail rise and temperatures before increasing torque. Never drive the motor with unverified current feedback. |
| Button pulses | Connect one measured coil at a time. Start with bounded short, low-current pulses and cool-down intervals. Verify current feedback, hard stops and temperature before combining channels. |

Specific operating limits must come from the implemented bring-up firmware,
coil/motor measurements and existing electrical contracts. This document does
not invent a safe drive current or certify the hardware before it exists.

For each fixed button magnet, capture released/pressed endpoints with actuators
disabled and follow `button-calibration.md`. Reject clipping, unstable endpoints,
insufficient signal-to-noise separation and reversals through the full stroke.
Initial normalized thresholds are 0.60 press / 0.40 release. Repeat the test
with button coils and the wheel active before accepting them. Invalid or missing
calibration leaves that button's report and haptic output disabled. Persistent
per-unit firmware implementation remains a separate task.

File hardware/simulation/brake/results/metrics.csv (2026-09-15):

name | peak_rail_V | max_brake_response_us | peak_brake_current_A | peak_resistor_bank_W | resistor_bank_energy_J | average_regeneration_W | energy_balance_relative_error | peak_timestep_delta_V | energy_timestep_relative_delta | below_6p5V | response_within_10us
minimum_0.45us_pulse | 5.989998899281423 | 0.5527728782863447 | 0.5084025546835361 | 3.0370596019027642 | 0.002101293946519152 | 0.5815025544847926 | 1.3500607444169978e-05 | 0.0005663608198585024 | 5.9384279065741096e-05 | True | True
minimum_0.45us_repeated | 5.989998899281423 | 0.5702622200946805 | 0.5084025546835361 | 3.0370596019027642 | 0.004202583635133936 | 0.3578474739659966 | 9.714572156023967e-06 | 0.0005663608198585024 | 3.393725669123336e-06 | True | True
minimum_0.45us_unplug | 5.989998899281423 | 0.5527728782863447 | 0.5084025546835361 | 3.0370596019027642 | 0.002101293946519152 | 0.5815025544847926 | 1.3500607444169978e-05 | 0.0005663608198585024 | 5.9384279065741096e-05 | True | True
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

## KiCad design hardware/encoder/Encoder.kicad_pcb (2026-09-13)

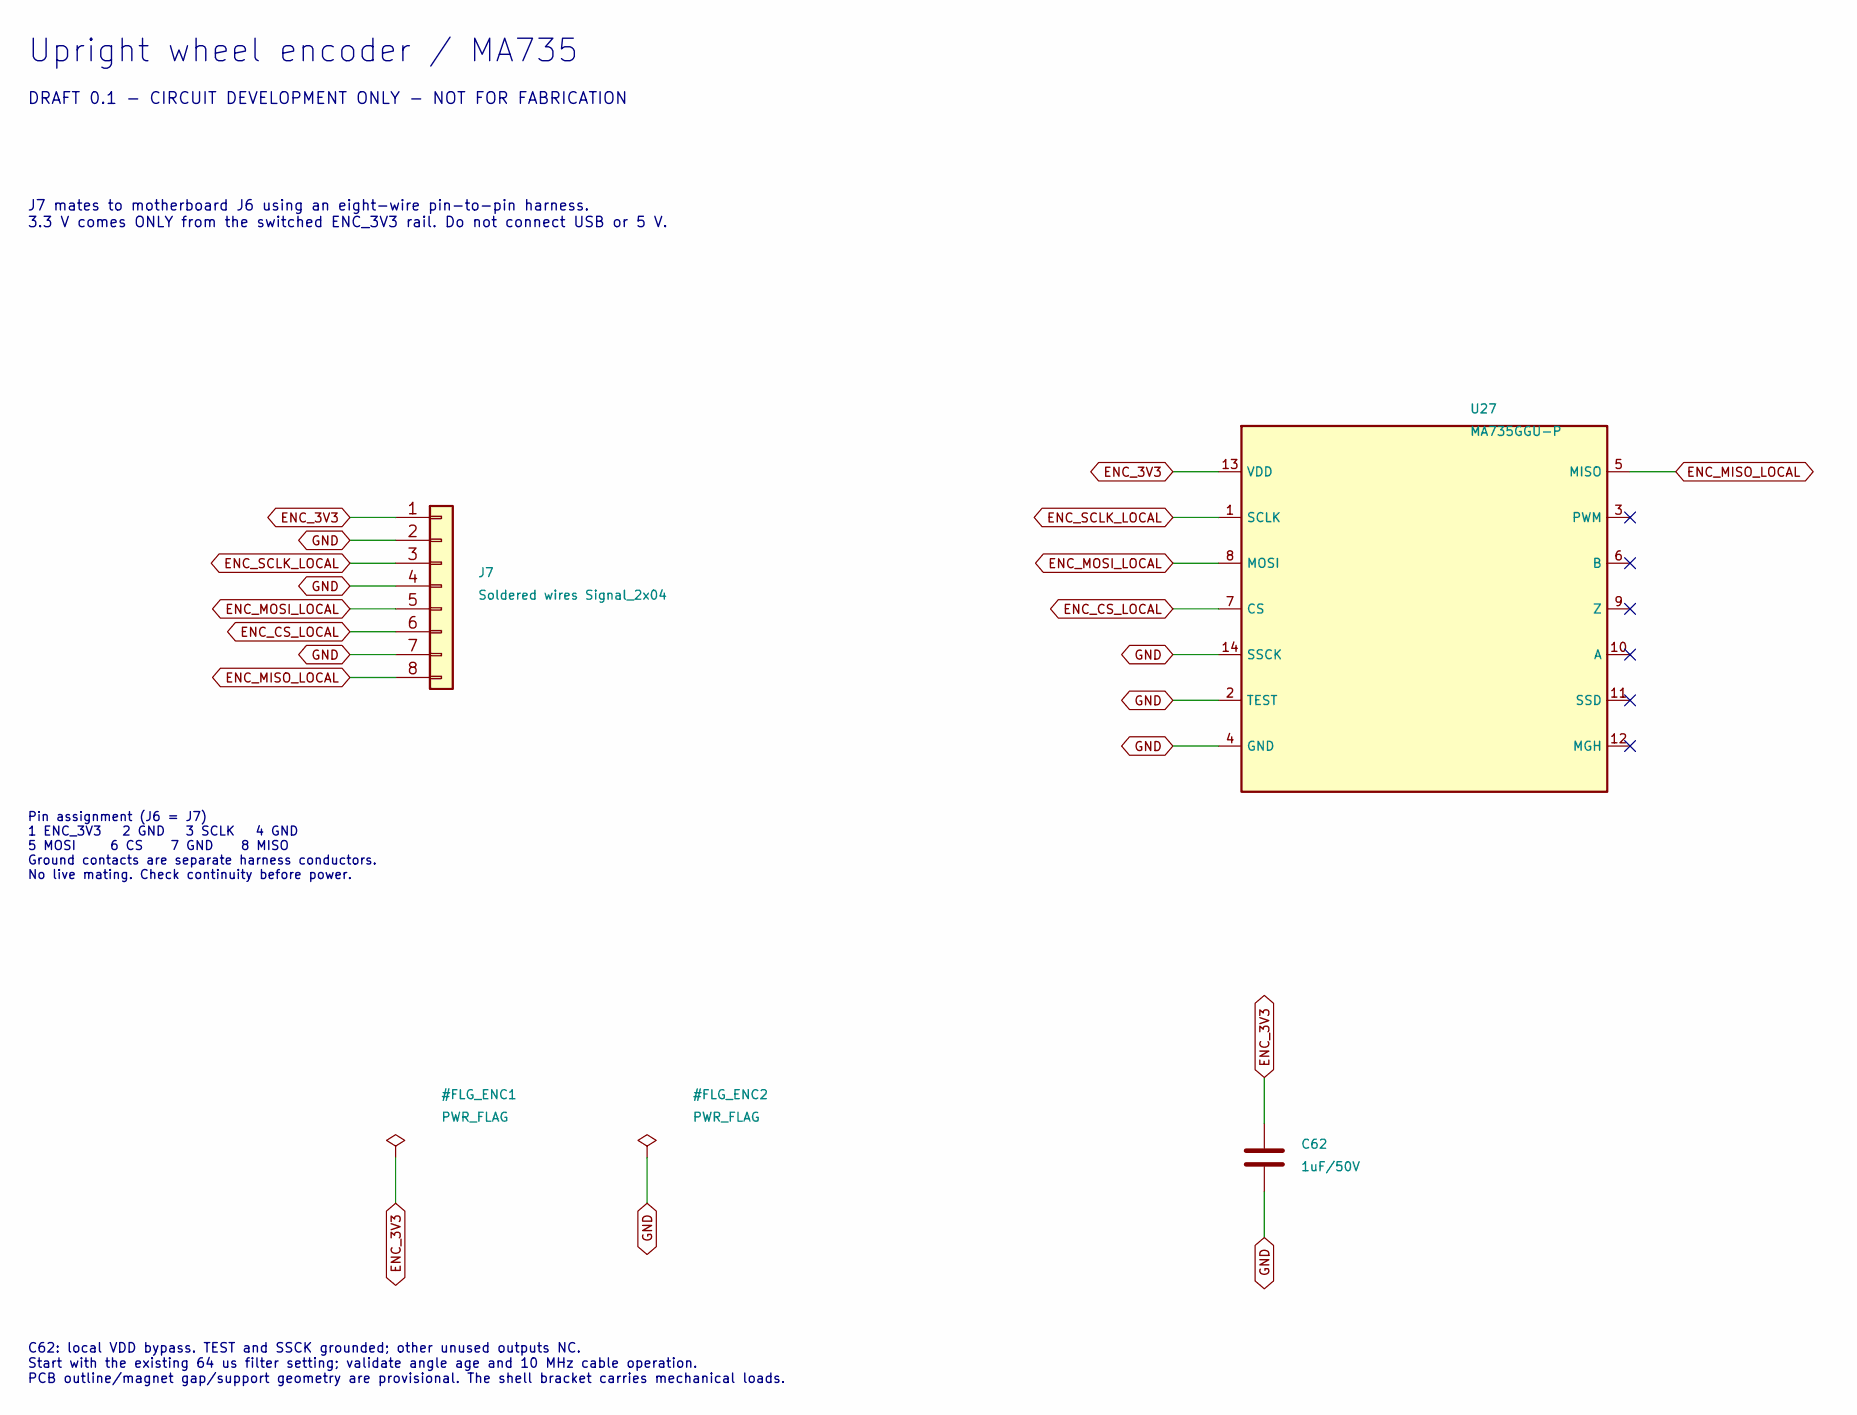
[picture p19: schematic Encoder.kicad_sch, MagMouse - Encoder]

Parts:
C62: 1uF/50V; C_0603_1608Metric; MPN CL10A105KB8NNNC; LCSC C15849
J7: Soldered wires Signal_2x04; Wire_Signal_2x04_P2.54mm
U27: MA735GGU-P; MPS_UTQFN14_2x2; MPN MA735GGU-P; LCSC C17233427

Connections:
ENC_3V3: C62.1, J7.1, U27.13 (VDD)
ENC_CS_LOCAL: J7.6, U27.7 (CS)
ENC_MISO_LOCAL: J7.8, U27.5 (MISO)
ENC_MOSI_LOCAL: J7.5, U27.8 (MOSI)
ENC_SCLK_LOCAL: J7.3, U27.1 (SCLK)
GND: C62.2, J7.2, J7.4, J7.7, U27.2 (TEST), U27.4 (GND), U27.14 (SSCK)

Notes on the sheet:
Upright wheel encoder / MA735
DRAFT 0.1 - CIRCUIT DEVELOPMENT ONLY - NOT FOR FABRICATION
J7 mates to motherboard J6 using an eight-wire pin-to-pin harness. 3.3 V comes ONLY from the switched ENC_3V3 rail. Do not connect USB or 5 V.
Pin assignment (J6 = J7) 1 ENC_3V3 2 GND 3 SCLK 4 GND 5 MOSI 6 CS 7 GND 8 MISO Ground contacts are separate harness conductors. No live mating. Check continuity before power.
C62: local VDD bypass. TEST and SSCK grounded; other unused outputs NC. Start with the existing 64 us filter setting; validate angle age and 10 MHz cable operation. PCB outline/magnet gap/support geometry are provisional. The shell bracket carries mechanical loads.

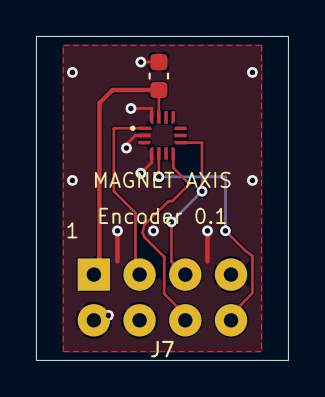
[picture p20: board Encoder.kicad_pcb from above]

Board: 4 copper layers, 14.0 x 18.0 mm, 3 parts (0 on the bottom side), 6 nets.

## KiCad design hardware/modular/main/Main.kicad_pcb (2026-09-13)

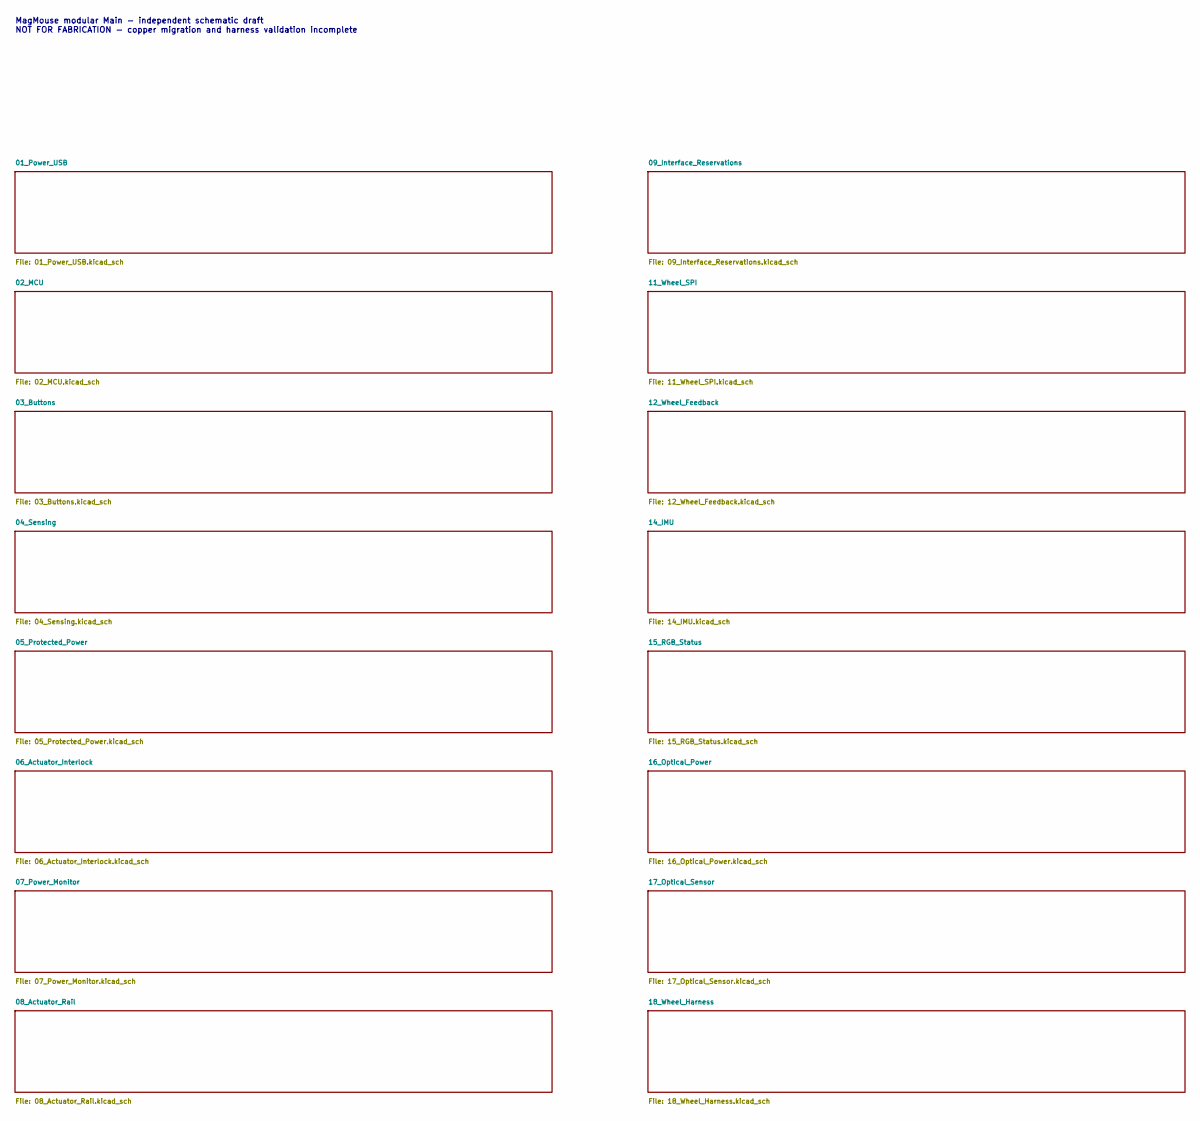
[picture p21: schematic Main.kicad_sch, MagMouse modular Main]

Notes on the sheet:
MagMouse modular Main - independent schematic draft NOT FOR FABRICATION - copper migration and harness validation incomplete

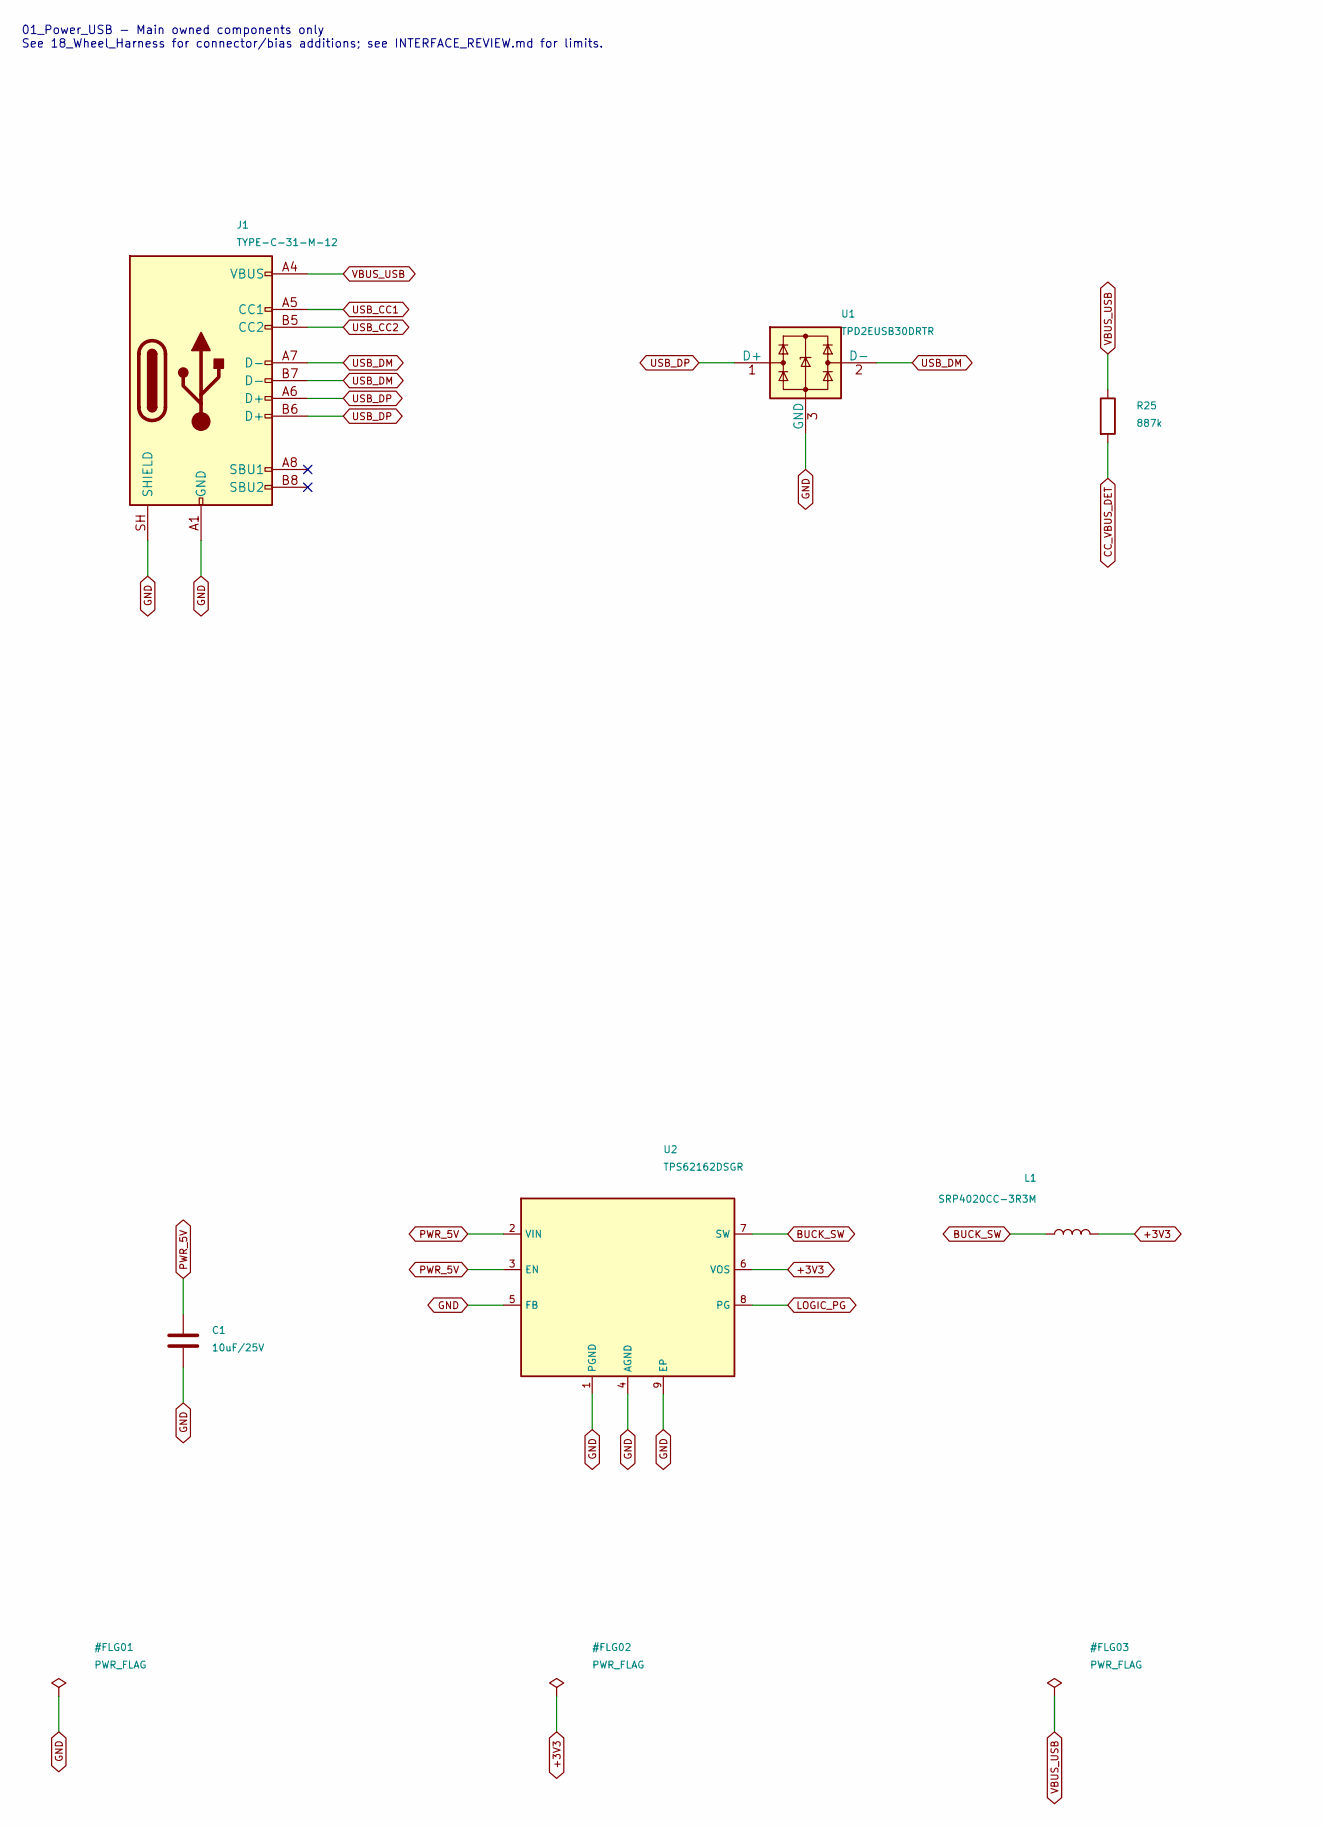
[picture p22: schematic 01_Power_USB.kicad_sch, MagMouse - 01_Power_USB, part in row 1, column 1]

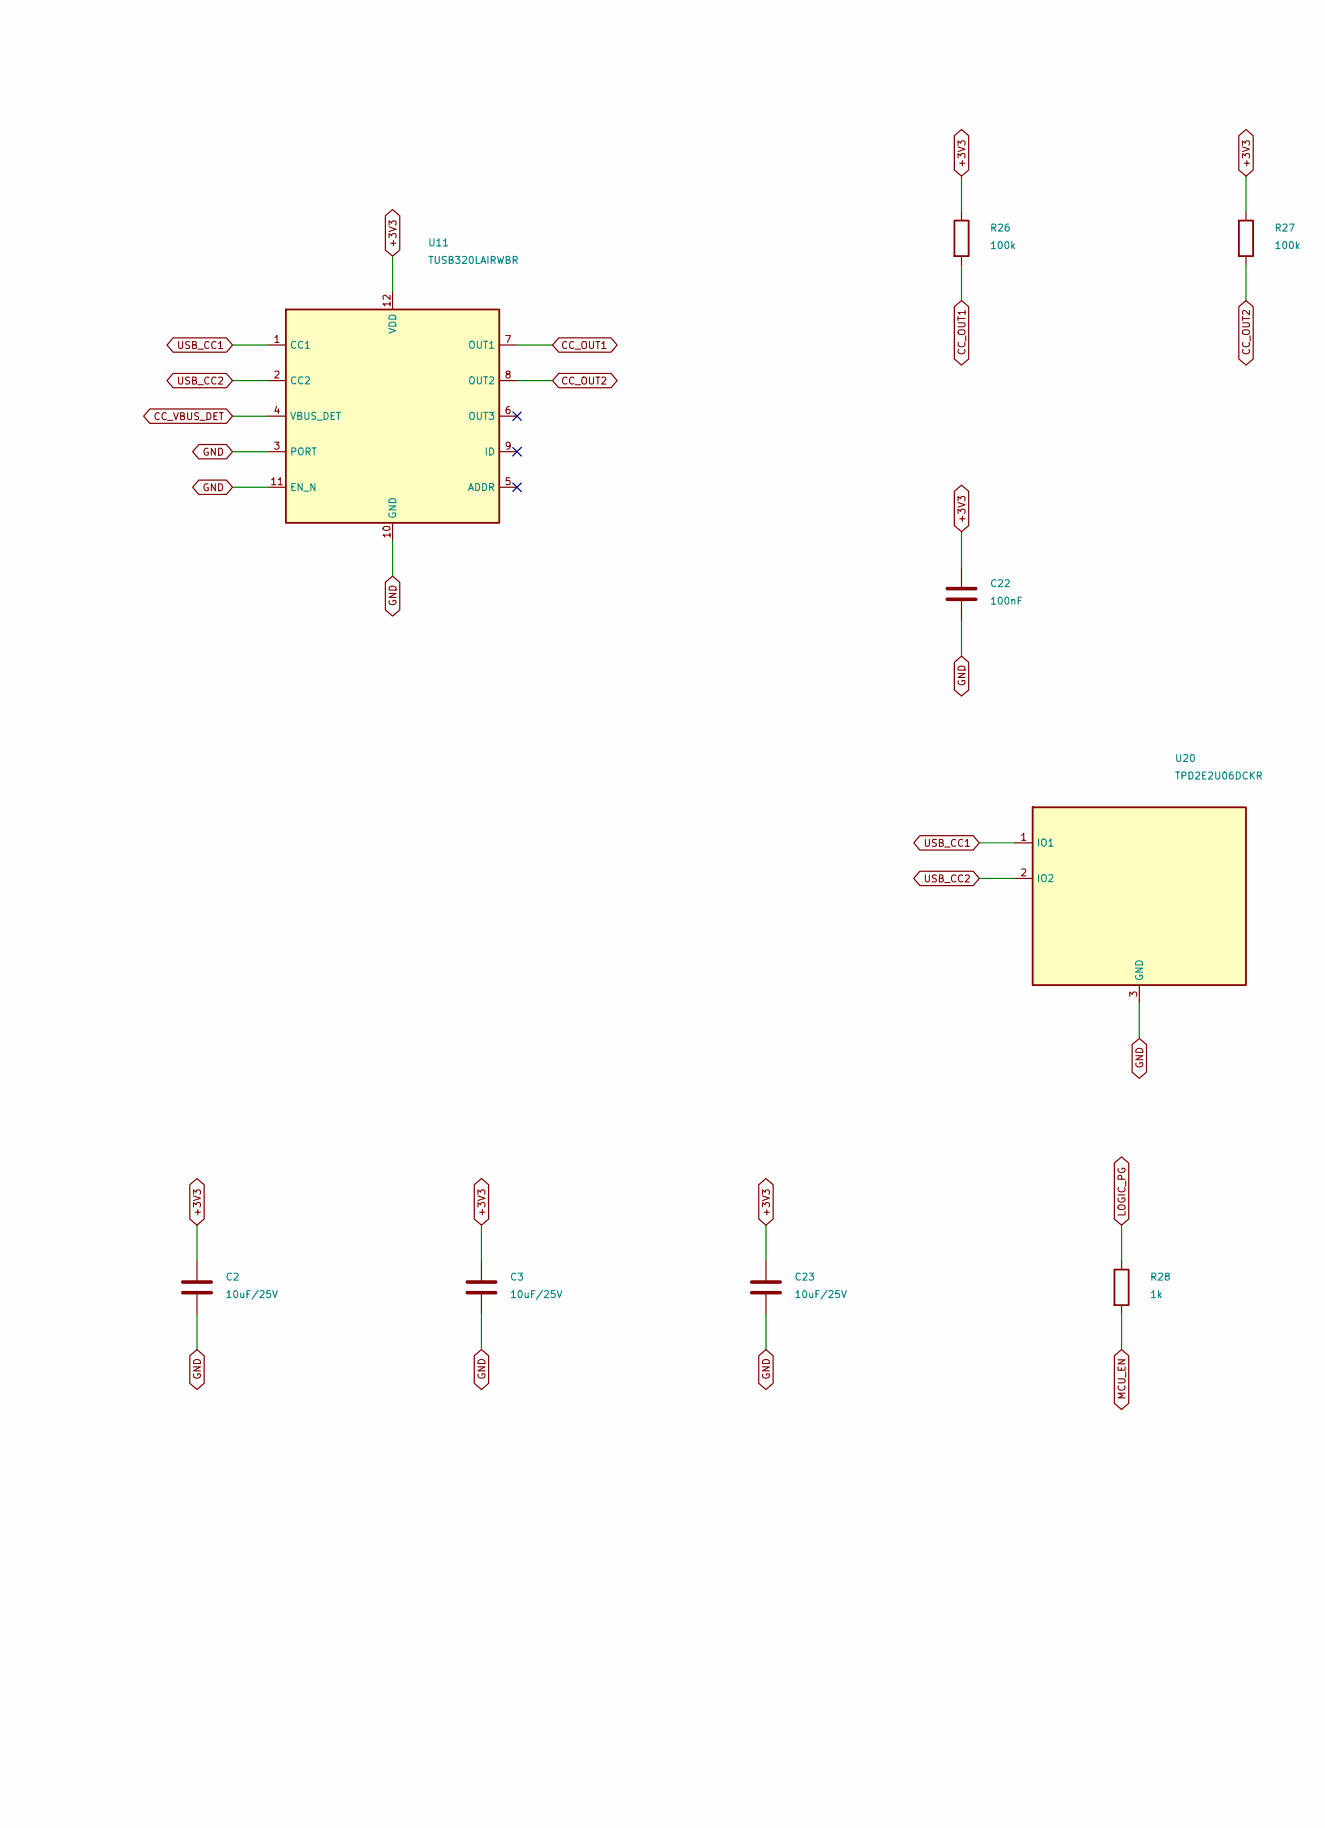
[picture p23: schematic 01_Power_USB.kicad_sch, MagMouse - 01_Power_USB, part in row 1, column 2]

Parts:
C1, C2, C3, C23: 10uF/25V; C_0805_2012Metric; MPN CL21A106KAYNNNE; LCSC C15850
C22: 100nF; C_0603_1608Metric; MPN CC0603KRX7R9BB104; LCSC C14663
J1: TYPE-C-31-M-12; USB_C_Receptacle_HRO_TYPE-C-31-M-12; MPN TYPE-C-31-M-12; LCSC C165948
L1: SRP4020CC-3R3M; L_Bourns_SRP4020CC; MPN SRP4020CC-3R3M
R25: 887k; R_0603_1608Metric; MPN 0603WAF8873T5E; LCSC C23259
R26, R27: 100k; R_0603_1608Metric; MPN 0603WAF1003T5E; LCSC C25803
R28: 1k; R_0603_1608Metric; MPN 0603WAF1001T5E; LCSC C21190
U1: TPD2EUSB30DRTR; Texas_DRT-3; MPN TPD2EUSB30DRTR; LCSC C97502
U2: TPS62162DSGR; Texas_DSG0008A_WSON-8-1EP_2x2mm_P0.5mm_EP0.9x1.6mm; MPN TPS62162DSGR; LCSC C40256
U11: TUSB320LAIRWBR; Texas_X2QFN-12_1.6x1.6mm_P0.4mm; MPN TUSB320LAIRWBR; LCSC C132554
U20: TPD2E2U06DCKR; SOT-323_SC-70; MPN TPD2E2U06DCKR; LCSC C1855726

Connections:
+3V3: C2.1, C3.1, C22.1, C23.1, L1.2, R26.1, R27.1, U2.6 (VOS), U11.12 (VDD); also elsewhere on the board
BUCK_SW: L1.1, U2.7 (SW)
CC_OUT1: R26.2, U11.7 (OUT1); also elsewhere on the board
CC_OUT2: R27.2, U11.8 (OUT2); also elsewhere on the board
CC_VBUS_DET: R25.2, U11.4 (VBUS_DET)
GND: C1.2, C2.2, C3.2, C22.2, C23.2, J1.A1 (GND), J1.A12 (GND), J1.B1 (GND), J1.B12 (GND), J1.SH (SHIELD), U1.3 (GND), U2.1 (PGND), U2.4 (AGND), U2.5 (FB), U2.9 (EP), U11.3 (PORT), U11.10 (GND), U11.11 (EN_N), U20.3 (GND); also elsewhere on the board
LOGIC_PG: R28.1, U2.8 (PG)
MCU_EN: R28.2; also elsewhere on the board
PWR_5V: C1.1, U2.2 (VIN), U2.3 (EN); also elsewhere on the board
USB_CC1: J1.A5 (CC1), U11.1 (CC1), U20.1 (IO1)
USB_CC2: J1.B5 (CC2), U11.2 (CC2), U20.2 (IO2)
USB_DM: J1.A7 (D-), J1.B7 (D-), U1.2 (D-); also elsewhere on the board
USB_DP: J1.A6 (D+), J1.B6 (D+), U1.1 (D+); also elsewhere on the board
VBUS_USB: J1.A4 (VBUS), J1.A9 (VBUS), J1.B4 (VBUS), J1.B9 (VBUS), R25.1; also elsewhere on the board

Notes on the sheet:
01_Power_USB - Main owned components only See 18_Wheel_Harness for connector/bias additions; see INTERFACE_REVIEW.md for limits.

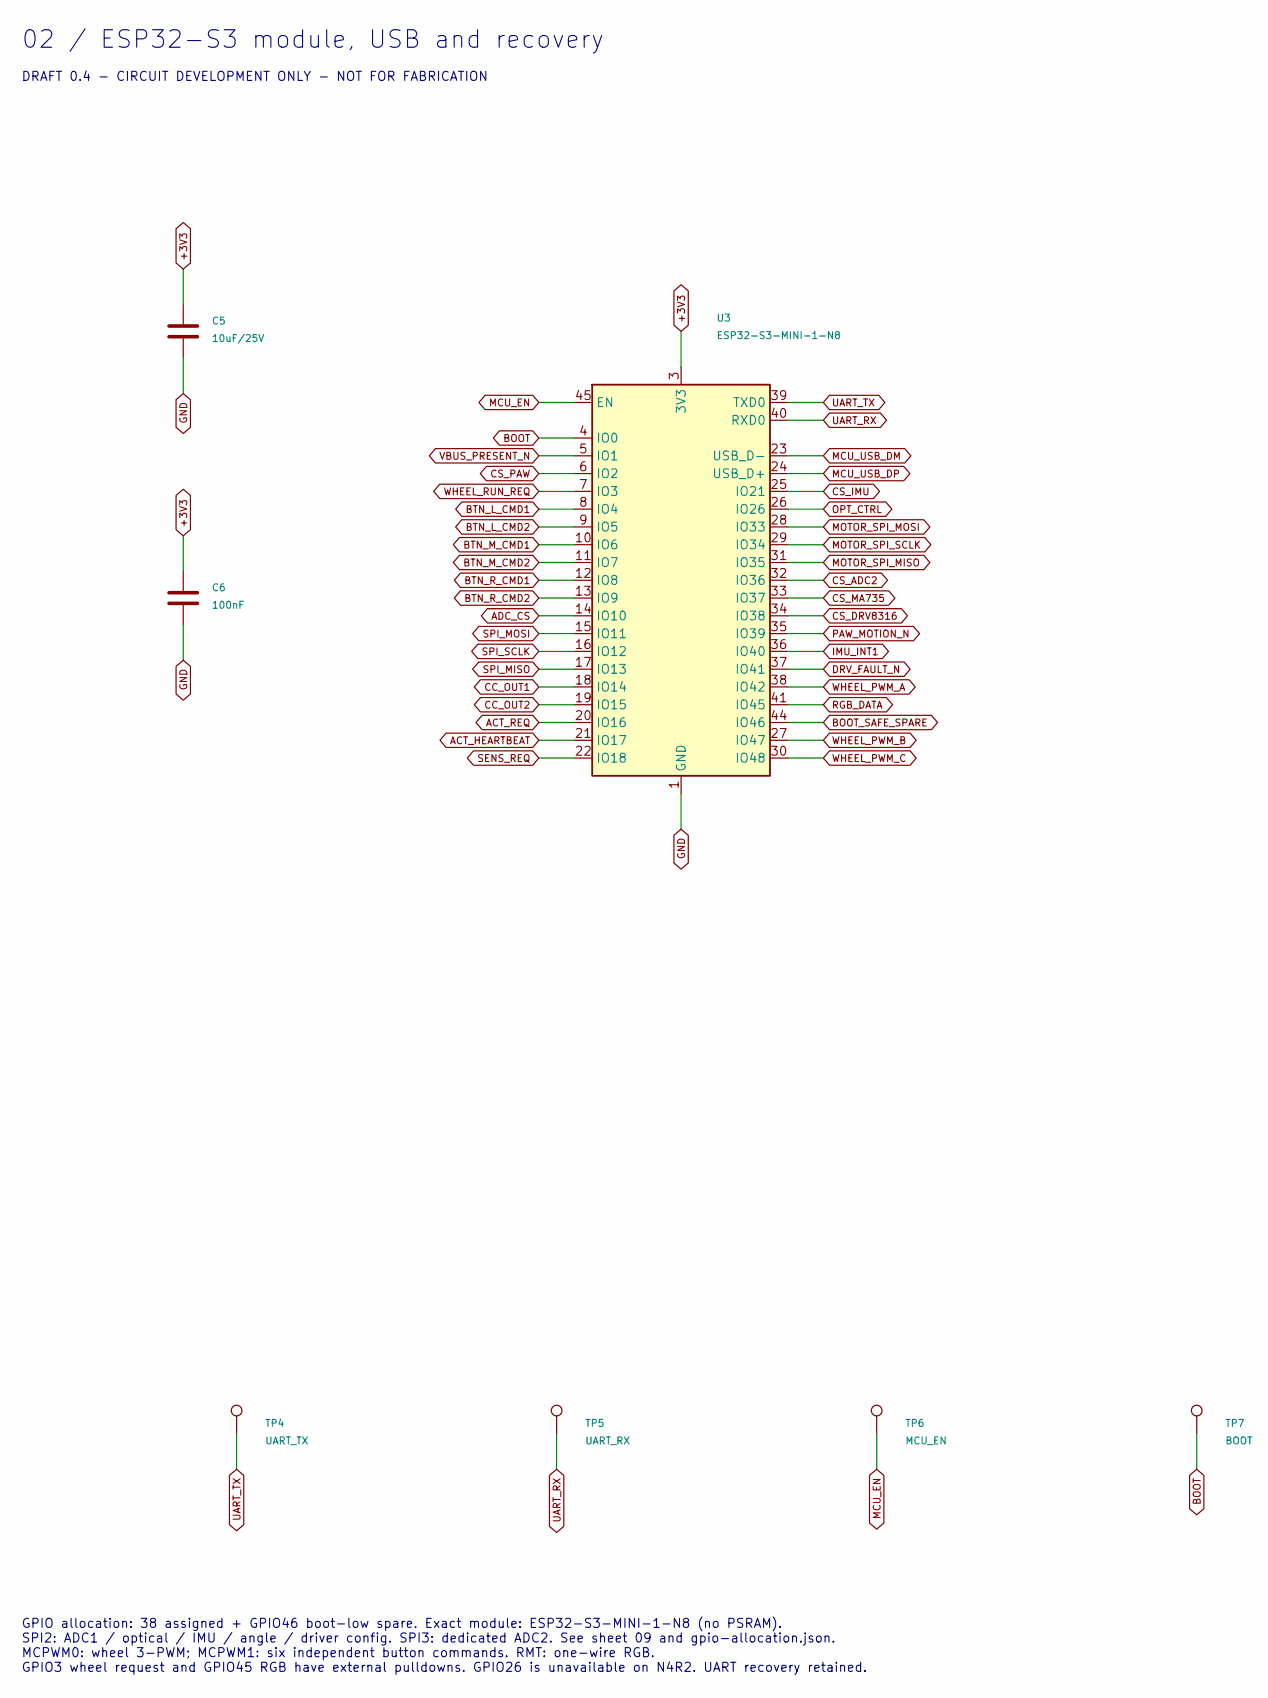
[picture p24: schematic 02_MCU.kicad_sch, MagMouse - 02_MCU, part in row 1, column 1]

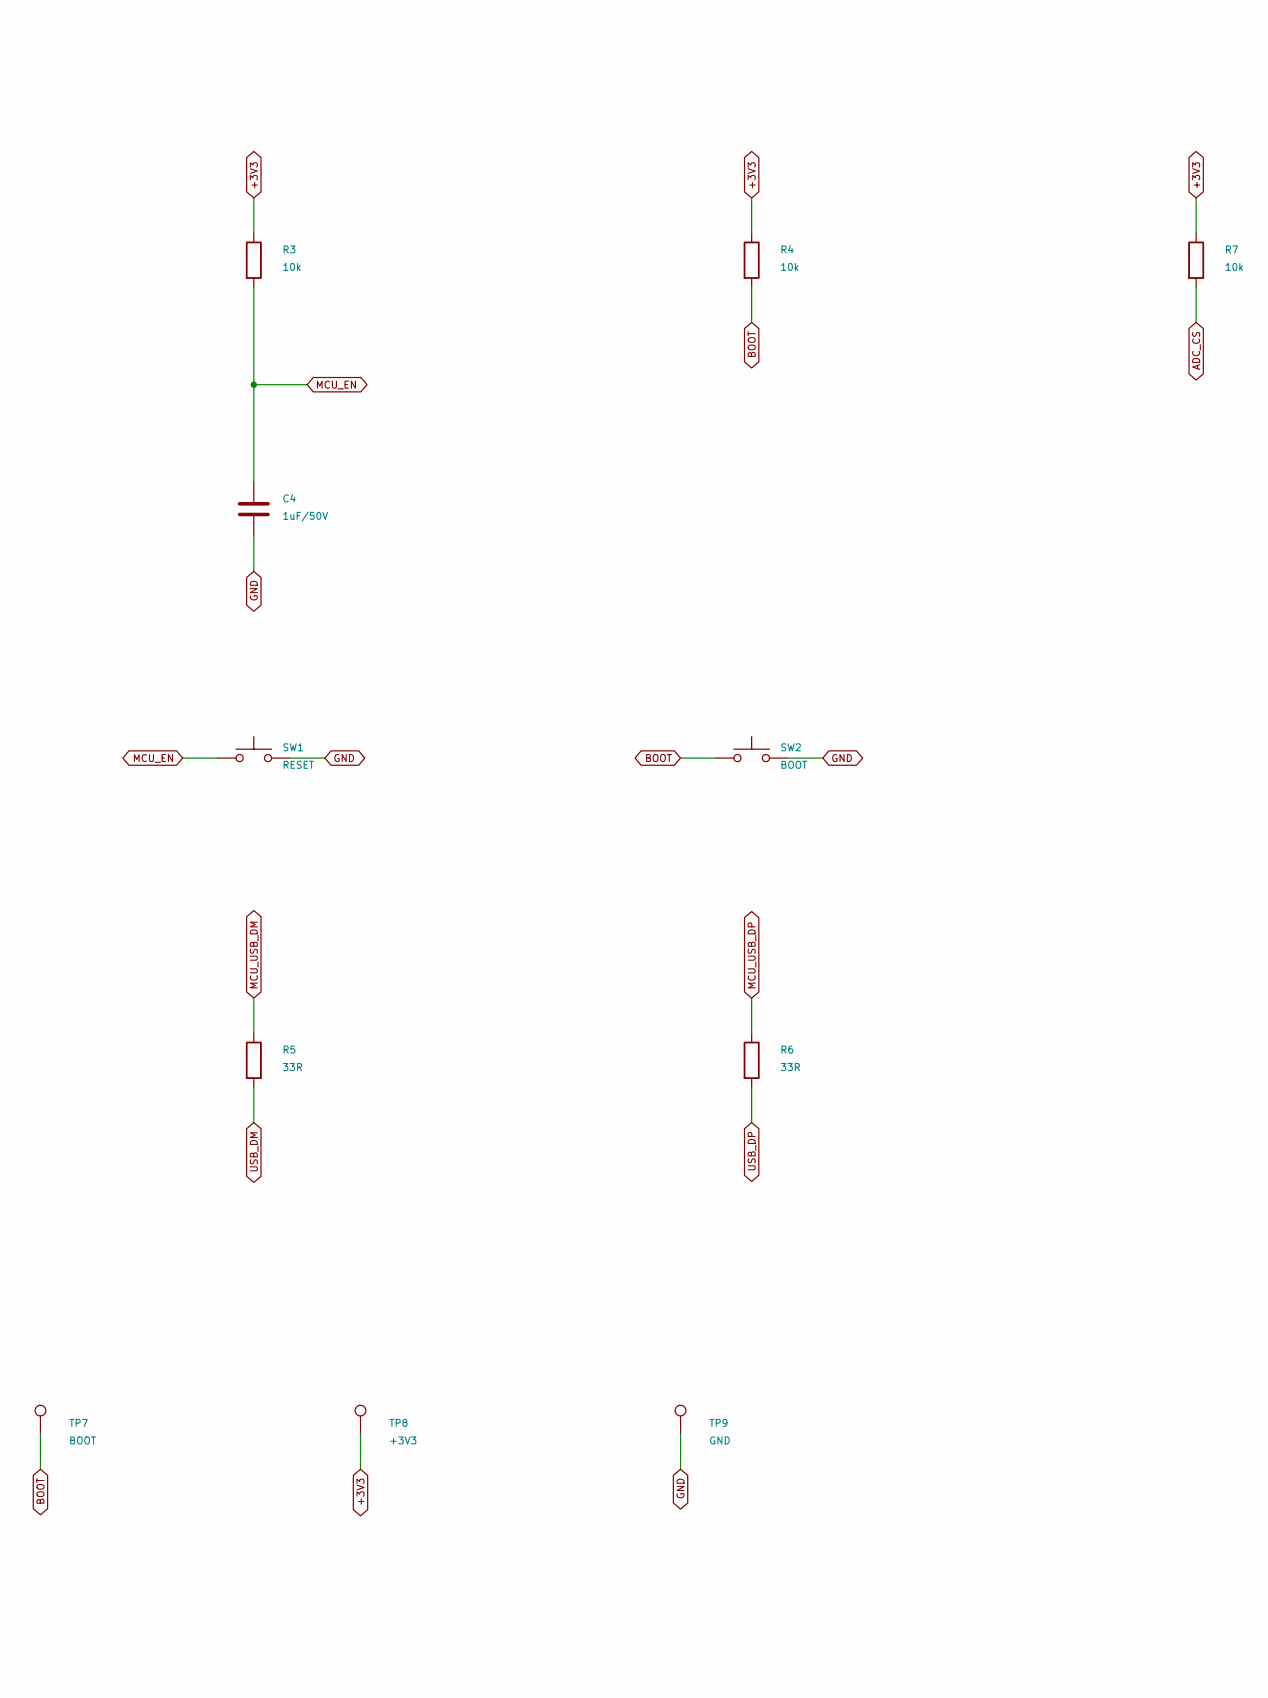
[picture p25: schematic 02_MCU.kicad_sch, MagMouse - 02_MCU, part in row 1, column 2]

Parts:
C4: 1uF/50V; C_0603_1608Metric; MPN CL10A105KB8NNNC; LCSC C15849
C5: 10uF/25V; C_0805_2012Metric; MPN CL21A106KAYNNNE; LCSC C15850
C6: 100nF; C_0603_1608Metric; MPN CC0603KRX7R9BB104; LCSC C14663
R3, R4, R7: 10k; R_0603_1608Metric; MPN 0603WAF1002T5E; LCSC C25804
R5, R6: 33R; R_0603_1608Metric; MPN 0603WAF330JT5E; LCSC C23140
SW1: RESET; SW_SPST_TS-1088-xR020; MPN TS-1088-AR02016; LCSC C720477
SW2: BOOT; SW_SPST_TS-1088-xR020; MPN TS-1088-AR02016; LCSC C720477
TP4: UART_TX; TestPoint_Pad_D1.0mm
TP5: UART_RX; TestPoint_Pad_D1.0mm
TP6: MCU_EN; TestPoint_Pad_D1.0mm
TP7: BOOT; TestPoint_Pad_D1.0mm
TP8: +3V3; TestPoint_Pad_D1.0mm
TP9: GND; TestPoint_Pad_D1.0mm
U3: ESP32-S3-MINI-1-N8; ESP32-S2-MINI-1; MPN ESP32-S3-MINI-1-N8; LCSC C2913206

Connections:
+3V3: C5.1, C6.1, R3.1, R4.1, R7.1, TP8.1, U3.3 (3V3); also elsewhere on the board
ACT_HEARTBEAT: U3.21 (IO17); also elsewhere on the board
ACT_REQ: U3.20 (IO16); also elsewhere on the board
ADC_CS: R7.2, U3.14 (IO10); also elsewhere on the board
BOOT: R4.2, SW2.1, TP7.1, U3.4 (IO0)
BOOT_SAFE_SPARE: U3.44 (IO46); also elsewhere on the board
BTN_L_CMD1: U3.8 (IO4); also elsewhere on the board
BTN_L_CMD2: U3.9 (IO5); also elsewhere on the board
BTN_M_CMD1: U3.10 (IO6); also elsewhere on the board
BTN_M_CMD2: U3.11 (IO7); also elsewhere on the board
BTN_R_CMD1: U3.12 (IO8); also elsewhere on the board
BTN_R_CMD2: U3.13 (IO9); also elsewhere on the board
CC_OUT1: U3.18 (IO14); also elsewhere on the board
CC_OUT2: U3.19 (IO15); also elsewhere on the board
CS_ADC2: U3.32 (IO36); also elsewhere on the board
CS_DRV8316: U3.34 (IO38); also elsewhere on the board
CS_IMU: U3.25 (IO21); also elsewhere on the board
CS_MA735: U3.33 (IO37); also elsewhere on the board
CS_PAW: U3.6 (IO2); also elsewhere on the board
DRV_FAULT_N: U3.37 (IO41); also elsewhere on the board
GND: C4.2, C5.2, C6.2, SW1.2, SW2.2, TP9.1, U3.1 (GND), U3.2 (GND), U3.42 (GND), U3.43 (GND), U3.46 (GND), U3.47 (GND), U3.48 (GND), U3.49 (GND), U3.50 (GND), U3.51 (GND), U3.52 (GND), U3.53 (GND), U3.54 (GND), U3.55 (GND), U3.56 (GND), U3.57 (GND), U3.58 (GND), U3.59 (GND), U3.60 (GND), U3.61 (GND), U3.62 (GND), U3.63 (GND), U3.64 (GND), U3.65 (GND); also elsewhere on the board
IMU_INT1: U3.36 (IO40); also elsewhere on the board
MCU_EN: C4.1, R3.2, SW1.1, TP6.1, U3.45 (EN); also elsewhere on the board
MCU_USB_DM: R5.1, U3.23 (USB_D-)
MCU_USB_DP: R6.1, U3.24 (USB_D+)
MOTOR_SPI_MISO: U3.31 (IO35); also elsewhere on the board
MOTOR_SPI_MOSI: U3.28 (IO33); also elsewhere on the board
MOTOR_SPI_SCLK: U3.29 (IO34); also elsewhere on the board
OPT_CTRL: U3.26 (IO26); also elsewhere on the board
PAW_MOTION_N: U3.35 (IO39); also elsewhere on the board
RGB_DATA: U3.41 (IO45); also elsewhere on the board
SENS_REQ: U3.22 (IO18); also elsewhere on the board
SPI_MISO: U3.17 (IO13); also elsewhere on the board
SPI_MOSI: U3.15 (IO11); also elsewhere on the board
SPI_SCLK: U3.16 (IO12); also elsewhere on the board
UART_RX: TP5.1, U3.40 (RXD0)
UART_TX: TP4.1, U3.39 (TXD0)
USB_DM: R5.2; also elsewhere on the board
USB_DP: R6.2; also elsewhere on the board
VBUS_PRESENT_N: U3.5 (IO1); also elsewhere on the board
WHEEL_PWM_A: U3.38 (IO42); also elsewhere on the board
WHEEL_PWM_B: U3.27 (IO47); also elsewhere on the board
WHEEL_PWM_C: U3.30 (IO48); also elsewhere on the board
WHEEL_RUN_REQ: U3.7 (IO3); also elsewhere on the board

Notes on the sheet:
02 / ESP32-S3 module, USB and recovery
DRAFT 0.4 - CIRCUIT DEVELOPMENT ONLY - NOT FOR FABRICATION
GPIO allocation: 38 assigned + GPIO46 boot-low spare. Exact module: ESP32-S3-MINI-1-N8 (no PSRAM). SPI2: ADC1 / optical / IMU / angle / driver config. SPI3: dedicated ADC2. See sheet 09 and gpio-allocation.json. MCPWM0: wheel 3-PWM; MCPWM1: six independent button commands. RMT: one-wire RGB. GPIO3 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

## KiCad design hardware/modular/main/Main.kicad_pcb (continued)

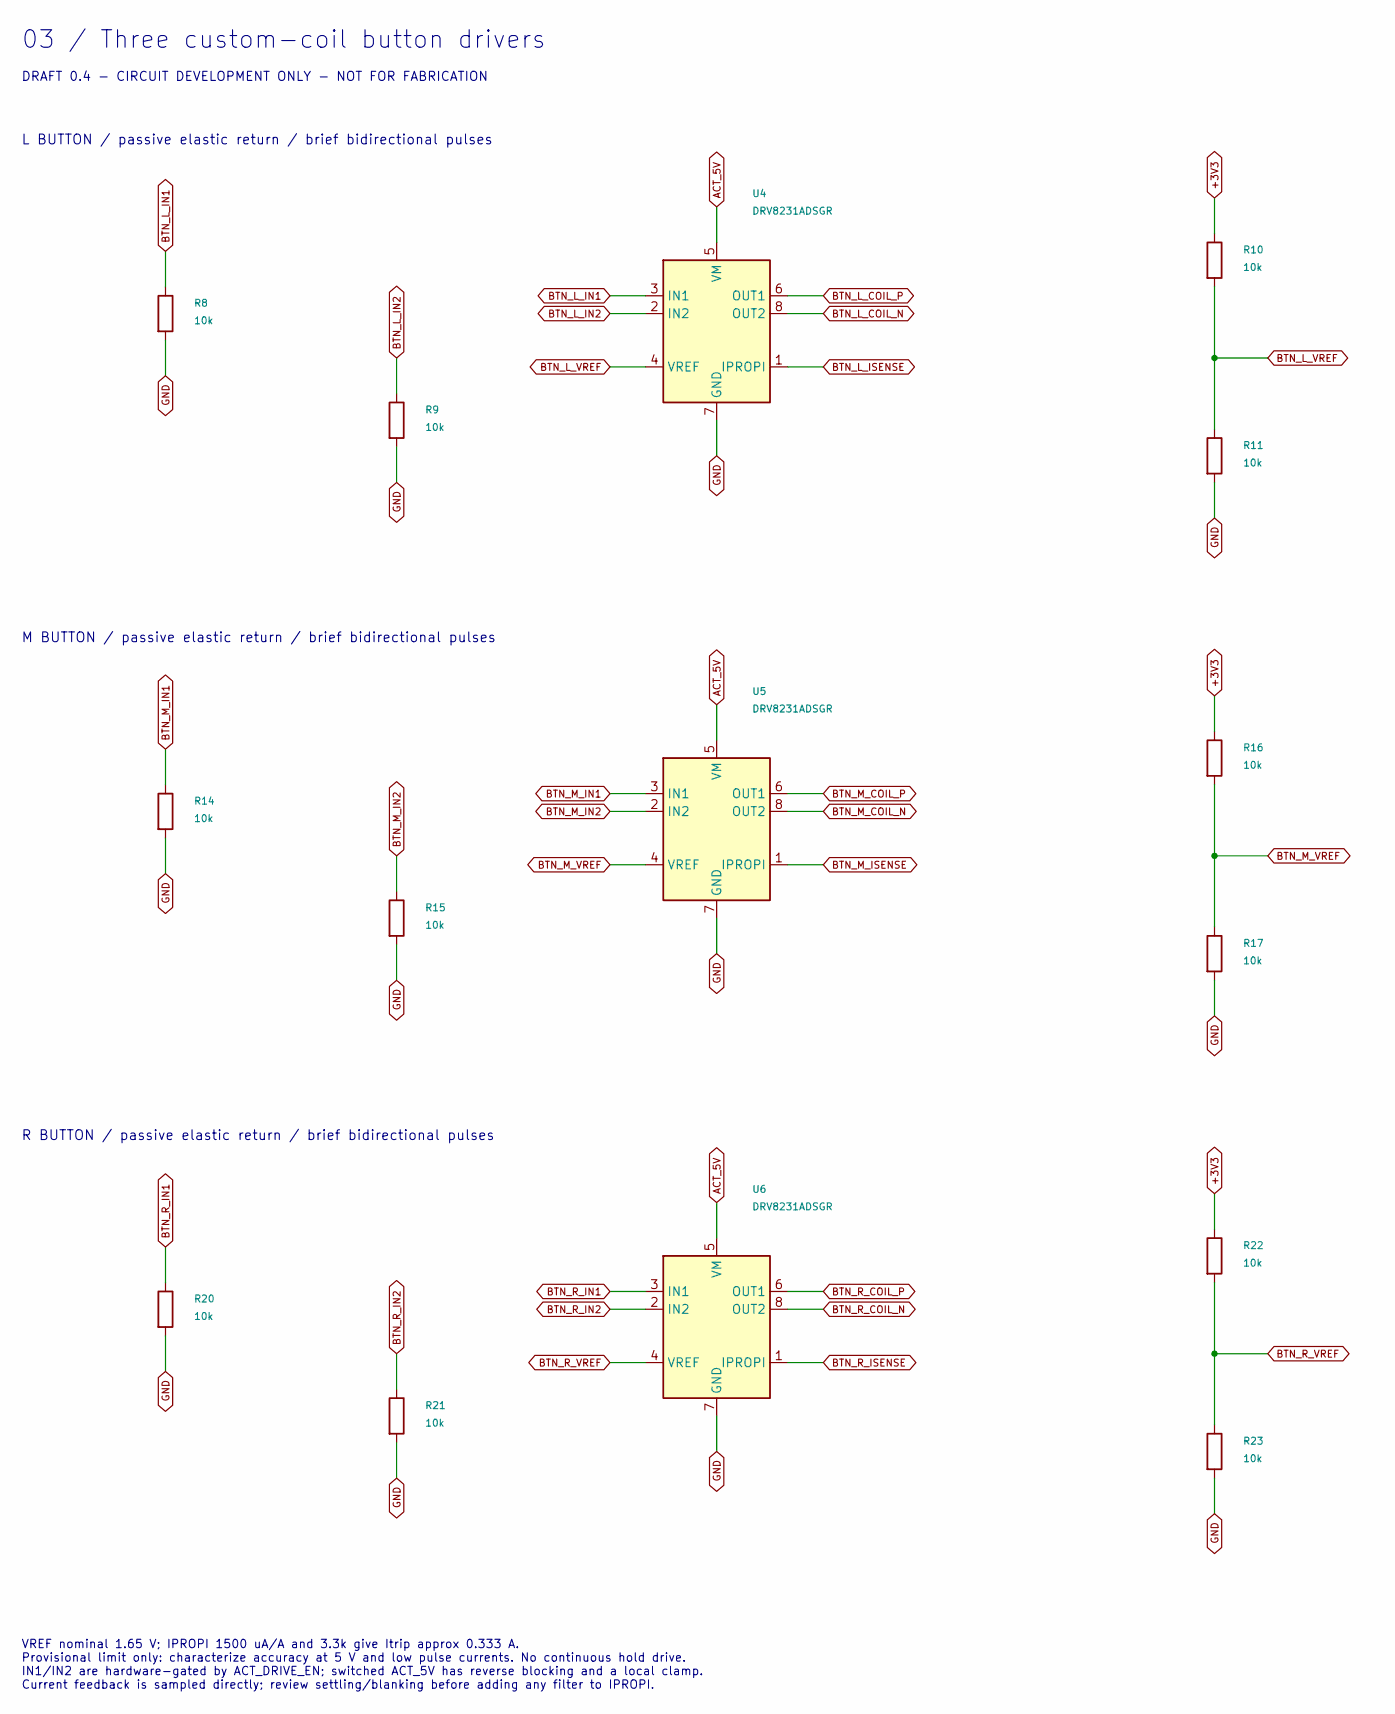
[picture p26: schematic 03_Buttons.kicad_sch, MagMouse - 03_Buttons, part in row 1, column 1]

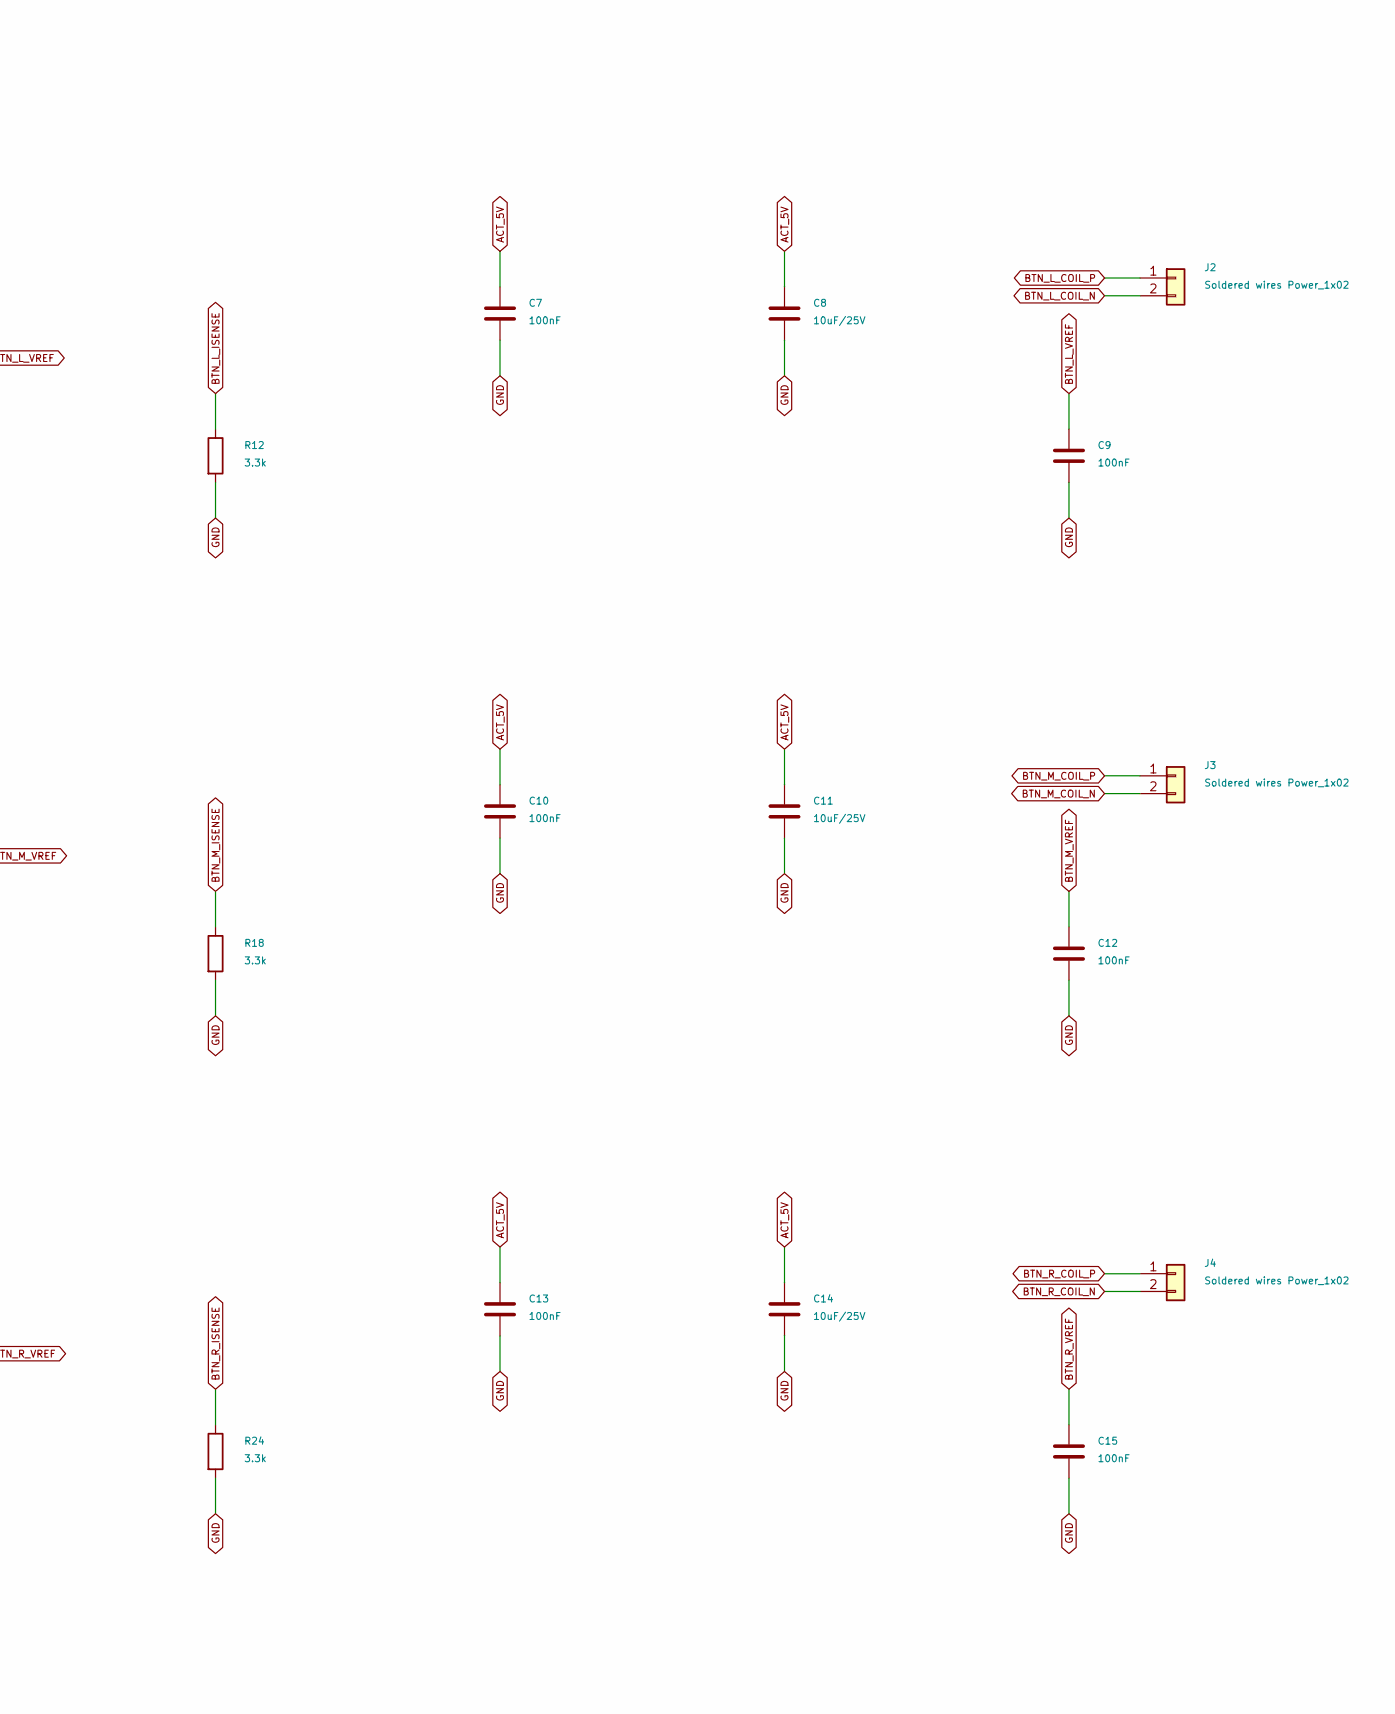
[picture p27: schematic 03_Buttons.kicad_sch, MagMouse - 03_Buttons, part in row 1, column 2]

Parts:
C7, C9, C10, C12, C13, C15: 100nF; C_0603_1608Metric; MPN CC0603KRX7R9BB104; LCSC C14663
C8, C11, C14: 10uF/25V; C_0805_2012Metric; MPN CL21A106KAYNNNE; LCSC C15850
J2, J3, J4: Soldered wires Power_1x02; Wire_Power_1x02_P2.54mm; JLCPCB Library Type Extended
R8, R9, R10, R11, R14, R15, R16, R17, R20, R21, R22, R23: 10k; R_0603_1608Metric; MPN 0603WAF1002T5E; LCSC C25804
R12, R18, R24: 3.3k; R_0603_1608Metric; MPN 0603WAF3301T5E; LCSC C22978
U4, U5, U6: DRV8231ADSGR; Texas_DSG0008A_WSON-8-1EP_2x2mm_P0.5mm_EP0.9x1.6mm; MPN DRV8231ADSGR; LCSC C5139865

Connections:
+3V3: R10.1, R16.1, R22.1; also elsewhere on the board
ACT_5V: C7.1, C8.1, C10.1, C11.1, C13.1, C14.1, U4.5 (VM), U5.5 (VM), U6.5 (VM); also elsewhere on the board
BTN_L_COIL_N: J2.2, U4.8 (OUT2)
BTN_L_COIL_P: J2.1, U4.6 (OUT1)
BTN_L_IN1: R8.1, U4.3 (IN1); also elsewhere on the board
BTN_L_IN2: R9.1, U4.2 (IN2); also elsewhere on the board
BTN_L_ISENSE: R12.1, U4.1 (IPROPI); also elsewhere on the board
BTN_L_VREF: C9.1, R10.2, R11.1, U4.4 (VREF)
BTN_M_COIL_N: J3.2, U5.8 (OUT2)
BTN_M_COIL_P: J3.1, U5.6 (OUT1)
BTN_M_IN1: R14.1, U5.3 (IN1); also elsewhere on the board
BTN_M_IN2: R15.1, U5.2 (IN2); also elsewhere on the board
BTN_M_ISENSE: R18.1, U5.1 (IPROPI); also elsewhere on the board
BTN_M_VREF: C12.1, R16.2, R17.1, U5.4 (VREF)
BTN_R_COIL_N: J4.2, U6.8 (OUT2)
BTN_R_COIL_P: J4.1, U6.6 (OUT1)
BTN_R_IN1: R20.1, U6.3 (IN1); also elsewhere on the board
BTN_R_IN2: R21.1, U6.2 (IN2); also elsewhere on the board
BTN_R_ISENSE: R24.1, U6.1 (IPROPI); also elsewhere on the board
BTN_R_VREF: C15.1, R22.2, R23.1, U6.4 (VREF)
GND: C7.2, C8.2, C9.2, C10.2, C11.2, C12.2, C13.2, C14.2, C15.2, R8.2, R9.2, R11.2, R12.2, R14.2, R15.2, R17.2, R18.2, R20.2, R21.2, R23.2, R24.2, U4.7 (GND), U4.9 (GND), U5.7 (GND), U5.9 (GND), U6.7 (GND), U6.9 (GND); also elsewhere on the board

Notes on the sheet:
03 / Three custom-coil button drivers
DRAFT 0.4 - CIRCUIT DEVELOPMENT ONLY - NOT FOR FABRICATION
L BUTTON / passive elastic return / brief bidirectional pulses
M BUTTON / passive elastic return / brief bidirectional pulses
R BUTTON / passive elastic return / brief bidirectional pulses
VREF nominal 1.65 V; IPROPI 1500 uA/A and 3.3k give Itrip approx 0.333 A. Provisional limit only: characterize accuracy at 5 V and low pulse currents. No continuous hold drive. IN1/IN2 are hardware-gated by ACT_DRIVE_EN; switched ACT_5V has reverse blocking and a local clamp. Current feedback is sa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

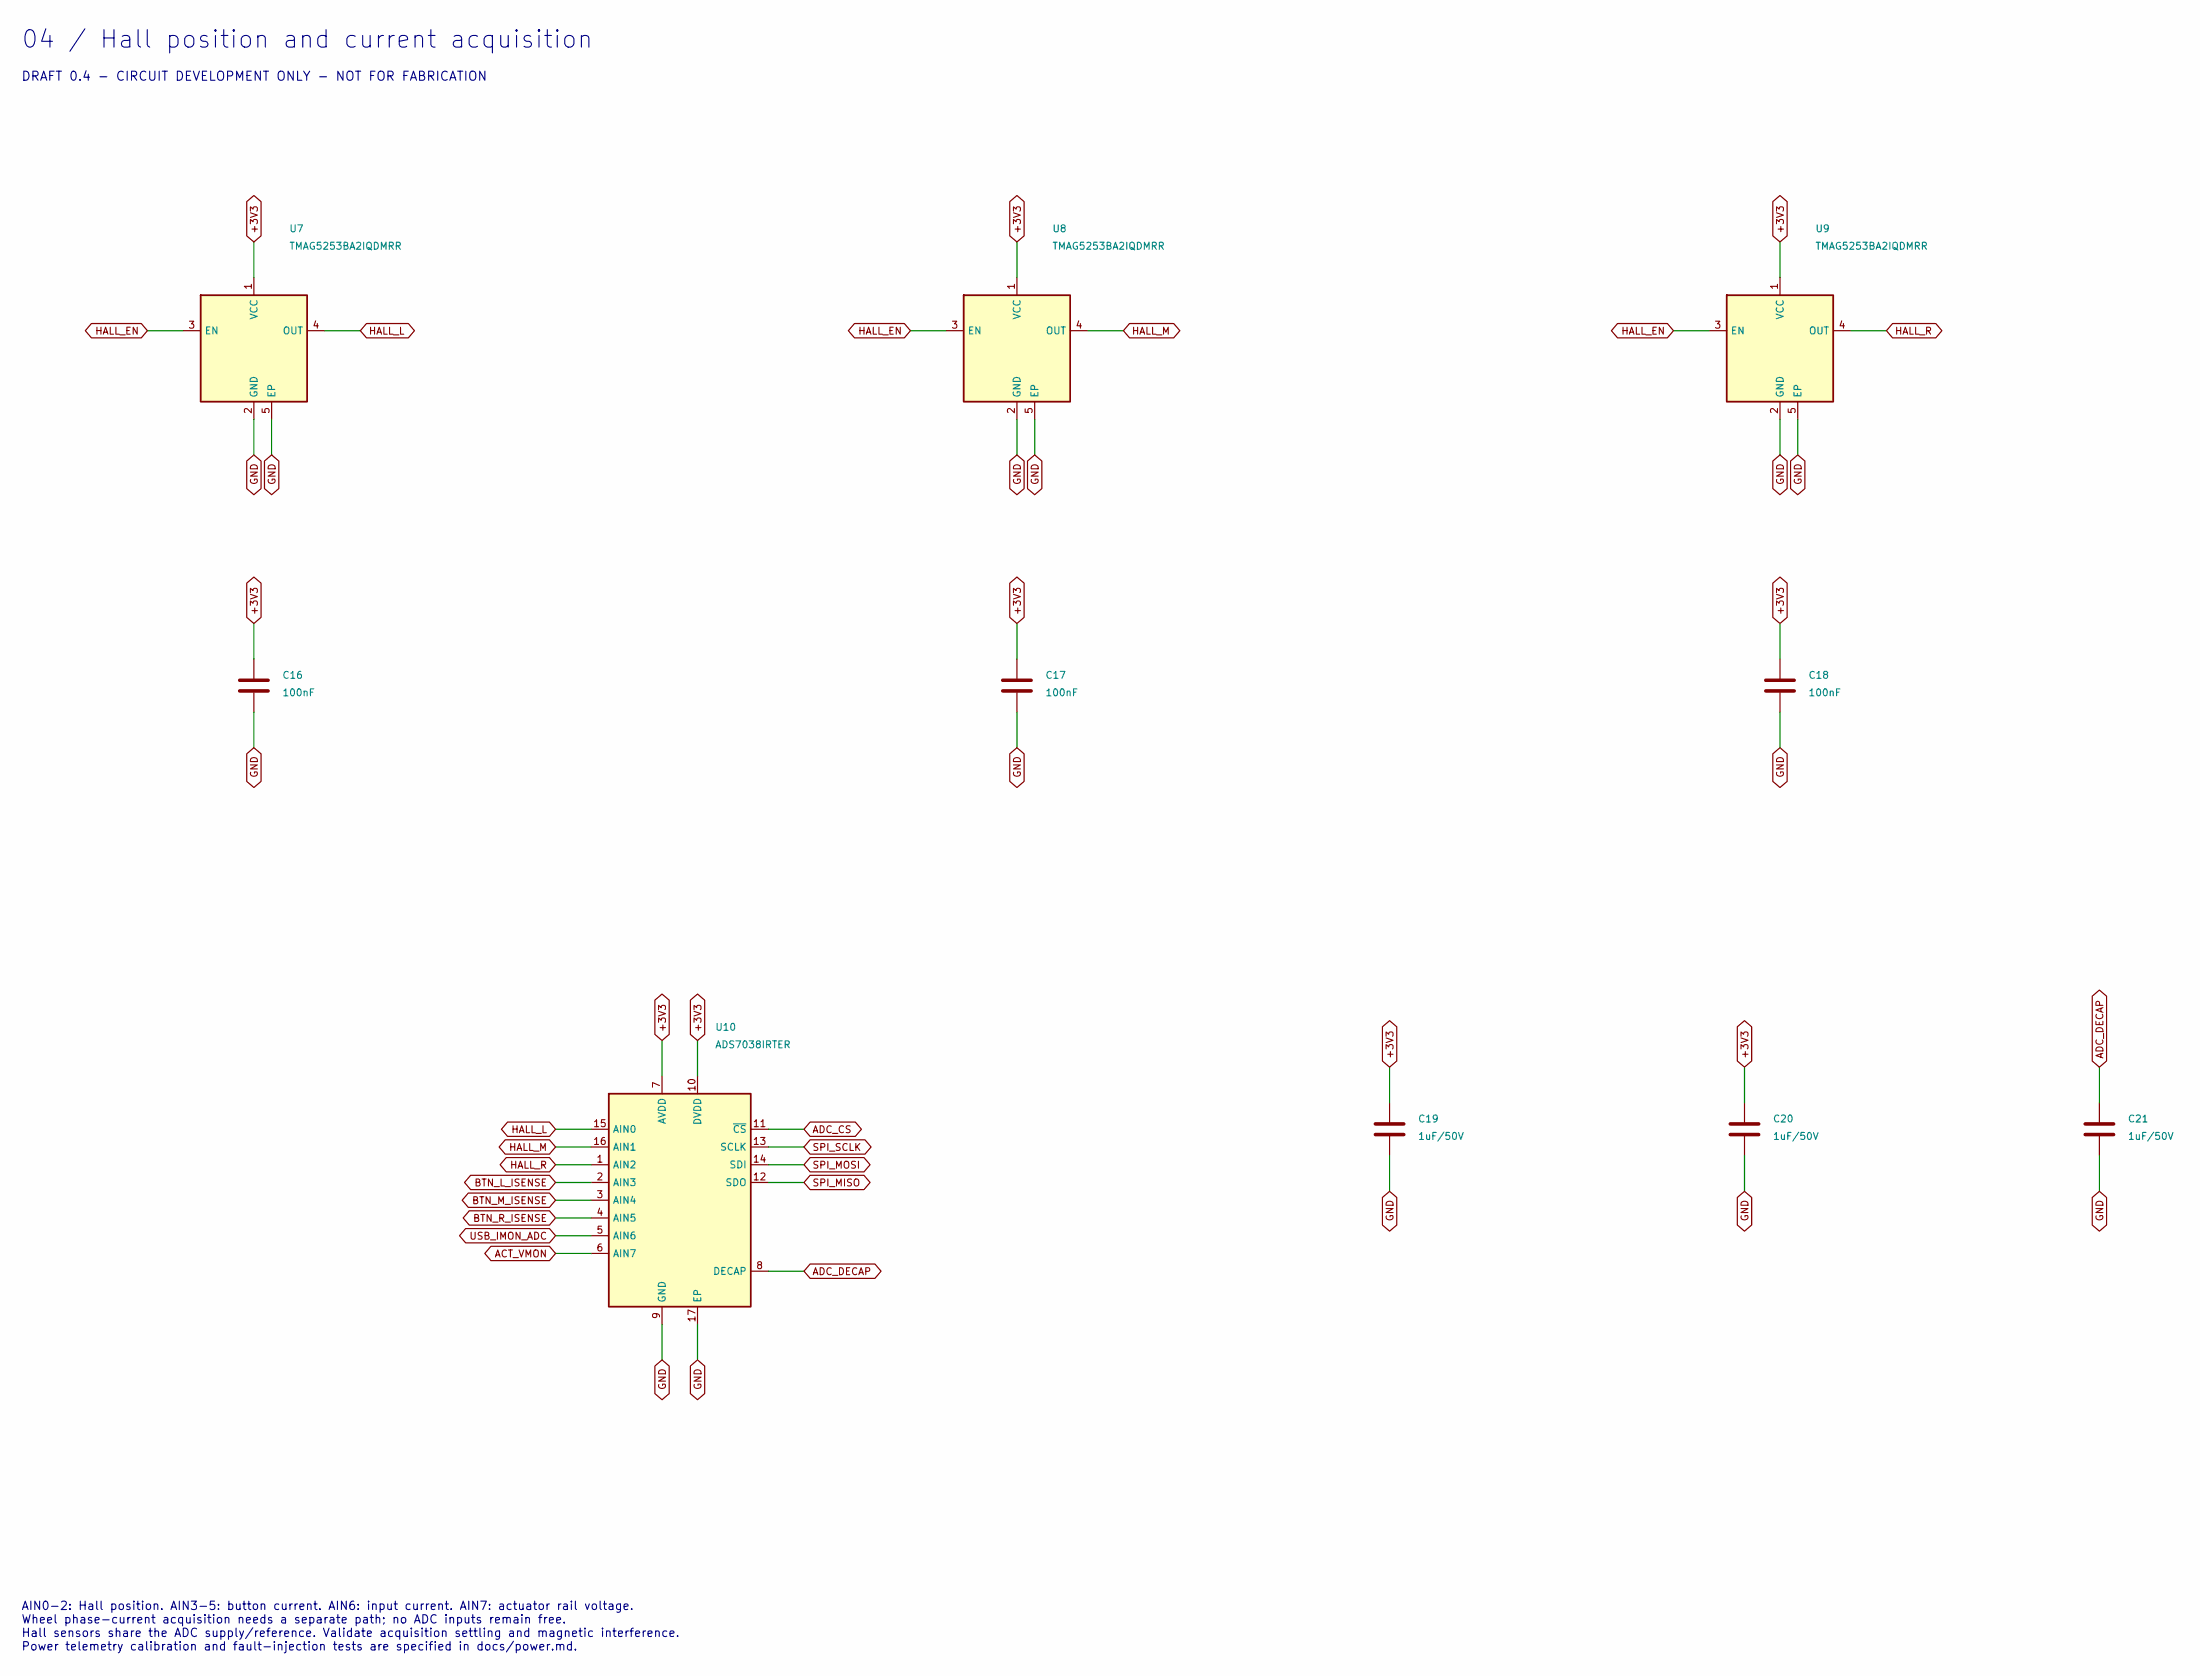
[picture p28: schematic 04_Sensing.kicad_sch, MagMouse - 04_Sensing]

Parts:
C16, C17, C18: 100nF; C_0603_1608Metric; MPN CC0603KRX7R9BB104; LCSC C14663
C19, C20, C21: 1uF/50V; C_0603_1608Metric; MPN CL10A105KB8NNNC; LCSC C15849
U7, U8, U9: TMAG5253BA2IQDMRR; Texas_X2SON-4-1EP_1.1x1.4mm_P0.5mm_EP0.8x0.6mm; MPN TMAG5253BA2IQDMRR; LCSC C35414983
U10: ADS7038IRTER; WQFN-16-1EP_3x3mm_P0.5mm_EP1.68x1.68mm; MPN ADS7038IRTER; LCSC C2871580

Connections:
+3V3: C16.1, C17.1, C18.1, C19.1, C20.1, U7.1 (VCC), U8.1 (VCC), U9.1 (VCC), U10.7 (AVDD), U10.10 (DVDD); also elsewhere on the board
ACT_VMON: U10.6 (AIN7); also elsewhere on the board
ADC_CS: U10.11 (~CS); also elsewhere on the board
ADC_DECAP: C21.1, U10.8 (DECAP)
BTN_L_ISENSE: U10.2 (AIN3); also elsewhere on the board
BTN_M_ISENSE: U10.3 (AIN4); also elsewhere on the board
BTN_R_ISENSE: U10.4 (AIN5); also elsewhere on the board
GND: C16.2, C17.2, C18.2, C19.2, C20.2, C21.2, U7.2 (GND), U7.5 (EP), U8.2 (GND), U8.5 (EP), U9.2 (GND), U9.5 (EP), U10.9 (GND), U10.17 (EP); also elsewhere on the board
HALL_EN: U7.3 (EN), U8.3 (EN), U9.3 (EN); also elsewhere on the board
HALL_L: U7.4 (OUT), U10.15 (AIN0)
HALL_M: U8.4 (OUT), U10.16 (AIN1)
HALL_R: U9.4 (OUT), U10.1 (AIN2)
SPI_MISO: U10.12 (SDO); also elsewhere on the board
SPI_MOSI: U10.14 (SDI); also elsewhere on the board
SPI_SCLK: U10.13 (SCLK); also elsewhere on the board
USB_IMON_ADC: U10.5 (AIN6); also elsewhere on the board

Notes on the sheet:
04 / Hall position and current acquisition
DRAFT 0.4 - CIRCUIT DEVELOPMENT ONLY - NOT FOR FABRICATION
AIN0-2: Hall position. AIN3-5: button current. AIN6: input current. AIN7: actuator rail voltage. Wheel phase-current acquisition needs a separate path; no ADC inputs remain free. Hall sensors share the ADC supply/reference. Validate acquisition settling and magnetic interference. Power telemetry ca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

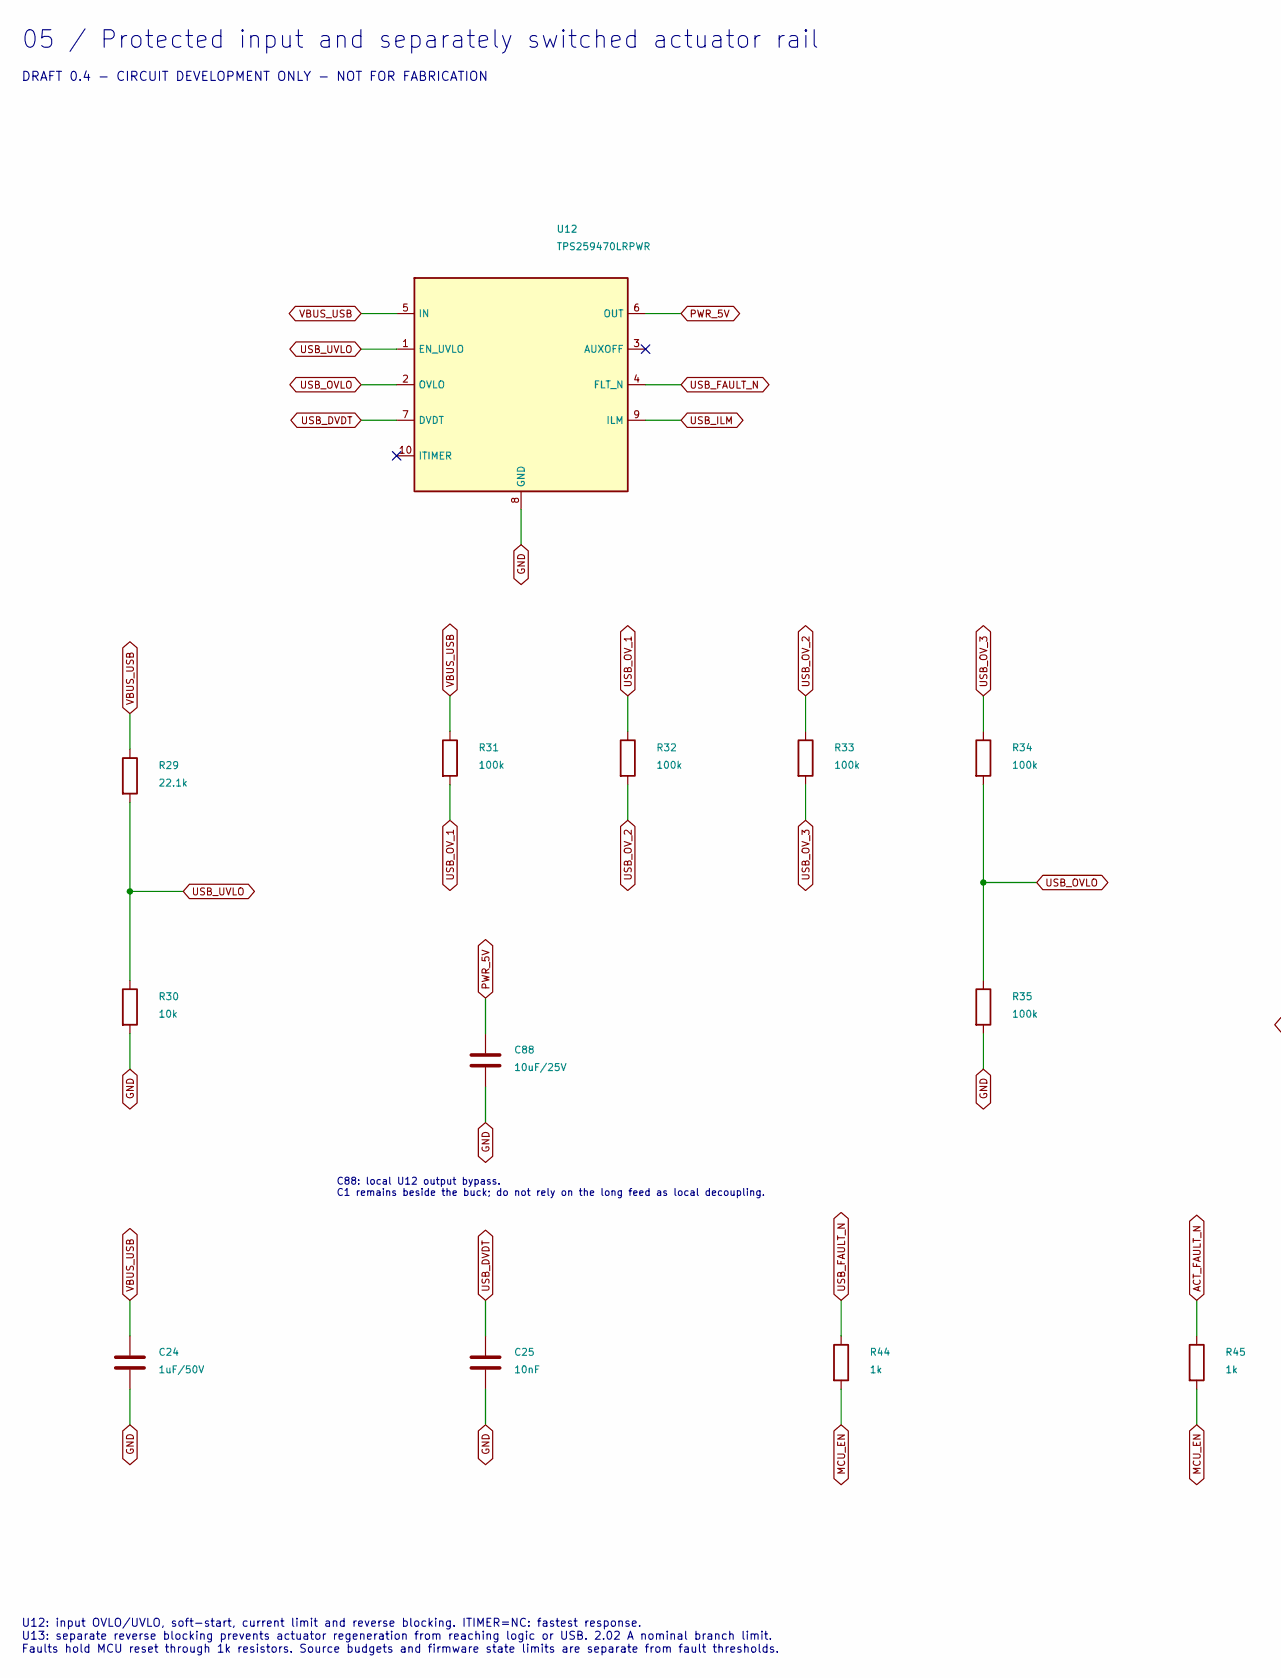
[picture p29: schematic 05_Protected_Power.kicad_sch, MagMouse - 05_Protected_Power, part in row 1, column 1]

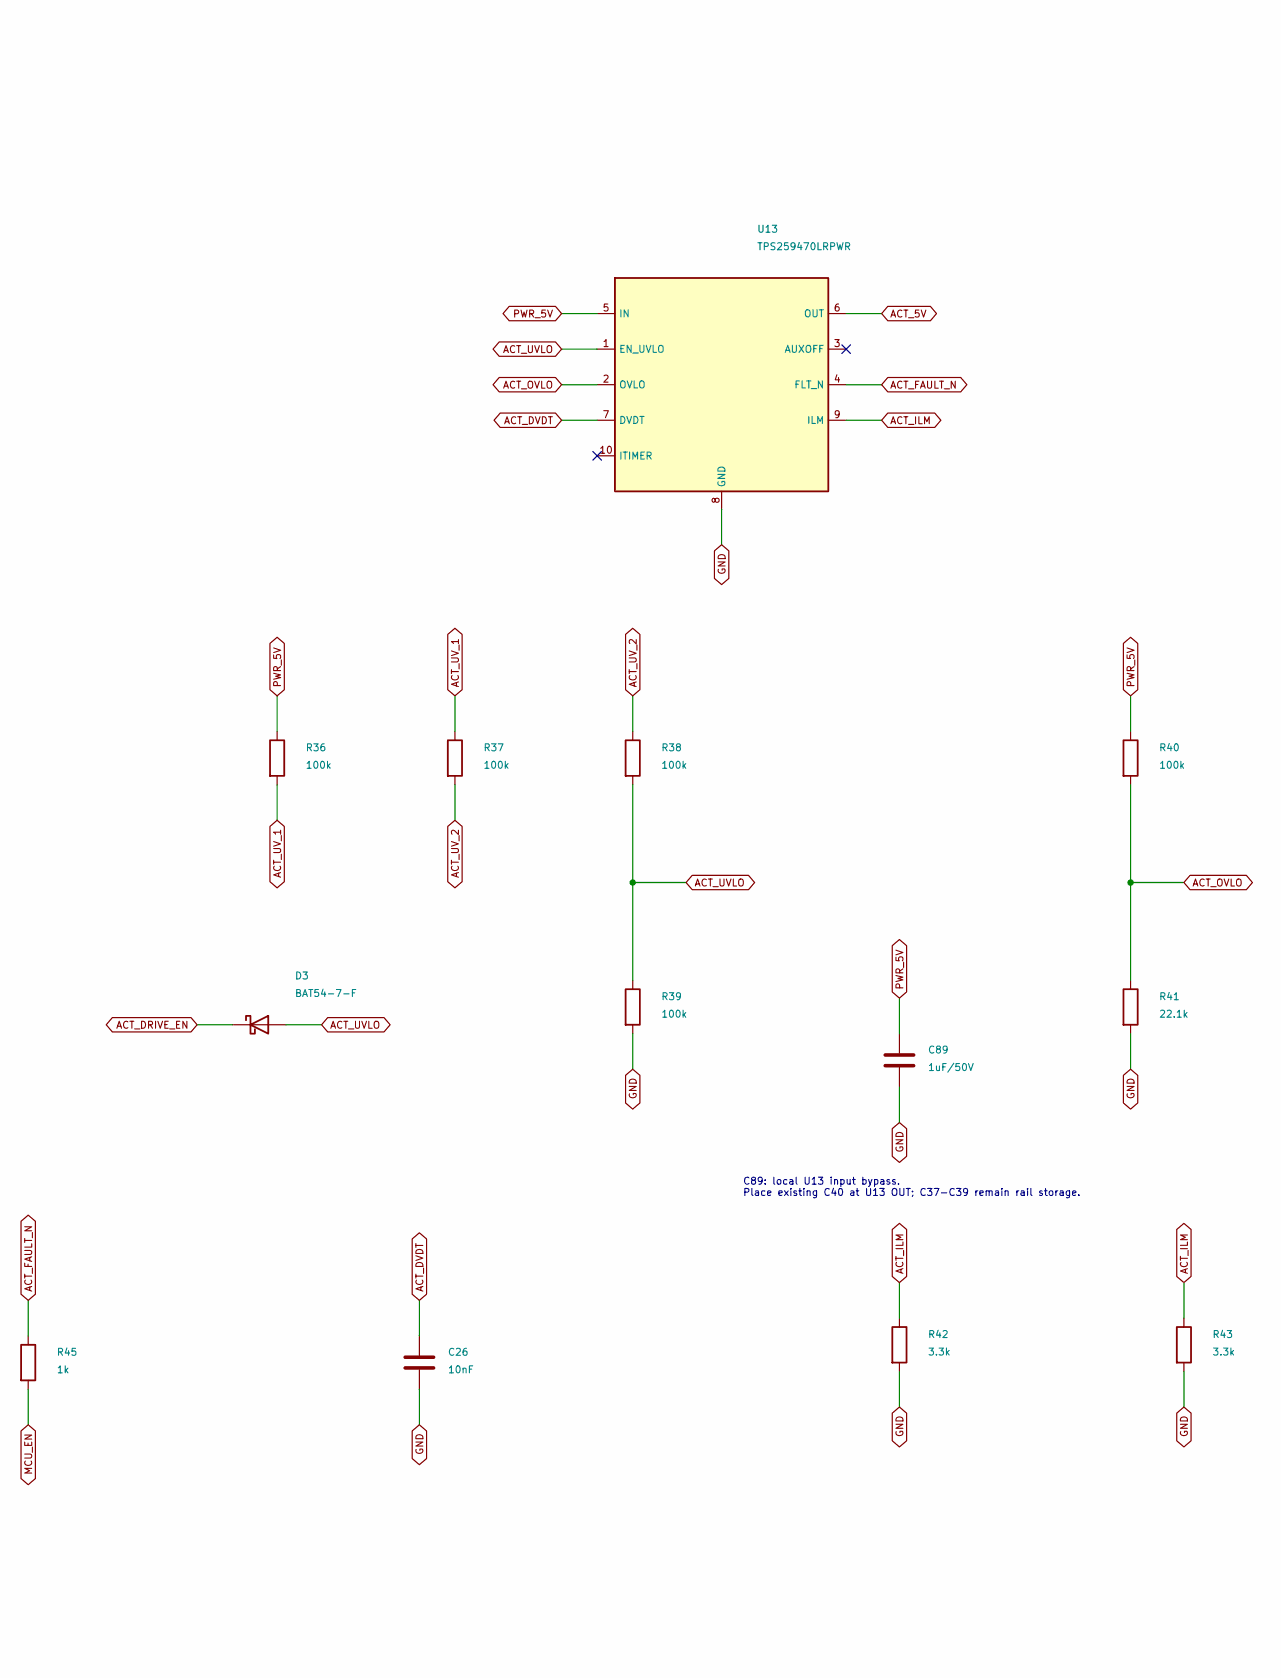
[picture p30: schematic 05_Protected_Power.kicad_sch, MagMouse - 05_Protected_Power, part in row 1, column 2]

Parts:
C24, C89: 1uF/50V; C_0603_1608Metric; MPN CL10A105KB8NNNC; LCSC C15849
C25, C26: 10nF; C_0603_1608Metric; MPN 0603B103K500NT; LCSC C57112
C88: 10uF/25V; C_0805_2012Metric; MPN CL21A106KAYNNNE; LCSC C15850
D3: BAT54-7-F; SOT-23; MPN BAT54-7-F; LCSC C106920
R29, R41: 22.1k; R_0603_1608Metric; MPN 0603WAF2212T5E; LCSC C25961
R30: 10k; R_0603_1608Metric; MPN 0603WAF1002T5E; LCSC C25804
R31, R32, R33, R34, R35, R36, R37, R38, R39, R40: 100k; R_0603_1608Metric; MPN 0603WAF1003T5E; LCSC C25803
R42, R43: 3.3k; R_0603_1608Metric; MPN 0603WAF3301T5E; LCSC C22978
R44, R45: 1k; R_0603_1608Metric; MPN 0603WAF1001T5E; LCSC C21190
U12, U13: TPS259470LRPWR; Texas_RPW0010A; MPN TPS259470LRPWR; LCSC C3662793

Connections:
ACT_5V: U13.6 (OUT); also elsewhere on the board
ACT_DRIVE_EN: D3.3 (K); also elsewhere on the board
ACT_DVDT: C26.1, U13.7 (DVDT)
ACT_FAULT_N: R45.1, U13.4 (FLT_N)
ACT_ILM: R42.1, R43.1, U13.9 (ILM)
ACT_OVLO: R40.2, R41.1, U13.2 (OVLO)
ACT_UVLO: D3.1 (A), R38.2, R39.1, U13.1 (EN_UVLO)
ACT_UV_1: R36.2, R37.1
ACT_UV_2: R37.2, R38.1
GND: C24.2, C25.2, C26.2, C88.2, C89.2, R30.2, R35.2, R39.2, R41.2, R42.2, R43.2, U12.8 (GND), U13.8 (GND); also elsewhere on the board
MCU_EN: R44.2, R45.2; also elsewhere on the board
PWR_5V: C88.1, C89.1, R36.1, R40.1, U12.6 (OUT), U13.5 (IN); also elsewhere on the board
USB_DVDT: C25.1, U12.7 (DVDT)
USB_FAULT_N: R44.1, U12.4 (FLT_N)
USB_ILM: U12.9 (ILM); also elsewhere on the board
USB_OVLO: R34.2, R35.1, U12.2 (OVLO)
USB_OV_1: R31.2, R32.1
USB_OV_2: R32.2, R33.1
USB_OV_3: R33.2, R34.1
USB_UVLO: R29.2, R30.1, U12.1 (EN_UVLO)
VBUS_USB: C24.1, R29.1, R31.1, U12.5 (IN); also elsewhere on the board

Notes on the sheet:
05 / Protected input and separately switched actuator rail
DRAFT 0.4 - CIRCUIT DEVELOPMENT ONLY - NOT FOR FABRICATION
U12: input OVLO/UVLO, soft-start, current limit and reverse blocking. ITIMER=NC: fastest response. U13: separate reverse blocking prevents actuator regeneration from reaching logic or USB. 2.02 A nominal branch limit. Faults hold MCU reset through 1k resistors. Source budgets and firmware state lim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
C88: local U12 output bypass. C1 remains beside the buck; do not rely on the long feed as local decoupling.
C89: local U13 input bypass. Place existing C40 at U13 OUT; C37-C39 remain rail storage.



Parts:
C27: 1uF/50V; C_0603_1608Metric; MPN CL10A105KB8NNNC; LCSC C15849
C28, C29, C30, C31: 100nF; C_0603_1608Metric; MPN CC0603KRX7R9BB104; LCSC C14663
R46, R47, R48, R49, R50, R51, R52, R53, R54, R55, R70: 10k; R_0603_1608Metric; MPN 0603WAF1002T5E; LCSC C25804
U15: SN74LVC1G123DCUR; VSSOP-8_2.3x2mm_P0.5mm; MPN SN74LVC1G123DCUR; LCSC C352969
U16, U17, U18: SN74LVC08APWR; TSSOP-14_4.4x5mm_P0.65mm; MPN SN74LVC08APWR; LCSC C465737

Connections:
+3V3: C28.1, C29.1, C30.1, C31.1, R46.1, U15.8 (VCC), U16.14 (VCC), U17.14 (VCC), U18.14 (VCC); also elsewhere on the board
ACT_DRIVE_EN: R49.1, U16.11 (4Y), U17.2 (1B), U17.5 (2B), U17.10 (3B), U17.13 (4B), U18.2 (1B), U18.5 (2B); also elsewhere on the board
ACT_HEARTBEAT: R47.1, U15.2 (B); also elsewhere on the board
ACT_PERMIT: U15.5 (Q), U16.12 (4A)
ACT_REQ: R48.1, U16.2 (1B); also elsewhere on the board
ARM_SOURCE: U16.3 (1Y), U16.4 (2A)
ARM_VALID: U15.3 (CLR_N), U16.6 (2Y), U16.13 (4B)
BTN_L_CMD1: R50.1, U17.1 (1A); also elsewhere on the board
BTN_L_CMD2: R51.1, U17.4 (2A); also elsewhere on the board
BTN_L_IN1: U17.3 (1Y); also elsewhere on the board
BTN_L_IN2: U17.6 (2Y); also elsewhere on the board
BTN_M_CMD1: R52.1, U17.9 (3A); also elsewhere on the board
BTN_M_CMD2: R53.1, U17.12 (4A); also elsewhere on the board
BTN_M_IN1: U17.8 (3Y); also elsewhere on the board
BTN_M_IN2: U17.11 (4Y); also elsewhere on the board
BTN_R_CMD1: R54.1, U18.1 (1A); also elsewhere on the board
BTN_R_CMD2: R55.1, U18.4 (2A); also elsewhere on the board
BTN_R_IN1: U18.3 (1Y); also elsewhere on the board
BTN_R_IN2: U18.6 (2Y); also elsewhere on the board
CC_OUT2_INV: U16.10 (3B); also elsewhere on the board
GND: C28.2, C29.2, C30.2, C31.2, R47.2, R48.2, R49.2, R50.2, R51.2, R52.2, R53.2, R54.2, R55.2, R70.2, U15.1 (A), U15.4 (GND), U16.7 (GND), U17.7 (GND), U18.7 (GND), U18.12 (4A), U18.13 (4B); also elsewhere on the board
HALL_EN: U16.5 (2B), U18.8 (3Y); also elsewhere on the board
MCU_EN: U18.10 (3B); also elsewhere on the board
SENS_REQ: R70.1, U18.9 (3A); also elsewhere on the board
SOURCE_3A: U16.8 (3Y); also elsewhere on the board
SOURCE_OK: U16.1 (1A), U16.9 (3A); also elsewhere on the board
WD_CEXT: C27.2, U15.6 (CEXT)
WD_RCEXT: C27.1, R46.2, U15.7 (RCEXT)

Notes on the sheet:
06 / Source-qualified arm, heartbeat timeout and drive gates
DRAFT 0.4 - CIRCUIT DEVELOPMENT ONLY - NOT FOR FABRICATION
~10 ms retriggerable heartbeat timeout. Arm requires 1.5/3 A source + ACT_REQ + HALL_EN. Permit gates every button IN and actuator power. Held-high heartbeat expires. Firmware: 1 ms refresh; keep all CMD low during rail ramp. See docs/power.md.

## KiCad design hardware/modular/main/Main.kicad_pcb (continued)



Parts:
C32, C33, C34, C35, C36: 100nF; C_0603_1608Metric; MPN CC0603KRX7R9BB104; LCSC C14663
D4: BAT54-7-F; SOT-23; MPN BAT54-7-F; LCSC C106920
Q1, Q2, Q3: 2N7002; SOT-23; MPN 2N7002; LCSC C8545
R56, R57, R60: 3.3k; R_0603_1608Metric; MPN 0603WAF3301T5E; LCSC C22978
R58: 33R; R_0603_1608Metric; MPN 0603WAF330JT5E; LCSC C23140
R59: 4.7k; R_0603_1608Metric; MPN 0603WAF4701T5E; LCSC C23162
R61: 10k; R_0603_1608Metric; MPN 0603WAF1002T5E; LCSC C25804
R62, R63, R66, R67, R71: 100k; R_0603_1608Metric; MPN 0603WAF1003T5E; LCSC C25803
R64: 1k; R_0603_1608Metric; MPN 0603WAF1001T5E; LCSC C21190
R65, R68: 22.1k; R_0603_1608Metric; MPN 0603WAF2212T5E; LCSC C25961
U14: SN74LVC2G04DCKR; SOT-363_SC-70-6; MPN SN74LVC2G04DCKR; LCSC C105251
U19: TLV9001IDBVR; SOT-23-5; MPN TLV9001IDBVR; LCSC C398363

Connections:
+3V3: C32.1, C34.1, D4.3 (K), R71.1, U14.5 (VCC), U19.5 (V+); also elsewhere on the board
ACT_5V: R67.1; also elsewhere on the board
ACT_VMON: C36.1, D4.1 (A), R67.2, R68.1; also elsewhere on the board
CC_OUT1: U14.1 (1A); also elsewhere on the board
CC_OUT2: U14.3 (2A); also elsewhere on the board
CC_OUT2_INV: U14.4 (2Y); also elsewhere on the board
GND: C32.2, C33.2, C34.2, C35.2, C36.2, Q1.2 (S), Q2.2 (S), Q3.2 (S), R58.2, R62.2, R63.2, R66.2, R68.2, U14.2 (GND), U19.2 (V-); also elsewhere on the board
ILM_BASE_1: R56.2, R57.1
ILM_BASE_2: R57.2, R58.1
ILM_HIGH_D: Q2.3 (D), R60.2, R61.2
ILM_MED_D: Q1.3 (D), R59.2
SOURCE_3A: Q2.1 (G), R63.1; also elsewhere on the board
SOURCE_OK: Q1.1 (G), R62.1, U14.6 (1Y); also elsewhere on the board
USB_ILM: R56.1, R59.1, R60.1, R61.1, U19.3 (IN+); also elsewhere on the board
USB_IMON_ADC: C33.1, R64.2; also elsewhere on the board
USB_IMON_BUF: R64.1, U19.1 (OUT), U19.4 (IN-)
VBUS_GATE: C35.1, Q3.1 (G), R65.2, R66.1
VBUS_PRESENT_N: Q3.3 (D), R71.2; also elsewhere on the board
VBUS_USB: R65.1; also elsewhere on the board

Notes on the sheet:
07 / Source-selected current limit and voltage/current telemetry
DRAFT 0.4 - CIRCUIT DEVELOPMENT ONLY - NOT FOR FABRICATION
CC OUT1/OUT2: HH detached, HL default, LH 1.5 A, LL 3 A. Missing detector supply leaves higher budgets OFF. ILIM = 3334 / R: 0.503 A / 1.212 A / 2.555 A nominal. This is fault protection; firmware enforces USB-state load budgets.
ADS7038 AIN6 = buffered input-current monitor; AIN7 = ACT rail voltage. GPIO1 = isolated, active-low VBUS presence (Q3). Voltage scale = 22.1 / 122.1. Current scale = 182 uA/A x effective ILM resistance; changes with CC state. Use raw CC status with each sample; discard mode-transition samples and 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

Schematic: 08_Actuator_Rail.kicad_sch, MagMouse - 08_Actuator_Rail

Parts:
C37, C38, C39, C40: 10uF/25V; C_0805_2012Metric; MPN CL21A106KAYNNNE; LCSC C15850
D1: SMBJ12A; D_SMB; MPN SMBJ12A; LCSC C151251
D2: SMBJ6.0A; D_SMB; MPN SMBJ6.0A; LCSC C83270
R69: 1k; R_0603_1608Metric; MPN 0603WAF1001T5E; LCSC C21190
TP1, TP10: VBUS_USB; TestPoint_Pad_D1.0mm
TP2, TP11: PWR_5V; TestPoint_Pad_D1.0mm
TP3, TP12: ACT_5V; TestPoint_Pad_D1.0mm
TP13: ACT_DRIVE_EN; TestPoint_Pad_D1.0mm
TP14: USB_ILM; TestPoint_Pad_D1.0mm
TP15: GND; TestPoint_Pad_D1.0mm

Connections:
ACT_5V: C37.1, C38.1, C39.1, C40.1, D2.1 (K), R69.1, TP3.1, TP12.1; also elsewhere on the board
ACT_DRIVE_EN: TP13.1; also elsewhere on the board
GND: C37.2, C38.2, C39.2, C40.2, D1.2 (A), D2.2 (A), R69.2, TP15.1; also elsewhere on the board
PWR_5V: TP2.1, TP11.1; also elsewhere on the board
USB_ILM: TP14.1; also elsewhere on the board
VBUS_USB: D1.1 (K), TP1.1, TP10.1; also elsewhere on the board

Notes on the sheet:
08 / Local actuator storage, clamp, discharge and review points
DRAFT 0.4 - CIRCUIT DEVELOPMENT ONLY - NOT FOR FABRICATION
ACT capacitance: 40 uF here + 30 uF at button drivers (nominal; DC bias/tolerance reduce storage). D2 SMBJ6.0A: 6 V standoff; 6.67-7.37 V breakdown; 10.3 V pulse clamp at datasheet test current. D1 SMBJ12A protects U12 input; U12 OVLO protects the downstream rails. U13 blocks actuator reverse power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

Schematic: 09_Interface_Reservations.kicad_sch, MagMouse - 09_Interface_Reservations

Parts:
R72, R73, R74, R75, R76, R77, R78, R79, R80: 10k; R_0603_1608Metric; MPN 0603WAF1002T5E; LCSC C25804
TP16: CS_PAW; TestPoint_Pad_D1.0mm
TP17: WHEEL_RUN_REQ; TestPoint_Pad_D1.0mm
TP18: CS_IMU; TestPoint_Pad_D1.0mm
TP19: OPT_CTRL; TestPoint_Pad_D1.0mm
TP20: MOTOR_SPI_MOSI; TestPoint_Pad_D1.0mm
TP21: MOTOR_SPI_SCLK; TestPoint_Pad_D1.0mm
TP22: MOTOR_SPI_MISO; TestPoint_Pad_D1.0mm
TP23: CS_ADC2; TestPoint_Pad_D1.0mm
TP24: CS_MA735; TestPoint_Pad_D1.0mm
TP25: CS_DRV8316; TestPoint_Pad_D1.0mm
TP26: PAW_MOTION_N; TestPoint_Pad_D1.0mm
TP27: IMU_INT1; TestPoint_Pad_D1.0mm
TP28: DRV_FAULT_N; TestPoint_Pad_D1.0mm
TP29: WHEEL_PWM_A; TestPoint_Pad_D1.0mm
TP30: RGB_DATA; TestPoint_Pad_D1.0mm
TP31: BOOT_SAFE_SPARE; TestPoint_Pad_D1.0mm
TP32: WHEEL_PWM_B; TestPoint_Pad_D1.0mm
TP33: WHEEL_PWM_C; TestPoint_Pad_D1.0mm

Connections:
+3V3: R72.1, R73.1, R74.1, R75.1, R76.1; also elsewhere on the board
BOOT_SAFE_SPARE: R80.1, TP31.1; also elsewhere on the board
CS_ADC2: R74.2, TP23.1; also elsewhere on the board
CS_DRV8316: R76.2, TP25.1; also elsewhere on the board
CS_IMU: R73.2, TP18.1; also elsewhere on the board
CS_MA735: R75.2, TP24.1; also elsewhere on the board
CS_PAW: R72.2, TP16.1; also elsewhere on the board
DRV_FAULT_N: TP28.1; also elsewhere on the board
GND: R77.2, R78.2, R79.2, R80.2; also elsewhere on the board
IMU_INT1: TP27.1; also elsewhere on the board
MOTOR_SPI_MISO: TP22.1; also elsewhere on the board
MOTOR_SPI_MOSI: TP20.1; also elsewhere on the board
MOTOR_SPI_SCLK: TP21.1; also elsewhere on the board
OPT_CTRL: R79.1, TP19.1; also elsewhere on the board
PAW_MOTION_N: TP26.1; also elsewhere on the board
RGB_DATA: R78.1, TP30.1; also elsewhere on the board
WHEEL_PWM_A: TP29.1; also elsewhere on the board
WHEEL_PWM_B: TP32.1; also elsewhere on the board
WHEEL_PWM_C: TP33.1; also elsewhere on the board
WHEEL_RUN_REQ: R77.1, TP17.1; also elsewhere on the board

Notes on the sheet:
09 / Allocated interfaces and boot defaults
DRAFT 0.4 - CIRCUIT DEVELOPMENT ONLY - NOT FOR FABRICATION
MCU connections and test pads retain the approved GPIO map. Sheets 10-13 implement wheel drive, ADC2, encoder, SPI isolation and autonomous braking. Optical, IMU and RGB remain open.
Only the N8 module is covered. Wheel voltage-domain isolation and hardware-qualified RUN are on sheets 10-12. Optical/IMU/RGB circuits must still respect their voltage and power-off requirements. GPIO46 stays LOW for download recovery. GPIO45 RGB interface must not pull the strap high during reset.

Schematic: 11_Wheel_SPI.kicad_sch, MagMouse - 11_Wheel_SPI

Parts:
C53, C55: 100nF; C_0603_1608Metric; MPN CC0603KRX7R9BB104; LCSC C14663
R99: 10k; R_0603_1608Metric; MPN 0603WAF1002T5E; LCSC C25804
R101: 100k; R_0603_1608Metric; MPN 0603WAF1003T5E; LCSC C25803
U25, U29: SN74LVC125APWR; TSSOP-14_4.4x5mm_P0.65mm; MPN SN74LVC125APWR; LCSC C7813

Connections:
+3V3: C53.1, U25.14 (VCC); also elsewhere on the board
ADC2_MISO_LOCAL: U25.9 (3A); also elsewhere on the board
CS_ADC2: U25.10 (3OE_N); also elsewhere on the board
CS_DRV8316: U25.1 (1OE_N); also elsewhere on the board
CS_MA735: U25.4 (2OE_N), U29.9 (3A); also elsewhere on the board
DRV_FAULT_LOCAL_N: U25.12 (4A); also elsewhere on the board
DRV_FAULT_N: U25.11 (4Y); also elsewhere on the board
DRV_MISO_LOCAL: U25.2 (1A); also elsewhere on the board
ENC_3V3: C55.1, R99.1, U29.13 (4OE_N), U29.14 (VCC); also elsewhere on the board
ENC_CS_LOCAL: R99.2, U29.8 (3Y); also elsewhere on the board
ENC_MISO_LOCAL: R101.1, U25.5 (2A); also elsewhere on the board
ENC_MOSI_LOCAL: U29.6 (2Y); also elsewhere on the board
ENC_SCLK_LOCAL: U29.3 (1Y); also elsewhere on the board
GND: C53.2, C55.2, R101.2, U25.7 (GND), U25.13 (4OE_N), U29.1 (1OE_N), U29.4 (2OE_N), U29.7 (GND), U29.10 (3OE_N), U29.12 (4A); also elsewhere on the board
MOTOR_SPI_MISO: U25.8 (3Y); also elsewhere on the board
SPI_MISO: U25.3 (1Y), U25.6 (2Y); also elsewhere on the board
SPI_MOSI: U29.5 (2A); also elsewhere on the board
SPI_SCLK: U29.2 (1A); also elsewhere on the board

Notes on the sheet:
11_Wheel_SPI - Main owned components only See 18_Wheel_Harness for connector/bias additions; see INTERFACE_REVIEW.md for limits.

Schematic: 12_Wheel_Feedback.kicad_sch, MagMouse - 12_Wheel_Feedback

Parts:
C63: 1uF/50V; C_0603_1608Metric; MPN CL10A105KB8NNNC; LCSC C15849
C64: 100nF; C_0603_1608Metric; MPN CC0603KRX7R9BB104; LCSC C14663
J6: Soldered wires Signal_2x04; Wire_Signal_2x04_P2.54mm
R110: 100k; R_0603_1608Metric; MPN 0603WAF1003T5E; LCSC C25803
R125: 0R; R_0603_1608Metric; MPN 0603WAF0000T5E; LCSC C21189
U28: TPS22919DCKR; SOT-363_SC-70-6; MPN TPS22919DCKR; LCSC C2149796

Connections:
+3V3: C63.1, U28.1 (IN); also elsewhere on the board
ENC_3V3: C64.1, J6.1, R125.2, U28.6 (OUT); also elsewhere on the board
ENC_CS_LOCAL: J6.6; also elsewhere on the board
ENC_MISO_LOCAL: J6.8; also elsewhere on the board
ENC_MOSI_LOCAL: J6.5; also elsewhere on the board
ENC_QOD: R125.1, U28.5 (QOD)
ENC_SCLK_LOCAL: J6.3; also elsewhere on the board
GND: C63.2, C64.2, J6.2, J6.4, J6.7, R110.2, U28.2 (GND); also elsewhere on the board
HALL_EN: R110.1, U28.3 (ON); also elsewhere on the board

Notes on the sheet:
12_Wheel_Feedback - Main owned components only See 18_Wheel_Harness for connector/bias additions; see INTERFACE_REVIEW.md for limits.

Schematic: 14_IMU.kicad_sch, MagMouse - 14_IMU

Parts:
C70: 100nF; C_0603_1608Metric; MPN CC0603KRX7R9BB104; LCSC C14663
C71: 2.2uF/10V; C_0603_1608Metric; MPN CL10B225KP8NNNC; LCSC C100082
C72: 10nF; C_0603_1608Metric; MPN CL10B103KB8NNNC; LCSC C1589
R126, R127: 10k; R_0603_1608Metric; MPN 0603WAF1002T5E; LCSC C25804
U32: ICM-42688-P; LGA-14_3x2.5mm_P0.5mm_LayoutBorder3x4y; MPN ICM-42688-P; LCSC C1850418

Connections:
+3V3: C70.1, C71.1, C72.1, R127.1, U32.5 (VDDIO), U32.8 (VDD); also elsewhere on the board
CS_IMU: U32.12 (AP_CS); also elsewhere on the board
GND: C70.2, C71.2, C72.2, R126.2, U32.6 (GND), U32.7 (RESV_GND); also elsewhere on the board
IMU_INT1: R127.2, U32.4 (INT1); also elsewhere on the board
IMU_PIN9: R126.1, U32.9 (INT2_FSYNC_CLKIN)
SPI_MISO: U32.1 (AP_SDO); also elsewhere on the board
SPI_MOSI: U32.14 (AP_SDI); also elsewhere on the board
SPI_SCLK: U32.13 (AP_SCLK); also elsewhere on the board

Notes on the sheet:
14 / Inertial sensing on shared SPI2
DRAFT 0.6 - CIRCUIT DEVELOPMENT ONLY - NOT FOR FABRICATION
C70/C71: place at VDD pin 8. C72: place at VDDIO pin 5. Both supplies remain on system +3V3. SPI2 mode 0, initial target 10MHz; CS setup/hold and MISO release guard >=100ns. R73 on sheet 09 holds CS high at boot. Internal clock; INT1 active-low open-drain with R127 pull-up. Pin 7 must be grounded. 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
Pin 9 has a 10k pulldown to avoid shorting a configurable output; select FSYNC input and leave FSYNC disabled. Wait >=1ms after valid power before register access; read WHO_AM_I=0x47 and configure interface/interrupts. Keep IMU in sleep for USB suspend. Prove shared-bus operation and vibration reje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

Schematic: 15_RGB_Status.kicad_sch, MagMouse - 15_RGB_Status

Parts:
C73, C74: 10uF/25V; C_0805_2012Metric; MPN CL21A106KAYNNNE; LCSC C15850
C75, C76: 100nF; C_0603_1608Metric; MPN CC0603KRX7R9BB104; LCSC C14663
D5: SK6805-EC15; OPSCO_SK6805_EC15; MPN SK6805-EC15; LCSC C2890035
R128: 330R; R_0603_1608Metric; MPN 0603WAF3300T5E; LCSC C23138
R129: 100k; R_0603_1608Metric; MPN 0603WAF1003T5E; LCSC C25803
R130: 10k; R_0603_1608Metric; MPN 0603WAF1002T5E; LCSC C25804
TP38: RGB_5V; TestPoint_Pad_D1.0mm
TP39: RGB_DIN; TestPoint_Pad_D1.0mm
U33: TPS7A2450DBVR; SOT-23-5; MPN TPS7A2450DBVR; LCSC C2864436
U34: SN74LV1T34DBVR; SOT-23-5; MPN SN74LV1T34DBVR; LCSC C100024

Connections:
GND: C73.2, C74.2, C75.2, C76.2, D5.4 (GND), R129.2, R130.2, U33.2 (GND), U34.3 (GND); also elsewhere on the board
HALL_EN: U33.3 (EN); also elsewhere on the board
PWR_5V: C73.1, U33.1 (IN); also elsewhere on the board
RGB_5V: C74.1, C75.1, C76.1, D5.2 (VDD), R130.1, TP38.1, U33.5 (OUT), U34.5 (VCC)
RGB_BUFFER_OUT: R128.1, U34.4 (Y)
RGB_DATA: U34.2 (A); also elsewhere on the board
RGB_DIN: D5.1 (DIN), R128.2, R129.1, TP39.1

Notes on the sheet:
15 / Single-data-pin status LED with switched protected supply
DRAFT 0.6 - CIRCUIT DEVELOPMENT ONLY - NOT FOR FABRICATION
U33 caps the LED rail near 5V; in dropout RGB_5V follows PWR_5V minus dropout. This is not a boost supply. HALL_EN low disables RGB with Hall/encoder sleep; R130 discharges local storage. ACT_5V is never used. U34 shifts 3.3V data to the LED rail. R78 on sheet 09 preserves GPIO45 boot-low; no LED-r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
Firmware: hold data low during rail transitions; send black before suspend, then lower HALL_EN. Target 800kbps GRB/MSB-first; A1 timing 0=0.30/0.95us, 1=0.90/0.35us, reset low >=300us. Qualify startup/dropout, discharge, bus current and RGB_DIN timing on hardware. LED supply must stay 3.7..5.5V.

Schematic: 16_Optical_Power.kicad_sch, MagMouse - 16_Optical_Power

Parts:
C77, C78: 10uF/25V; C_0805_2012Metric; MPN CL21A106KAYNNNE; LCSC C15850
C79: 1nF/50V; C_0603_1608Metric; MPN CL10B102KB8NNNC; LCSC C1588
C81, C82: 2.2uF/10V; C_0603_1608Metric; MPN CL10B225KP8NNNC; LCSC C100082
C83, C85: 100nF; C_0603_1608Metric; MPN CC0603KRX7R9BB104; LCSC C14663
C84: 4.7uF/10V; C_0603_1608Metric; MPN CL10A475KP8NNNC; LCSC C1705
R132: 39R; R_0603_1608Metric; MPN 0603WAF390JT5E; LCSC C23154
TP40: OPT_3V3; TestPoint_Pad_D1.0mm
TP41: OPT_1V9; TestPoint_Pad_D1.0mm
TP42: OPT_VDDPIX; TestPoint_Pad_D1.0mm
U36: TLV75519PDBVR; SOT-23-5; MPN TLV75519PDBVR; LCSC C2865381
U38: TPS22918DBVR; SOT-23-6; MPN TPS22918DBVR; LCSC C131941

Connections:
+3V3: C77.1, C78.1, U38.1 (VIN); also elsewhere on the board
GND: C77.2, C78.2, C79.2, C81.2, C82.2, C83.2, C84.2, C85.2, U36.2 (GND), U38.2 (GND); also elsewhere on the board
HALL_EN: U38.3 (ON); also elsewhere on the board
OPT_1V9: C82.1, C83.1, R132.1, TP41.1, U36.5 (OUT); also elsewhere on the board
OPT_3V3: C81.1, TP40.1, U36.1 (IN), U36.3 (EN), U38.6 (VOUT); also elsewhere on the board
OPT_LED_P: R132.2; also elsewhere on the board
OPT_RAMP_CT: C79.1, U38.4 (CT)
OPT_VDDPIX: C84.1, C85.1, TP42.1; also elsewhere on the board

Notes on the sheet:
16_Optical_Power - Main owned components only See 18_Wheel_Harness for connector/bias additions; see INTERFACE_REVIEW.md for limits.

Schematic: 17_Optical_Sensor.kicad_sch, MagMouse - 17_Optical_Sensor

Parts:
C80, C86, C87: 100nF; C_0603_1608Metric; MPN CC0603KRX7R9BB104; LCSC C14663
R131, R135: 10k; R_0603_1608Metric; MPN 0603WAF1002T5E; LCSC C25804
R133, R134, R136: 100k; R_0603_1608Metric; MPN 0603WAF1003T5E; LCSC C25803
TP43: OPT_RESET_N; TestPoint_Pad_D1.0mm
U35: PMW3360DM-T2QU; PixArt_PMW3360DM_T2QU; MPN PMW3360DM-T2QU; LCSC C20612443
U37: SN74LVC125APWR; TSSOP-14_4.4x5mm_P0.65mm; MPN SN74LVC125APWR; LCSC C7813
U39: SN74LVC1G125DBVR; SOT-23-5; MPN SN74LVC1G125DBVR; LCSC C23654

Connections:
CS_PAW: U37.1 (1OE_N), U37.4 (2OE_N), U37.10 (3OE_N), U39.2 (A); also elsewhere on the board
GND: C80.2, C86.2, C87.2, R134.2, U35.8 (GND), U37.7 (GND), U37.13 (4OE_N), U39.1 (OE_N), U39.3 (GND); also elsewhere on the board
OPT_1V9: U35.4 (VDD_1V9); also elsewhere on the board
OPT_3V3: C80.1, C86.1, C87.1, R131.1, R133.1, R135.1, R136.1, U35.5 (VDDIO), U37.14 (VCC), U39.5 (VCC); also elsewhere on the board
OPT_CS_N: R131.2, U35.13 (NCS), U39.4 (Y)
OPT_CTRL: U37.12 (4A); also elsewhere on the board
OPT_LED_P: U35.15 (LED_P); also elsewhere on the board
OPT_MISO: R135.2, U35.12 (MISO), U37.9 (3A)
OPT_MOSI: R134.1, U35.11 (MOSI), U37.3 (1Y)
OPT_RESET_N: TP43.1, U35.7 (NRESET), U37.11 (4Y)
OPT_SCLK: R133.2, U35.10 (SCLK), U37.6 (2Y)
OPT_VDDPIX: U35.3 (VDDPIX_OUT); also elsewhere on the board
PAW_MOTION_N: R136.2, U35.9 (MOTION); also elsewhere on the board
SPI_MISO: U37.8 (3Y); also elsewhere on the board
SPI_MOSI: U37.2 (1A); also elsewhere on the board
SPI_SCLK: U37.5 (2A); also elsewhere on the board

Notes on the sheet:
17 / PMW3360 with selected-device SPI isolation and buffered reset
DRAFT 0.7 - CIRCUIT DEVELOPMENT ONLY - NOT FOR FABRICATION
SPI2 mode 3, <=2MHz. Set SCLK high before selecting; CS setup/read hold/release guard >=1us. U37 disconnects sensor clock, MOSI and MISO while CS_PAW is high; reset channel is always enabled. R72 holds CS high and R79 holds OPT_CTRL low at boot. Keep all CS high during reset and rail transitions. S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
OPT_CTRL low asserts reset despite the internal pull-up (600uA max). U39 isolates CS when unpowered. After valid rails: reset, wait >=50ms, clear motion registers, load authorized SROM and verify identity. Suspend: send Shutdown, deselect, assert reset, clear SENS_REQ. Resume requires full initiali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

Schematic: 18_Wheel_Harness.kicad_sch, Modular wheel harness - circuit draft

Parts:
J8: Soldered wires Signal_2x15; Wire_Signal_2x15_P2.54mm
J10: Soldered wires Power_1x02; Wire_Power_1x02_P2.54mm
R141, R142, R143: 33k; R_0603_1608Metric; MPN 0603WAF3302T5E; LCSC C4216

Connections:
+3V3: J8.30; also elsewhere on the board
ACT_5V: J10.1; also elsewhere on the board
ACT_DRIVE_EN: J8.24; also elsewhere on the board
ADC2_MISO_LOCAL: J8.16, R143.1; also elsewhere on the board
CS_ADC2: J8.14; also elsewhere on the board
CS_DRV8316: J8.6; also elsewhere on the board
DRV_FAULT_LOCAL_N: J8.28, R141.1; also elsewhere on the board
DRV_MISO_LOCAL: J8.8, R142.1; also elsewhere on the board
GND: J8.1, J8.3, J8.5, J8.7, J8.9, J8.11, J8.13, J8.15, J8.17, J8.19, J8.21, J8.23, J8.25, J8.27, J8.29, J10.2, R141.2, R142.2, R143.2; also elsewhere on the board
MOTOR_SPI_MOSI: J8.12; also elsewhere on the board
MOTOR_SPI_SCLK: J8.10; also elsewhere on the board
SPI_MOSI: J8.4; also elsewhere on the board
SPI_SCLK: J8.2; also elsewhere on the board
WHEEL_PWM_A: J8.18; also elsewhere on the board
WHEEL_PWM_B: J8.20; also elsewhere on the board
WHEEL_PWM_C: J8.22; also elsewhere on the board
WHEEL_RUN_REQ: J8.26; also elsewhere on the board

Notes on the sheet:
MAIN J8 pin N to WHEEL J9 pin (31-N); MAIN odd / WHEEL even contacts GND. Same-side-contact FFC; component sides up, headers facing each other; no twist. POWER J10/J11: 1 ACT_5V, 2 GND. Disconnect survival outside prototype scope.
Unplugged wheel fault return defaults LOW through R141. MISO inputs have local idle bias; select signals retain main-side pullups. Encoder stays on main J6 directly to J7; it does not cross this harness. No power is carried across breakaway tabs. Do not hot plug.



Board: 4 copper layers, 80.0 x 125.0 mm, 246 parts (37 on the bottom side), 130 nets.

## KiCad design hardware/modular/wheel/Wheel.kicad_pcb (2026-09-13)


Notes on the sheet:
MagMouse modular Wheel - independent schematic draft NOT FOR FABRICATION - copper migration and harness validation incomplete

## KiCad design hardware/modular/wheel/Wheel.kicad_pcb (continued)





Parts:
C41, C42, C43, C49, C51: 100nF; C_0603_1608Metric; MPN CC0603KRX7R9BB104; LCSC C14663
C44, C45: 10uF/25V; C_0805_2012Metric; MPN CL21A106KAYNNNE; LCSC C15850
C46, C48: 1uF/50V; C_0603_1608Metric; MPN CL10A105KB8NNNC; LCSC C15849
C47: 47nF/50V; C_0603_1608Metric; MPN CL10B473KB8NNNC; LCSC C1622
C50: 22uF/25V; C_0805_2012Metric; MPN CL21A226MAQNNNE; LCSC C45783
J5: GB1806 phase wires; MotorWire_3x1mm_P2.54mm
Q4: 2N7002; SOT-23; MPN 2N7002; LCSC C8545
R81: 22R; R_0603_1608Metric; MPN 0603WAF220JT5E; LCSC C23345
R82, R84: 10k; R_0603_1608Metric; MPN 0603WAF1002T5E; LCSC C25804
R83, R90, R91, R92: 100k; R_0603_1608Metric; MPN 0603WAF1003T5E; LCSC C25803
U21: DRV8316RRGFR; Texas_RGF0040E; MPN DRV8316RRGFR; LCSC C5218861
U22: SN74LVC08APWR; TSSOP-14_4.4x5mm_P0.65mm; MPN SN74LVC08APWR; LCSC C465737

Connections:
+3V3: C51.1, U22.14 (VCC); also elsewhere on the board
ACT_5V: C41.1, C42.1, C43.1, C44.1, C45.1, C46.2, U21.9 (VM_1), U21.10 (VM_2), U21.11 (VM_3); also elsewhere on the board
ACT_DRIVE_EN: R84.1, U21.23 (nSLEEP), U22.1 (1A); also elsewhere on the board
DRV_AVDD: C48.1, C49.1, R82.1, U21.25 (AVDD), U21.37 (VREF); also elsewhere on the board
DRV_CS_LOCAL: U21.36 (nSCS); also elsewhere on the board
DRV_FAULT_LOCAL_N: U21.22 (nFAULT); also elsewhere on the board
DRV_INHA: R90.1, U21.27 (INHA), U22.6 (2Y)
DRV_INHB: R91.1, U21.29 (INHB), U22.8 (3Y)
DRV_INHC: R92.1, U21.31 (INHC), U22.11 (4Y)
DRV_MISO_LOCAL: U21.33 (SDO); also elsewhere on the board
DRV_MOSI_LOCAL: U21.34 (SDI); also elsewhere on the board
DRV_SCLK_LOCAL: U21.35 (SCLK); also elsewhere on the board
GND: C41.2, C42.2, C43.2, C44.2, C45.2, C48.2, C49.2, C50.2, C51.2, Q4.2 (S), R83.2, R84.2, R90.2, R91.2, R92.2, U21.2 (AGND_1), U21.4 (GND_BK), U21.12 (PGND_1), U21.15 (PGND_2), U21.18 (PGND_3), U21.26 (AGND_2), U21.41 (EP), U22.7 (GND); also elsewhere on the board
WHEEL_BUCK_OUT: C50.1, R81.2, U21.3 (FB_BK)
WHEEL_BUCK_SW: R81.1, U21.5 (SW_BK)
WHEEL_CP: C46.1, U21.8 (CP)
WHEEL_CPH: C47.1, U21.7 (CPH)
WHEEL_CPL: C47.2, U21.6 (CPL)
WHEEL_DRVOFF: Q4.3 (D), R82.2, U21.21 (DRVOFF)
WHEEL_PHASE_A: J5.1, U21.13 (OUTA_1), U21.14 (OUTA_2)
WHEEL_PHASE_B: J5.2, U21.16 (OUTB_1), U21.17 (OUTB_2)
WHEEL_PHASE_C: J5.3, U21.19 (OUTC_1), U21.20 (OUTC_2)
WHEEL_PWM_A: U22.4 (2A); also elsewhere on the board
WHEEL_PWM_B: U22.9 (3A); also elsewhere on the board
WHEEL_PWM_C: U22.12 (4A); also elsewhere on the board
WHEEL_RUN_EN: Q4.1 (G), R83.1, U21.28 (INLA), U21.30 (INLB), U21.32 (INLC), U22.3 (1Y), U22.5 (2B), U22.10 (3B), U22.13 (4B)
WHEEL_RUN_REQ: U22.2 (1B); also elsewhere on the board
WHEEL_SOA: U21.40 (SOA); also elsewhere on the board
WHEEL_SOB: U21.39 (SOB); also elsewhere on the board
WHEEL_SOC: U21.38 (SOC); also elsewhere on the board

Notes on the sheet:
10 / Wheel power stage and hardware shutdown
DRAFT 0.5 - CIRCUIT DEVELOPMENT ONLY - NOT FOR FABRICATION
3-PWM requires PWM_MODE = 10b; read back before RUN. Reset default is 6-PWM. DRVOFF high = all outputs Hi-Z. Low PWM alone is not shutdown. ACT_DRIVE_EN wakes the driver; RUN stays low during SPI configuration.
GB1806 is external; winding, phase sequence and current limits need measurement. Configure BUCK_DIS = 1; the 22R + 22uF termination remains fitted. AVDD supplies ADC2 and forward SPI buffers; no connection to system +3V3.



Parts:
C52, C54: 100nF; C_0603_1608Metric; MPN CC0603KRX7R9BB104; LCSC C14663
R86, R98: 10k; R_0603_1608Metric; MPN 0603WAF1002T5E; LCSC C25804
R87, R88: 4.7k; R_0603_1608Metric; MPN 0603WAF4701T5E; LCSC C23162
R89, R94, R95, R96, R97, R100: 100k; R_0603_1608Metric; MPN 0603WAF1003T5E; LCSC C25803
U24, U26: SN74LVC125APWR; TSSOP-14_4.4x5mm_P0.65mm; MPN SN74LVC125APWR; LCSC C7813

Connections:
ADC2_CS_LOCAL: R98.2, U26.8 (3Y); also elsewhere on the board
ADC2_MISO_LOCAL: R100.1; also elsewhere on the board
ADC2_MOSI_LOCAL: U26.6 (2Y); also elsewhere on the board
ADC2_SCLK_LOCAL: U26.3 (1Y); also elsewhere on the board
CS_ADC2: U26.9 (3A); also elsewhere on the board
CS_DRV8316: U24.9 (3A); also elsewhere on the board
DRV_AVDD: C52.1, C54.1, R86.1, R87.1, R88.1, R98.1, U24.13 (4OE_N), U24.14 (VCC), U26.13 (4OE_N), U26.14 (VCC); also elsewhere on the board
DRV_CS_LOCAL: R86.2, U24.8 (3Y); also elsewhere on the board
DRV_FAULT_LOCAL_N: R88.2, R89.1; also elsewhere on the board
DRV_MISO_LOCAL: R87.2; also elsewhere on the board
DRV_MOSI_LOCAL: U24.6 (2Y); also elsewhere on the board
DRV_SCLK_LOCAL: U24.3 (1Y); also elsewhere on the board
GND: C52.2, C54.2, R89.2, R94.2, R95.2, R96.2, R97.2, R100.2, U24.1 (1OE_N), U24.4 (2OE_N), U24.7 (GND), U24.10 (3OE_N), U24.12 (4A), U26.1 (1OE_N), U26.4 (2OE_N), U26.7 (GND), U26.10 (3OE_N), U26.12 (4A); also elsewhere on the board
MOTOR_SPI_MOSI: R97.1, U26.5 (2A); also elsewhere on the board
MOTOR_SPI_SCLK: R96.1, U26.2 (1A); also elsewhere on the board
SPI_MOSI: R95.1, U24.5 (2A); also elsewhere on the board
SPI_SCLK: R94.1, U24.2 (1A); also elsewhere on the board

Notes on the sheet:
11_Wheel_SPI - Wheel owned components only See 18_Wheel_Harness for connector/bias additions; see INTERFACE_REVIEW.md for limits.



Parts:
C56, C57, C58: 1uF/50V; C_0603_1608Metric; MPN CL10A105KB8NNNC; LCSC C15849
C59, C60, C61: 22pF/50V; C_0603_1608Metric; MPN CL10C220JB8NNNC; LCSC C1653
R102, R103, R104: 330R; R_0603_1608Metric; MPN 0603WAF3300T5E; LCSC C23138
R105, R106, R107, R108, R109: 0R; R_0603_1608Metric; MPN 0603WAF0000T5E; LCSC C21189
U23: ADS7038IRTER; WQFN-16-1EP_3x3mm_P0.5mm_EP1.68x1.68mm; MPN ADS7038IRTER; LCSC C2871580

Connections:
ADC2_CS_LOCAL: U23.11 (~CS); also elsewhere on the board
ADC2_DECAP: C58.1, U23.8 (DECAP)
ADC2_MISO_LOCAL: U23.12 (SDO); also elsewhere on the board
ADC2_MOSI_LOCAL: U23.14 (SDI); also elsewhere on the board
ADC2_SCLK_LOCAL: U23.13 (SCLK); also elsewhere on the board
ADC2_SPARE3: R105.1, U23.2 (AIN3)
ADC2_SPARE4: R106.1, U23.3 (AIN4)
ADC2_SPARE5: R107.1, U23.4 (AIN5)
ADC2_SPARE6: R108.1, U23.5 (AIN6)
ADC2_SPARE7: R109.1, U23.6 (AIN7)
DRV_AVDD: C56.1, C57.1, U23.7 (AVDD), U23.10 (DVDD); also elsewhere on the board
GND: C56.2, C57.2, C58.2, C59.2, C60.2, C61.2, R105.2, R106.2, R107.2, R108.2, R109.2, U23.9 (GND), U23.17 (EP); also elsewhere on the board
WHEEL_I_A: C59.1, R102.2, U23.15 (AIN0)
WHEEL_I_B: C60.1, R103.2, U23.16 (AIN1)
WHEEL_I_C: C61.1, R104.2, U23.1 (AIN2)
WHEEL_SOA: R102.1; also elsewhere on the board
WHEEL_SOB: R103.1; also elsewhere on the board
WHEEL_SOC: R104.1; also elsewhere on the board

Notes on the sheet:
12_Wheel_Feedback - Wheel owned components only See 18_Wheel_Harness for connector/bias additions; see INTERFACE_REVIEW.md for limits.

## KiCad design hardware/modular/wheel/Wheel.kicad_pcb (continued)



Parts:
C65, C66: 100nF; C_0603_1608Metric; MPN CC0603KRX7R9BB104; LCSC C14663
C67: 22pF/50V; C_0603_1608Metric; MPN CL10C220JB8NNNC; LCSC C1653
C68, C69: 10uF/25V; C_0805_2012Metric; MPN CL21A106KAYNNNE; LCSC C15850
Q5: AO3400A; SOT-23; MPN AO3400A; LCSC C20917
R111: 10k; R_0603_1608Metric; MPN 0603WAF1002T5E; LCSC C25804
R112, R114, R120: 100k; R_0603_1608Metric; MPN 0603WAF1003T5E; LCSC C25803
R113: 34.8k; R_0603_1608Metric; MPN 0603WAF3482T5E; LCSC C23141
R115, R116, R117: 1M; R_0603_1608Metric; MPN 0603WAF1004T5E; LCSC C22935
R119: 100R; R_0603_1608Metric; MPN 0603WAF1000T5E; LCSC C22775
R121, R122, R123, R124: 47R/2W; R_2512_6332Metric; MPN RC2512JK-7W47RL; LCSC C136992
TP34: ACT_5V; TestPoint_Pad_D1.0mm
TP35: BRAKE_REF; TestPoint_Pad_D1.0mm
TP36: BRAKE_OUT; TestPoint_Pad_D1.0mm
TP37: GND; TestPoint_Pad_D1.0mm
U30: TLV1811DBVR; SOT-23-5; MPN TLV1811DBVR; LCSC C5373003
U31: LM4040AIM3-2.5/NOPB; SOT-23; MPN LM4040AIM3-2.5/NOPB; LCSC C139302

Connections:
ACT_5V: C65.1, C68.1, C69.1, R111.1, R112.1, R121.1, R122.1, R123.1, R124.1, TP34.1, U30.5 (V+); also elsewhere on the board
BRAKE_DIV_TOP: R112.2, R113.1
BRAKE_DRAIN: Q5.3 (D), R121.2, R122.2, R123.2, R124.2
BRAKE_FB_1: R115.2, R116.1
BRAKE_FB_2: R116.2, R117.1
BRAKE_GATE: Q5.1 (G), R119.2, R120.1
BRAKE_OUT: R115.1, R119.1, TP36.1, U30.1 (OUT)
BRAKE_REF: C66.1, R111.2, TP35.1, U30.4 (IN-), U31.1 (K)
BRAKE_SENSE: C67.1, R113.2, R114.1, R117.2, U30.3 (IN+)
GND: C65.2, C66.2, C67.2, C68.2, C69.2, Q5.2 (S), R114.2, R120.2, TP37.1, U30.2 (V-), U31.2 (A); also elsewhere on the board

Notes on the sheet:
13 / Autonomous ACT rail regeneration brake
DRAFT 0.5 - CIRCUIT DEVELOPMENT ONLY - NOT FOR FABRICATION
No MCU or +3V3 supply dependency. Comparator/reference/push-pull gate drive are supplied from ACT_5V. Nominal hysteresis near 5.98V ON / 5.72V OFF; see wheel checks for tolerance corners. Four parallel 47R/2W resistors = 11.75 ohms; about 3.1W ON at 6V. D2 remains the secondary transient clamp.
PROVISIONAL ENERGY ENVELOPE: characterize at <=0.5W average returned power with temperature monitoring. Resistor ratings are not enclosed-board thermal acceptance. Verify unpowered-MCU braking, startup and overshoot.


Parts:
J9: Soldered wires Signal_2x15; Wire_Signal_2x15_P2.54mm
J11: Soldered wires Power_1x02; Wire_Power_1x02_P2.54mm
R137, R138, R139, R140: 10k; R_0603_1608Metric; MPN 0603WAF1002T5E; LCSC C25804
R144, R145: 33k; R_0603_1608Metric; MPN 0603WAF3302T5E; LCSC C4216

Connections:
+3V3: J9.1; also elsewhere on the board
ACT_5V: J11.1; also elsewhere on the board
ACT_DRIVE_EN: J9.7; also elsewhere on the board
ADC2_MISO_LOCAL: J9.15; also elsewhere on the board
CS_ADC2: J9.17, R145.1; also elsewhere on the board
CS_DRV8316: J9.25, R144.1; also elsewhere on the board
DRV_FAULT_LOCAL_N: J9.3; also elsewhere on the board
DRV_MISO_LOCAL: J9.23; also elsewhere on the board
GND: J9.2, J9.4, J9.6, J9.8, J9.10, J9.12, J9.14, J9.16, J9.18, J9.20, J9.22, J9.24, J9.26, J9.28, J9.30, J11.2, R137.2, R138.2, R139.2, R140.2, R144.2, R145.2; also elsewhere on the board
MOTOR_SPI_MOSI: J9.19; also elsewhere on the board
MOTOR_SPI_SCLK: J9.21; also elsewhere on the board
SPI_MOSI: J9.27; also elsewhere on the board
SPI_SCLK: J9.29; also elsewhere on the board
WHEEL_PWM_A: J9.13, R138.1; also elsewhere on the board
WHEEL_PWM_B: J9.11, R139.1; also elsewhere on the board
WHEEL_PWM_C: J9.9, R140.1; also elsewhere on the board
WHEEL_RUN_REQ: J9.5, R137.1; also elsewhere on the board

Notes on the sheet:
MAIN J8 pin N to WHEEL J9 pin (31-N); MAIN odd / WHEEL even contacts GND. Same-side-contact FFC; component sides up, headers facing each other; no twist. POWER J10/J11: 1 ACT_5V, 2 GND. Disconnect survival outside prototype scope.
U22 raw RUN/PWM inputs default low locally. R77 remains on main. CS inputs default low only when disconnected; clocks also low and RUN disabled. R88 is 4.7k in this project to support the main-side fault pulldown. No power is carried across breakaway tabs. Do not hot plug.


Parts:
C90: 100uF/16V; CP_Elec_6.3x5.9; MPN 16SVPC100M; LCSC C136275
D6: SMBJ6.0A; D_SMB; MPN SMBJ6.0A; LCSC C83270
R146: 4.7k; R_0603_1608Metric; MPN 0603WAF4701T5E; LCSC C23162

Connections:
ACT_5V: C90.1, D6.1 (K), R146.1; also elsewhere on the board
GND: C90.2, D6.2 (A), R146.2; also elsewhere on the board

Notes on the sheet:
WHEEL-LOCAL ACT_5V ENERGY STORAGE Keep these parts on the wheel board after depanelization. No main-board capacitance credit.
C90: positive pad 1 to ACT_5V. Place beside U21 VM ceramics and brake power return. Retain C44/C45/C68/C69 and local 100nF bypasses. Wheel total: 140.4uF nominal; 47uF effective minimum. Allow 6.0mm component height plus mechanical margin.
D6: cathode pad 1 to ACT_5V. Short, wide return to local power GND. NOT a 6.5V clamp or a continuous braking load. U30/U31/Q5/R121-R124 remain the primary brake.
R146 works with the power cable absent. About 1.69s from 6.5V to 0.5V at nominal C/R, only with no external supply or motor generation. Check actual rail voltage before servicing.
DRAFT: capacitor ESR/effective C, inrush, brake transient, harness return faults and PCB layout remain unqualified. No live cable mating. See ../LOCAL_POWER_REVIEW.md and ../INTERFACE_REVIEW.md.


Board: 4 copper layers, 55.0 x 60.0 mm, 87 parts (0 on the bottom side), 57 nets.

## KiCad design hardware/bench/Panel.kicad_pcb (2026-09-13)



Board: 4 copper layers, 151.0 x 139.0 mm, 390 parts (37 on the bottom side), 193 nets.

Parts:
E_C62: 1uF/50V; C_0603_1608Metric
E_J7: Soldered wires Signal_2x04; Wire_Signal_2x04_P2.54mm
E_U27: MA735GGU-P; MPS_UTQFN14_2x2
MB1_1, MB1_2, MB1_3, MB1_4, MB1_5, MB2_1, MB2_2, MB2_3, MB2_4, MB2_5, MB3_1, MB3_2, MB3_3, MB3_4, MB3_5, MB4_1, MB4_2, MB4_3, MB4_4, MB4_5, MB5_1, MB5_2, MB5_3, MB5_4, MB5_5, MB6_1, MB6_2, MB6_3, MB6_4, MB6_5, MB7_1, MB7_2, MB7_3, MB7_4, MB7_5, MB8_1, MB8_2, MB8_3, MB8_4, MB8_5, MB9_1, MB9_2, MB9_3, MB9_4, MB9_5, MB10_1, MB10_2, MB10_3, MB10_4, MB10_5: NPTH
M_C1, M_C2, M_C3, M_C5, M_C8, M_C11, M_C14, M_C23, M_C37, M_C38, M_C39, M_C40, M_C73, M_C74, M_C77, M_C78, M_C88: 10uF/25V; C_0805_2012Metric
M_C4, M_C19, M_C20, M_C21, M_C24, M_C27, M_C63, M_C89: 1uF/50V; C_0603_1608Metric
M_C6, M_C7, M_C9, M_C10, M_C12, M_C13, M_C15, M_C16, M_C17, M_C18, M_C22, M_C28, M_C29, M_C30, M_C31, M_C32, M_C33, M_C34, M_C35, M_C36, M_C53, M_C55, M_C64, M_C70, M_C75, M_C76, M_C80, M_C83, M_C85, M_C86, M_C87: 100nF; C_0603_1608Metric
M_C25, M_C26, M_C72: 10nF; C_0603_1608Metric
M_C71, M_C81, M_C82: 2.2uF/10V; C_0603_1608Metric
M_C79: 1nF/50V; C_0603_1608Metric
M_C84: 4.7uF/10V; C_0603_1608Metric
M_D1: SMBJ12A; D_SMB
M_D2: SMBJ6.0A; D_SMB
M_D3, M_D4: BAT54-7-F; SOT-23
M_D5: SK6805-EC15; OPSCO_SK6805_EC15
M_J1: TYPE-C-31-M-12; USB_C_Receptacle_HRO_TYPE-C-31-M-12
M_J2, M_J3, M_J4, M_J10: Soldered wires Power_1x02; Wire_Power_1x02_P2.54mm
M_J6: Soldered wires Signal_2x04; Wire_Signal_2x04_P2.54mm
M_J8: Soldered wires Signal_2x15; Wire_Signal_2x15_P2.54mm
M_L1: SRP4020CC-3R3M; L_Bourns_SRP4020CC
M_Q1, M_Q2, M_Q3: 2N7002; SOT-23
M_R3, M_R4, M_R7, M_R8, M_R9, M_R10, M_R11, M_R14, M_R15, M_R16, M_R17, M_R20, M_R21, M_R22, M_R23, M_R30, M_R46, M_R47, M_R48, M_R49, M_R50, M_R51, M_R52, M_R53, M_R54, M_R55, M_R61, M_R70, M_R72, M_R73, M_R74, M_R75, M_R76, M_R77, M_R78, M_R79, M_R80, M_R99, M_R126, M_R127, M_R130, M_R131, M_R135: 10k; R_0603_1608Metric
M_R5, M_R6, M_R58: 33R; R_0603_1608Metric
M_R12, M_R18, M_R24, M_R42, M_R43, M_R56, M_R57, M_R60: 3.3k; R_0603_1608Metric
M_R25: 887k; R_0603_1608Metric
M_R26, M_R27, M_R31, M_R32, M_R33, M_R34, M_R35, M_R36, M_R37, M_R38, M_R39, M_R40, M_R62, M_R63, M_R66, M_R67, M_R71, M_R101, M_R110, M_R129, M_R133, M_R134, M_R136: 100k; R_0603_1608Metric
M_R28, M_R44, M_R45, M_R64, M_R69: 1k; R_0603_1608Metric
M_R29, M_R41, M_R65, M_R68: 22.1k; R_0603_1608Metric
M_R59: 4.7k; R_0603_1608Metric
M_R125: 0R; R_0603_1608Metric
M_R128: 330R; R_0603_1608Metric
M_R132: 39R; R_0603_1608Metric
M_R141, M_R142, M_R143: 33k; R_0603_1608Metric
M_SW1: RESET; SW_SPST_TS-1088-xR020
M_SW2: BOOT; SW_SPST_TS-1088-xR020
M_TP1, M_TP10: VBUS_USB; TestPoint_Pad_D1.0mm
M_TP2, M_TP11: PWR_5V; TestPoint_Pad_D1.0mm
M_TP3, M_TP12: ACT_5V; TestPoint_Pad_D1.0mm
M_TP4: UART_TX; TestPoint_Pad_D1.0mm
M_TP5: UART_RX; TestPoint_Pad_D1.0mm
M_TP6: MCU_EN; TestPoint_Pad_D1.0mm
M_TP7: BOOT; TestPoint_Pad_D1.0mm
M_TP8: +3V3; TestPoint_Pad_D1.0mm
M_TP9, M_TP15: GND; TestPoint_Pad_D1.0mm
M_TP13: ACT_DRIVE_EN; TestPoint_Pad_D1.0mm
M_TP14: USB_ILM; TestPoint_Pad_D1.0mm
M_TP16: CS_PAW; TestPoint_Pad_D1.0mm
M_TP17: WHEEL_RUN_REQ; TestPoint_Pad_D1.0mm
M_TP18: CS_IMU; TestPoint_Pad_D1.0mm
M_TP19: OPT_CTRL; TestPoint_Pad_D1.0mm
M_TP20: MOTOR_SPI_MOSI; TestPoint_Pad_D1.0mm
M_TP21: MOTOR_SPI_SCLK; TestPoint_Pad_D1.0mm
M_TP22: MOTOR_SPI_MISO; TestPoint_Pad_D1.0mm
M_TP23: CS_ADC2; TestPoint_Pad_D1.0mm
M_TP24: CS_MA735; TestPoint_Pad_D1.0mm
M_TP25: CS_DRV8316; TestPoint_Pad_D1.0mm
M_TP26: PAW_MOTION_N; TestPoint_Pad_D1.0mm
M_TP27: IMU_INT1; TestPoint_Pad_D1.0mm
M_TP28: DRV_FAULT_N; TestPoint_Pad_D1.0mm
M_TP29: WHEEL_PWM_A; TestPoint_Pad_D1.0mm
M_TP30: RGB_DATA; TestPoint_Pad_D1.0mm
M_TP31: BOOT_SAFE_SPARE; TestPoint_Pad_D1.0mm
M_TP32: WHEEL_PWM_B; TestPoint_Pad_D1.0mm
M_TP33: WHEEL_PWM_C; TestPoint_Pad_D1.0mm
M_TP38: RGB_5V; TestPoint_Pad_D1.0mm
M_TP39: RGB_DIN; TestPoint_Pad_D1.0mm
M_TP40: OPT_3V3; TestPoint_Pad_D1.0mm
M_TP41: OPT_1V9; TestPoint_Pad_D1.0mm
M_TP42: OPT_VDDPIX; TestPoint_Pad_D1.0mm
M_TP43: OPT_RESET_N; TestPoint_Pad_D1.0mm
M_U1: TPD2EUSB30DRTR; Texas_DRT-3
M_U2: TPS62162DSGR; Texas_DSG0008A_WSON-8-1EP_2x2mm_P0.5mm_EP0.9x1.6mm
M_U3: ESP32-S3-MINI-1-N8; ESP32-S2-MINI-1
M_U4, M_U5, M_U6: DRV8231ADSGR; Texas_DSG0008A_WSON-8-1EP_2x2mm_P0.5mm_EP0.9x1.6mm
M_U7, M_U8, M_U9: TMAG5253BA2IQDMRR; Texas_X2SON-4-1EP_1.1x1.4mm_P0.5mm_EP0.8x0.6mm
M_U10: ADS7038IRTER; WQFN-16-1EP_3x3mm_P0.5mm_EP1.68x1.68mm
M_U11: TUSB320LAIRWBR; Texas_X2QFN-12_1.6x1.6mm_P0.4mm
M_U12, M_U13: TPS259470LRPWR; Texas_RPW0010A
M_U14: SN74LVC2G04DCKR; SOT-363_SC-70-6
M_U15: SN74LVC1G123DCUR; VSSOP-8_2.3x2mm_P0.5mm
M_U16, M_U17, M_U18: SN74LVC08APWR; TSSOP-14_4.4x5mm_P0.65mm
M_U19: TLV9001IDBVR; SOT-23-5
M_U20: TPD2E2U06DCKR; SOT-323_SC-70
M_U25, M_U29, M_U37: SN74LVC125APWR; TSSOP-14_4.4x5mm_P0.65mm
M_U28: TPS22919DCKR; SOT-363_SC-70-6
M_U32: ICM-42688-P; LGA-14_3x2.5mm_P0.5mm_LayoutBorder3x4y
M_U33: TPS7A2450DBVR; SOT-23-5
M_U34: SN74LV1T34DBVR; SOT-23-5
M_U35: PMW3360DM-T2QU; PixArt_PMW3360DM_T2QU
M_U36: TLV75519PDBVR; SOT-23-5
M_U38: TPS22918DBVR; SOT-23-6
M_U39: SN74LVC1G125DBVR; SOT-23-5
TOOL1, TOOL2, TOOL3, TOOL4: NPTH
W_C41, W_C42, W_C43, W_C49, W_C51, W_C52, W_C54, W_C65, W_C66: 100nF; C_0603_1608Metric
W_C44, W_C45, W_C68, W_C69: 10uF/25V; C_0805_2012Metric
W_C46, W_C48, W_C56, W_C57, W_C58: 1uF/50V; C_0603_1608Metric
W_C47: 47nF/50V; C_0603_1608Metric
W_C50: 22uF/25V; C_0805_2012Metric
W_C59, W_C60, W_C61, W_C67: 22pF/50V; C_0603_1608Metric
W_C90: 100uF/16V; CP_Elec_6.3x5.9
W_D6: SMBJ6.0A; D_SMB
W_J5: GB1806 phase wires; MotorWire_3x1mm_P2.54mm
W_J9: Soldered wires Signal_2x15; Wire_Signal_2x15_P2.54mm
W_J11: Soldered wires Power_1x02; Wire_Power_1x02_P2.54mm
W_Q4: 2N7002; SOT-23
W_Q5: AO3400A; SOT-23
W_R81: 22R; R_0603_1608Metric
W_R82, W_R84, W_R86, W_R98, W_R111, W_R137, W_R138, W_R139, W_R140: 10k; R_0603_1608Metric
W_R83, W_R89, W_R90, W_R91, W_R92, W_R94, W_R95, W_R96, W_R97, W_R100, W_R112, W_R114, W_R120: 100k; R_0603_1608Metric
W_R87, W_R88, W_R146: 4.7k; R_0603_1608Metric
W_R102, W_R103, W_R104: 330R; R_0603_1608Metric
W_R105, W_R106, W_R107, W_R108, W_R109: 0R; R_0603_1608Metric
W_R113: 34.8k; R_0603_1608Metric
W_R115, W_R116, W_R117: 1M; R_0603_1608Metric
W_R119: 100R; R_0603_1608Metric
W_R121, W_R122, W_R123, W_R124: 47R/2W; R_2512_6332Metric
W_R144, W_R145: 33k; R_0603_1608Metric
W_TP34: ACT_5V; TestPoint_Pad_D1.0mm
W_TP35: BRAKE_REF; TestPoint_Pad_D1.0mm
W_TP36: BRAKE_OUT; TestPoint_Pad_D1.0mm
W_TP37: GND; TestPoint_Pad_D1.0mm
W_U21: DRV8316RRGFR; Texas_RGF0040E
W_U22: SN74LVC08APWR; TSSOP-14_4.4x5mm_P0.65mm
W_U23: ADS7038IRTER; WQFN-16-1EP_3x3mm_P0.5mm_EP1.68x1.68mm
W_U24, W_U26: SN74LVC125APWR; TSSOP-14_4.4x5mm_P0.65mm
W_U30: TLV1811DBVR; SOT-23-5
W_U31: LM4040AIM3-2.5/NOPB; SOT-23

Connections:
Encoder/ENC_3V3: E_C62.1, E_J7.1, E_U27.13
Encoder/ENC_CS_LOCAL: E_J7.6, E_U27.7
Encoder/ENC_MISO_LOCAL: E_J7.8, E_U27.5
Encoder/ENC_MOSI_LOCAL: E_J7.5, E_U27.8
Encoder/ENC_SCLK_LOCAL: E_J7.3, E_U27.1
Encoder/GND: E_C62.2, E_J7.2, E_J7.4, E_J7.7, E_U27.2, E_U27.4, E_U27.14
Main/+3V3: M_C2.1, M_C3.1, M_C5.1, M_C6.1, M_C16.1, M_C17.1, M_C18.1, M_C19.1, M_C20.1, M_C22.1, M_C23.1, M_C28.1, M_C29.1, M_C30.1, M_C31.1, M_C32.1, M_C34.1, M_C53.1, M_C63.1, M_C70.1, M_C71.1, M_C72.1, M_C77.1, M_C78.1, M_D4.3, M_J8.30, M_L1.2, M_R3.1, M_R4.1, M_R7.1, M_R10.1, M_R16.1, M_R22.1, M_R26.1, M_R27.1, M_R46.1, M_R71.1, M_R72.1, M_R73.1, M_R74.1, M_R75.1, M_R76.1, M_R127.1, M_TP8.1, M_U2.6, M_U3.3, M_U7.1, M_U8.1, M_U9.1, M_U10.7, M_U10.10, M_U11.12, M_U14.5, M_U15.8, M_U16.14, M_U17.14, M_U18.14, M_U19.5, M_U25.14, M_U28.1, M_U32.5, M_U32.8, M_U38.1
Main/ACT_5V: M_C7.1, M_C8.1, M_C10.1, M_C11.1, M_C13.1, M_C14.1, M_C37.1, M_C38.1, M_C39.1, M_C40.1, M_D2.1, M_J10.1, M_R67.1, M_R69.1, M_TP3.1, M_TP12.1, M_U4.5, M_U5.5, M_U6.5, M_U13.6
Main/ACT_DRIVE_EN: M_D3.3, M_J8.24, M_R49.1, M_TP13.1, M_U16.11, M_U17.2, M_U17.5, M_U17.10, M_U17.13, M_U18.2, M_U18.5
Main/ACT_DVDT: M_C26.1, M_U13.7
Main/ACT_FAULT_N: M_R45.1, M_U13.4
Main/ACT_HEARTBEAT: M_R47.1, M_U3.21, M_U15.2
Main/ACT_ILM: M_R42.1, M_R43.1, M_U13.9
Main/ACT_OVLO: M_R40.2, M_R41.1, M_U13.2
Main/ACT_PERMIT: M_U15.5, M_U16.12
Main/ACT_REQ: M_R48.1, M_U3.20, M_U16.2
Main/ACT_UVLO: M_D3.1, M_R38.2, M_R39.1, M_U13.1
Main/ACT_UV_1: M_R36.2, M_R37.1
Main/ACT_UV_2: M_R37.2, M_R38.1
Main/ACT_VMON: M_C36.1, M_D4.1, M_R67.2, M_R68.1, M_U10.6
Main/ADC2_MISO_LOCAL: M_J8.16, M_R143.1, M_U25.9
Main/ADC_CS: M_R7.2, M_U3.14, M_U10.11
Main/ADC_DECAP: M_C21.1, M_U10.8
Main/ARM_SOURCE: M_U16.3, M_U16.4
Main/ARM_VALID: M_U15.3, M_U16.6, M_U16.13
Main/BOOT: M_R4.2, M_SW2.1, M_TP7.1, M_U3.4
Main/BOOT_SAFE_SPARE: M_R80.1, M_TP31.1, M_U3.44
Main/BTN_L_CMD1: M_R50.1, M_U3.8, M_U17.1
Main/BTN_L_CMD2: M_R51.1, M_U3.9, M_U17.4
Main/BTN_L_COIL_N: M_J2.2, M_U4.8
Main/BTN_L_COIL_P: M_J2.1, M_U4.6
Main/BTN_L_IN1: M_R8.1, M_U4.3, M_U17.3
Main/BTN_L_IN2: M_R9.1, M_U4.2, M_U17.6
Main/BTN_L_ISENSE: M_R12.1, M_U4.1, M_U10.2
Main/BTN_L_VREF: M_C9.1, M_R10.2, M_R11.1, M_U4.4
Main/BTN_M_CMD1: M_R52.1, M_U3.10, M_U17.9
Main/BTN_M_CMD2: M_R53.1, M_U3.11, M_U17.12
Main/BTN_M_COIL_N: M_J3.2, M_U5.8
Main/BTN_M_COIL_P: M_J3.1, M_U5.6
Main/BTN_M_IN1: M_R14.1, M_U5.3, M_U17.8
Main/BTN_M_IN2: M_R15.1, M_U5.2, M_U17.11
Main/BTN_M_ISENSE: M_R18.1, M_U5.1, M_U10.3
Main/BTN_M_VREF: M_C12.1, M_R16.2, M_R17.1, M_U5.4
Main/BTN_R_CMD1: M_R54.1, M_U3.12, M_U18.1
Main/BTN_R_CMD2: M_R55.1, M_U3.13, M_U18.4
Main/BTN_R_COIL_N: M_J4.2, M_U6.8
Main/BTN_R_COIL_P: M_J4.1, M_U6.6
Main/BTN_R_IN1: M_R20.1, M_U6.3, M_U18.3
Main/BTN_R_IN2: M_R21.1, M_U6.2, M_U18.6
Main/BTN_R_ISENSE: M_R24.1, M_U6.1, M_U10.4
Main/BTN_R_VREF: M_C15.1, M_R22.2, M_R23.1, M_U6.4
Main/BUCK_SW: M_L1.1, M_U2.7
Main/CC_OUT1: M_R26.2, M_U3.18, M_U11.7, M_U14.1
Main/CC_OUT2: M_R27.2, M_U3.19, M_U11.8, M_U14.3
Main/CC_OUT2_INV: M_U14.4, M_U16.10
Main/CC_VBUS_DET: M_R25.2, M_U11.4
Main/CS_ADC2: M_J8.14, M_R74.2, M_TP23.1, M_U3.32, M_U25.10
Main/CS_DRV8316: M_J8.6, M_R76.2, M_TP25.1, M_U3.34, M_U25.1
Main/CS_IMU: M_R73.2, M_TP18.1, M_U3.25, M_U32.12
Main/CS_MA735: M_R75.2, M_TP24.1, M_U3.33, M_U25.4, M_U29.9
Main/CS_PAW: M_R72.2, M_TP16.1, M_U3.6, M_U37.1, M_U37.4, M_U37.10, M_U39.2
Main/DRV_FAULT_LOCAL_N: M_J8.28, M_R141.1, M_U25.12
Main/DRV_FAULT_N: M_TP28.1, M_U3.37, M_U25.11
Main/DRV_MISO_LOCAL: M_J8.8, M_R142.1, M_U25.2
Main/ENC_3V3: M_C55.1, M_C64.1, M_J6.1, M_R99.1, M_R125.2, M_U28.6, M_U29.13, M_U29.14
Main/ENC_CS_LOCAL: M_J6.6, M_R99.2, M_U29.8
Main/ENC_MISO_LOCAL: M_J6.8, M_R101.1, M_U25.5
Main/ENC_MOSI_LOCAL: M_J6.5, M_U29.6
Main/ENC_QOD: M_R125.1, M_U28.5
Main/ENC_SCLK_LOCAL: M_J6.3, M_U29.3
Main/GND: M_C1.2, M_C2.2, M_C3.2, M_C4.2, M_C5.2, M_C6.2, M_C7.2, M_C8.2, M_C9.2, M_C10.2, M_C11.2, M_C12.2, M_C13.2, M_C14.2, M_C15.2, M_C16.2, M_C17.2, M_C18.2, M_C19.2, M_C20.2, M_C21.2, M_C22.2, M_C23.2, M_C24.2, M_C25.2, M_C26.2, M_C28.2, M_C29.2, M_C30.2, M_C31.2, M_C32.2, M_C33.2, M_C34.2, M_C35.2, M_C36.2, M_C37.2, M_C38.2, M_C39.2, M_C40.2, M_C53.2, M_C55.2, M_C63.2, M_C64.2, M_C70.2, M_C71.2, M_C72.2, M_C73.2, M_C74.2, M_C75.2, M_C76.2, M_C77.2, M_C78.2, M_C79.2, M_C80.2, M_C81.2, M_C82.2, M_C83.2, M_C84.2, M_C85.2, M_C86.2, M_C87.2, M_C88.2, M_C89.2, M_D1.2, M_D2.2, M_D5.4, M_J1.A1, M_J1.A12, M_J1.B1, M_J1.B12, M_J1.SH, M_J6.2, M_J6.4, M_J6.7, M_J8.1, M_J8.3, M_J8.5, M_J8.7, M_J8.9, M_J8.11, M_J8.13, M_J8.15, M_J8.17, M_J8.19, M_J8.21, M_J8.23, M_J8.25, M_J8.27, M_J8.29, M_J10.2, M_Q1.2, M_Q2.2, M_Q3.2, M_R8.2, M_R9.2, M_R11.2, M_R12.2, M_R14.2, M_R15.2, M_R17.2, M_R18.2, M_R20.2, M_R21.2, M_R23.2, M_R24.2, M_R30.2, M_R35.2, M_R39.2, M_R41.2, M_R42.2, M_R43.2, M_R47.2, M_R48.2, M_R49.2, M_R50.2, M_R51.2, M_R52.2, M_R53.2, M_R54.2, M_R55.2, M_R58.2, M_R62.2, M_R63.2, M_R66.2, M_R68.2, M_R69.2, M_R70.2, M_R77.2, M_R78.2, M_R79.2, M_R80.2, M_R101.2, M_R110.2, M_R126.2, M_R129.2, M_R130.2, M_R134.2, M_R141.2, M_R142.2, M_R143.2, M_SW1.2, M_SW2.2, M_TP9.1, M_TP15.1, M_U1.3, M_U2.1, M_U2.4, M_U2.5, M_U2.9, M_U3.1, M_U3.2, M_U3.42, M_U3.43, M_U3.46, M_U3.47, M_U3.48, M_U3.49, M_U3.50, M_U3.51, M_U3.52, M_U3.53, M_U3.54, M_U3.55, M_U3.56, M_U3.57, M_U3.58, M_U3.59, M_U3.60, M_U3.61, M_U3.62, M_U3.63, M_U3.64, M_U3.65, M_U4.7, M_U4.9, M_U5.7, M_U5.9, M_U6.7, M_U6.9, M_U7.2, M_U7.5, M_U8.2, M_U8.5, M_U9.2, M_U9.5, M_U10.9, M_U10.17, M_U11.3, M_U11.10, M_U11.11, M_U12.8, M_U13.8, M_U14.2, M_U15.1, M_U15.4, M_U16.7, M_U17.7, M_U18.7, M_U18.12, M_U18.13, M_U19.2, M_U20.3, M_U25.7, M_U25.13, M_U28.2, M_U29.1, M_U29.4, M_U29.7, M_U29.10, M_U29.12, M_U32.6, M_U32.7, M_U33.2, M_U34.3, M_U35.8, M_U36.2, M_U37.7, M_U37.13, M_U38.2, M_U39.1, M_U39.3
Main/HALL_EN: M_R110.1, M_U7.3, M_U8.3, M_U9.3, M_U16.5, M_U18.8, M_U28.3, M_U33.3, M_U38.3
Main/HALL_L: M_U7.4, M_U10.15
Main/HALL_M: M_U8.4, M_U10.16
Main/HALL_R: M_U9.4, M_U10.1
Main/ILM_BASE_1: M_R56.2, M_R57.1
Main/ILM_BASE_2: M_R57.2, M_R58.1
Main/ILM_HIGH_D: M_Q2.3, M_R60.2, M_R61.2
Main/ILM_MED_D: M_Q1.3, M_R59.2
Main/IMU_INT1: M_R127.2, M_TP27.1, M_U3.36, M_U32.4
Main/IMU_PIN9: M_R126.1, M_U32.9
Main/LOGIC_PG: M_R28.1, M_U2.8
Main/MCU_EN: M_C4.1, M_R3.2, M_R28.2, M_R44.2, M_R45.2, M_SW1.1, M_TP6.1, M_U3.45, M_U18.10
Main/MCU_USB_DM: M_R5.1, M_U3.23
Main/MCU_USB_DP: M_R6.1, M_U3.24
Main/MOTOR_SPI_MISO: M_TP22.1, M_U3.31, M_U25.8
Main/MOTOR_SPI_MOSI: M_J8.12, M_TP20.1, M_U3.28
Main/MOTOR_SPI_SCLK: M_J8.10, M_TP21.1, M_U3.29
Main/OPT_1V9: M_C82.1, M_C83.1, M_R132.1, M_TP41.1, M_U35.4, M_U36.5
Main/OPT_3V3: M_C80.1, M_C81.1, M_C86.1, M_C87.1, M_R131.1, M_R133.1, M_R135.1, M_R136.1, M_TP40.1, M_U35.5, M_U36.1, M_U36.3, M_U37.14, M_U38.6, M_U39.5
Main/OPT_CS_N: M_R131.2, M_U35.13, M_U39.4
Main/OPT_CTRL: M_R79.1, M_TP19.1, M_U3.26, M_U37.12
Main/OPT_LED_P: M_R132.2, M_U35.15
Main/OPT_MISO: M_R135.2, M_U35.12, M_U37.9
Main/OPT_MOSI: M_R134.1, M_U35.11, M_U37.3
Main/OPT_RAMP_CT: M_C79.1, M_U38.4
Main/OPT_RESET_N: M_TP43.1, M_U35.7, M_U37.11
Main/OPT_SCLK: M_R133.2, M_U35.10, M_U37.6
Main/OPT_VDDPIX: M_C84.1, M_C85.1, M_TP42.1, M_U35.3
Main/PAW_MOTION_N: M_R136.2, M_TP26.1, M_U3.35, M_U35.9
Main/PWR_5V: M_C1.1, M_C73.1, M_C88.1, M_C89.1, M_R36.1, M_R40.1, M_TP2.1, M_TP11.1, M_U2.2, M_U2.3, M_U12.6, M_U13.5, M_U33.1
Main/RGB_5V: M_C74.1, M_C75.1, M_C76.1, M_D5.2, M_R130.1, M_TP38.1, M_U33.5, M_U34.5
Main/RGB_BUFFER_OUT: M_R128.1, M_U34.4
Main/RGB_DATA: M_R78.1, M_TP30.1, M_U3.41, M_U34.2
Main/RGB_DIN: M_D5.1, M_R128.2, M_R129.1, M_TP39.1
Main/SENS_REQ: M_R70.1, M_U3.22, M_U18.9
Main/SOURCE_3A: M_Q2.1, M_R63.1, M_U16.8
Main/SOURCE_OK: M_Q1.1, M_R62.1, M_U14.6, M_U16.1, M_U16.9
Main/SPI_MISO: M_U3.17, M_U10.12, M_U25.3, M_U25.6, M_U32.1, M_U37.8
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

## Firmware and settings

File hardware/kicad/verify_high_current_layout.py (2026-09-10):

# SPDX-License-Identifier: GPL-3.0-or-later
"""Screen actuator copper resistance and local ground spreading with KiCad.

This is a layout regression check, not an ampacity or thermal simulation. The
resistance model counts whole traversed tracks and full via barrels, gives no
credit for parallel copper, and excludes pads, solder, connectors and silicon.
Run physical DRC, distribution and USB reference checks alongside this checker.
"""

import argparse
import hashlib
import heapq
import json
import math
import re
from pathlib import Path

import pcbnew as pcb

ROOT = Path(__file__).resolve().parents[2]
TEMPERATURE_C = 80
RHO = .01724 * (1 + .00393 * (TEMPERATURE_C - 20))  # ohm mm^2 / metre
THICKNESS_MM = {pcb.F_Cu: .035, pcb.In2_Cu: .030, pcb.B_Cu: .035}
BOARD_MM = 1.578
PLATING_MM = .020  # Screening assumption, pending manufacturer confirmation.

# Project resistance budgets, not manufacturer current ratings. Each path must
# have a physically connected route below its budget without using a zone.
PATHS = [(('U12', '6'), ('U13', '5'), 50)]
PATHS += [(('U13', '6'), (r, '5'), 85) for r in ['U4', 'U5', 'U6']]
PATHS += [(('U13', '6'), ('U21', str(p)), 40) for p in [9, 10, 11]]
for driver, connector in [('U4', 'J2'), ('U5', 'J3'), ('U6', 'J4')]:
    PATHS += [((driver, '6'), (connector, '1'), 25),
              ((driver, '8'), (connector, '2'), 25)]
for phase, pins in enumerate([(13, 14), (16, 17), (19, 20)], 1):
    PATHS += [(('U21', str(p)), ('J5', str(phase)), 55) for p in pins]
for ref in ['R121', 'R122', 'R123', 'R124']:
    PATHS += [(('U13', '6'), (ref, '1'), 100), (('Q5', '3'), (ref, '2'), 65)]

# Minimum saved filled area connected locally to the device, in mm^2. These
# protect the reviewed geometry; they do not imply a junction temperature.
SPREADERS = {'U4': ('9', 2, 20, 10), 'U5': ('9', 2, 17, 10),
             'U6': ('9', 2, 35, 20), 'U21': ('41', 5, 30, 25),
             'Q5': ('2', 1.5, 2, 4)}
BULK_REFS = {'C8', 'C11', 'C14', 'C37', 'C38', 'C39', 'C40', 'C44', 'C45', 'C68', 'C69'}
BYPASS_REFS = {'C7', 'C10', 'C13', 'C41', 'C42', 'C43', 'C65'}


def verify_stackup(source):
    match = re.search(r'^\t\t\(stackup\b.*?^\t\t\)\n', source, re.M | re.S)
    if not match:
        return ['High-current model: missing saved stackup']
    layers = {}
    for layer in re.finditer(r'^\t\t\t\(layer "([^"]+)"(.*?)^\t\t\t\)', match[0], re.M | re.S):
        thickness = re.search(r'\(thickness ([0-9.]+)\)', layer[2])
        if thickness:
            layers[layer[1]] = float(thickness[1])
    expected = {'F.Cu': .035, 'In1.Cu': .030, 'In2.Cu': .030, 'B.Cu': .035}
    errors = [f'High-current model: {name} copper thickness differs from {value} mm'
              for name, value in expected.items() if abs(layers.get(name, -1) - value) > .000001]
    total = sum(value for name, value in layers.items() if name in expected or name.startswith('dielectric'))
    if abs(total - BOARD_MM) > .000001:
        errors.append('High-current model: saved stack thickness differs from barrel length assumption')
    return errors


def uid(item):
    return item.m_Uuid.AsString()


class CopperGraph:
    """Native direct contacts; no geometric guesses or whole-net shortcuts."""

    def __init__(self, board):
        conn = board.GetConnectivity()
        self.items = {uid(t): t for t in board.GetTracks()}
        self.pads = {}
        for footprint in board.GetFootprints():
            for pad in footprint.Pads():
                if pad.GetNumber():
                    self.items[uid(pad)] = pad
                    self.pads.setdefault((footprint.GetReference(), pad.GetNumber()), pad)
        self.adj, self.cost = {}, {}
        for key, item in self.items.items():
            contacts = list(conn.GetConnectedTracks(item)) + list(conn.GetConnectedPads(item))
            self.adj[key] = {uid(t) for t in contacts if uid(t) in self.items
                             and t.GetNetname() == item.GetNetname()}
            if isinstance(item, pcb.PCB_VIA):
                drill = pcb.ToMM(item.GetDrillValue())
                # Thin-wall barrel estimate. Count full board thickness even
                # for a transition between adjacent layers.
                self.cost[key] = RHO * BOARD_MM / 1000 / (math.pi * drill * PLATING_MM)
            elif isinstance(item, pcb.PCB_TRACK):
                thickness = THICKNESS_MM.get(item.GetLayer(), .030)
                self.cost[key] = RHO * pcb.ToMM(item.GetLength()) / 1000 / (
                    pcb.ToMM(item.GetWidth()) * thickness)
            else:
                self.cost[key] = 0

    def path(self, start, end, allowed=None):
        queue, seen = [(0, start, [])], set()
        while queue:
            cost, key, path = heapq.heappop(queue)
            if key in seen or (allowed is not None and key not in allowed):
                continue
            seen.add(key)
            path = path + [key]
            if key == end:
                return cost, path
            for neighbor in self.adj[key] - seen:
                heapq.heappush(queue, (cost + self.cost[neighbor], neighbor, path))
        return None


def filled_area_at(zone, points):
    """Sum filled polygons touched by the specified local contacts, minus holes."""
    poly = zone.GetFilledPolysList(zone.GetLayer())
    total = 0
    for index in range(poly.OutlineCount()):
        if any(poly.Contains(point, index) for point in points):
            total += abs(poly.COutline(index).Area())
            total -= sum(abs(poly.CHole(index, h).Area()) for h in range(poly.HoleCount(index)))
    return total / 1e12


def verify(board):
    board.BuildConnectivity()
    graph = CopperGraph(board)
    errors, paths, spreading = [], [], {}
    if board.GetCopperLayerCount() != 4:
        errors.append('Resistance model requires the reviewed four-layer stackup')
    for source, target, limit in PATHS:
        label = '.'.join(source) + ' -> ' + '.'.join(target)
        a, b = graph.pads.get(source), graph.pads.get(target)
        found = graph.path(uid(a), uid(b)) if a is not None and b is not None else None
        if found is None:
            errors.append(label + ': no copper path')
            continue
        resistance, route = found
        tracks = [graph.items[k] for k in route if isinstance(graph.items[k], pcb.PCB_TRACK)
                  and not isinstance(graph.items[k], pcb.PCB_VIA)]
        vias = [graph.items[k] for k in route if isinstance(graph.items[k], pcb.PCB_VIA)]
        paths.append({'path': label, 'net': a.GetNetname(),
                      'screening_milliohms': round(resistance * 1000, 3), 'budget_milliohms': limit,
                      'counted_track_length_mm': round(sum(pcb.ToMM(t.GetLength()) for t in tracks), 3),
                      'minimum_track_width_mm': min(pcb.ToMM(t.GetWidth()) for t in tracks),
                      'counted_full_barrels': len(vias), 'route_uuids': route})
        if any(t.GetLayer() == pcb.In1_Cu for t in tracks):
            errors.append(label + ': power track uses the In1 ground-reference layer')
        if resistance * 1000 > limit:
            errors.append(f'{label}: {resistance * 1000:.3f} mOhm exceeds {limit} mOhm layout budget')

    for ref, (pin, radius, front_min, back_min) in SPREADERS.items():
        pad = graph.pads.get((ref, pin))
        if pad is None:
            errors.append(f'{ref}: missing thermal/source ground pad')
            continue
        # Local front tracks/pads only: a remote connection through In1 is not
        # evidence of a short connection from the device to its thermal vias.
        origin = pad.GetPosition()
        allowed = {key for key, item in graph.items.items()
                   if item.GetNetname() == 'GND' and item.IsOnLayer(pcb.F_Cu)
                   and pcb.ToMM((item.GetPosition() - origin).EuclideanNorm()) <= radius
                   and (not isinstance(item, pcb.PCB_TRACK) or
                        pcb.ToMM((item.GetEnd() - origin).EuclideanNorm()) <= radius)}
        vias = [t for key, t in graph.items.items() if isinstance(t, pcb.PCB_VIA)
                and key in allowed and graph.path(uid(pad), key, allowed) is not None]
        minimum_vias = 1 if ref == 'Q5' else 4
        if len(vias) < minimum_vias:
            errors.append(f'{ref}: fewer than {minimum_vias} vias with a local front copper connection')
        result = {'local_front_connected_vias': len(vias)}
        for layer, minimum in [(pcb.F_Cu, front_min), (pcb.B_Cu, back_min)]:
            name = 'ACTUATOR_' + ref + '_GND_' + board.GetLayerName(layer)
            zones = [z for z in board.Zones() if z.GetZoneName() == name and not z.GetIsRuleArea()]
            if len(zones) != 1:
                errors.append(f'{name}: expected one local ground spreader')
                continue
            zone = zones[0]
            if zone.GetNetname() != 'GND' or zone.GetLayer() != layer:
                errors.append(f'{name}: incorrect ground net or layer')
                continue
            if zone.GetPadConnection() != pcb.ZONE_CONNECTION_FULL:
                errors.append(f'{name}: expected solid pad connections')
            points = [origin] if layer == pcb.F_Cu else [v.GetPosition() for v in vias]
            area = filled_area_at(zone, points)
            result[board.GetLayerName(layer) + '_local_filled_mm2'] = round(area, 3)
            if area < minimum:
                errors.append(f'{name}: {area:.3f} mm2 of local filled copper is below {minimum} mm2')
        spreading[ref] = result

    capacitors = {}
    for footprint in board.GetFootprints():
        ref = footprint.GetReference()
        nets = {p.GetNetname() for p in footprint.Pads() if p.GetNumber()}
        if ref.startswith('C') and nets == {'ACT_5V', 'GND'}:
            capacitors[ref] = footprint.GetValue()
    if set(capacitors) != BULK_REFS | BYPASS_REFS:
        errors.append('ACT capacitor inventory changed: review nominal storage/inrush/discharge estimates')
    for ref, value in capacitors.items():
        expected = '10uF/25V' if ref in BULK_REFS else '100nF'
        if value != expected:
            errors.append(f'{ref}: ACT capacitor value differs from reviewed {expected}')
    capacitance_uF = 110.7  # Only valid with the inventory/value checks above.
    return {'scope': 'Actuator feed/output trace-barrel resistance screening and local ground spreading',
            'model': {'copper_temperature_C': TEMPERATURE_C, 'outer_copper_mm': .035,
                      'inner_copper_mm': .030, 'full_barrel_length_mm': BOARD_MM,
                      'assumed_barrel_plating_mm': PLATING_MM,
                      'limitations': 'Whole traversed tracks and full barrels; no parallel credit. '
                      'Excludes pads, solder, connectors, semiconductors, plane return resistance, '
                      'inductance and thermal rise. Thickness/plating assumptions need fabrication confirmation.'},
            'current_paths': paths, 'ground_spreading': spreading,
            'actuator_capacitors': {'parts': capacitors, 'nominal_direct_capacitance_uF': capacitance_uF,
                                   'capacitor_only_inrush_mA_at_0_2V_per_ms': capacitance_uF * .2,
                                   'nominal_1k_bleed_time_constant_ms': capacitance_uF,
                                   'effective_capacitance_acceptance_uF': 47,
                                   'limitations': 'Nominal nameplate values only; excludes charge-pump/AVDD/'
                                   'buck capacitors and active loads. DC bias, tolerance and temperature '
                                   'require separate qualification.'},
            'native_unconnected_connections': board.GetConnectivity().GetUnconnectedCount(False),
            'errors': errors}


def main():
    parser = argparse.ArgumentParser(description=__doc__)
    parser.add_argument('--board', type=Path, default=ROOT / 'hardware/kicad/MagMouse.kicad_pcb')
    parser.add_argument('--output', type=Path, default=ROOT / 'build/pcb-review/high-current-layout-checks.json')
    args = parser.parse_args()
    report = verify(pcb.LoadBoard(str(args.board.resolve())))
    report['errors'].extend(verify_stackup(args.board.read_text(encoding='utf-8')))
    report['board_sha256'] = hashlib.sha256(args.board.read_bytes()).hexdigest()
    args.output.parent.mkdir(parents=True, exist_ok=True)
    args.output.write_text(json.dumps(report, indent=2) + '\n', encoding='utf-8')
    print(json.dumps(report, indent=2))
    return int(bool(report['errors']))


if __name__ == '__main__':
    raise SystemExit(main())

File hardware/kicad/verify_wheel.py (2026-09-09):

# SPDX-License-Identifier: GPL-3.0-or-later
"""Check exported wheel wiring, shutdown logic and provisional brake arithmetic.

This is a static review, not motor, power-ramp, firmware or thermal simulation.
See WHEEL_REVIEW.md for datasheet bounds and measurements still required.
"""
import argparse
import itertools
import json
import math
import re
from pathlib import Path
import xml.etree.ElementTree as ET

ROOT = Path(__file__).resolve().parents[2]


def main():
    parser = argparse.ArgumentParser(description=__doc__)
    parser.add_argument('--netlist', type=Path, default=ROOT / 'build/kicad-review/netlist.xml')
    parser.add_argument('--encoder-netlist', type=Path, default=ROOT / 'build/encoder-review/netlist.xml')
    parser.add_argument('--output', type=Path, default=ROOT / 'build/kicad-review/wheel-checks.json')
    args = parser.parse_args()
    xml = ET.parse(args.netlist).getroot()
    encoder = ET.parse(args.encoder_netlist).getroot()
    main_refs = {c.get('ref') for c in xml.findall('./components/comp')}
    encoder_refs = {c.get('ref') for c in encoder.findall('./components/comp')}
    # Shared net names describe the wired interface. verify_encoder.py checks
    # both physical connectors and the harness mapping independently.
    for comp in encoder.findall('./components/comp'):
        xml.find('components').append(comp)
    components = {c.get('ref'): c for c in xml.findall('./components/comp')}
    nets = {}
    for tree in [xml, encoder]:
        for n in tree.findall('./nets/net'):
            nets.setdefault(n.get('name'), set()).update((p.get('ref'), p.get('pin')) for p in n.findall('node'))
    pin_net = {pin: net for net, nodes in nets.items() for pin in nodes}
    errors, expected = [], {}
    if main_refs & encoder_refs:
        errors.append('Duplicate references across motherboard and encoder board')
    if {'U27', 'C62'} & main_refs or not {'U27', 'C62', 'J7'} <= encoder_refs or 'J6' not in main_refs:
        errors.append('Encoder board split is incomplete; export both current schematics')

    def check(condition, message):
        if not condition:
            errors.append(message)

    def device(ref, mapping):
        expected.update({(ref, str(pin)): net for pin, net in mapping.items()})

    def net(ref, pin):
        return pin_net.get((ref, str(pin)))

    def value(ref):
        return components[ref].findtext('value')

    def resistance(ref):
        raw = value(ref).split('/')[0]
        return float(raw.rstrip('RkM')) * {'R': 1, 'k': 1e3, 'M': 1e6}[raw[-1]]

    device('U21', {9:'ACT_5V',10:'ACT_5V',11:'ACT_5V',23:'ACT_DRIVE_EN',21:'WHEEL_DRVOFF',
                  27:'DRV_INHA',29:'DRV_INHB',31:'DRV_INHC',28:'WHEEL_RUN_EN',30:'WHEEL_RUN_EN',32:'WHEEL_RUN_EN',
                  36:'DRV_CS_LOCAL',35:'DRV_SCLK_LOCAL',34:'DRV_MOSI_LOCAL',37:'DRV_AVDD',25:'DRV_AVDD',
                  13:'WHEEL_PHASE_A',14:'WHEEL_PHASE_A',16:'WHEEL_PHASE_B',17:'WHEEL_PHASE_B',19:'WHEEL_PHASE_C',20:'WHEEL_PHASE_C',
                  40:'WHEEL_SOA',39:'WHEEL_SOB',38:'WHEEL_SOC',8:'WHEEL_CP',7:'WHEEL_CPH',6:'WHEEL_CPL',
                  5:'WHEEL_BUCK_SW',3:'WHEEL_BUCK_OUT',33:'DRV_MISO_LOCAL',22:'DRV_FAULT_LOCAL_N',
                  2:'GND',26:'GND',4:'GND',12:'GND',15:'GND',18:'GND',41:'GND'})
    device('U22', {1:'ACT_DRIVE_EN',2:'WHEEL_RUN_REQ',3:'WHEEL_RUN_EN',4:'WHEEL_PWM_A',5:'WHEEL_RUN_EN',6:'DRV_INHA',
                  9:'WHEEL_PWM_B',10:'WHEEL_RUN_EN',8:'DRV_INHB',12:'WHEEL_PWM_C',13:'WHEEL_RUN_EN',11:'DRV_INHC',7:'GND',14:'+3V3'})
    device('Q4', {1:'WHEEL_RUN_EN',2:'GND',3:'WHEEL_DRVOFF'})
    device('J5', {1:'WHEEL_PHASE_A',2:'WHEEL_PHASE_B',3:'WHEEL_PHASE_C'})
    device('U23', {15:'WHEEL_I_A',16:'WHEEL_I_B',1:'WHEEL_I_C',2:'ADC2_SPARE3',3:'ADC2_SPARE4',4:'ADC2_SPARE5',5:'ADC2_SPARE6',6:'ADC2_SPARE7',
                  7:'DRV_AVDD',10:'DRV_AVDD',9:'GND',17:'GND',8:'ADC2_DECAP',11:'ADC2_CS_LOCAL',13:'ADC2_SCLK_LOCAL',14:'ADC2_MOSI_LOCAL',12:'ADC2_MISO_LOCAL'})
    device('U27', {13:'ENC_3V3',1:'ENC_SCLK_LOCAL',8:'ENC_MOSI_LOCAL',7:'ENC_CS_LOCAL',14:'GND',2:'GND',4:'GND',5:'ENC_MISO_LOCAL'})
    device('U28', {1:'+3V3',2:'GND',3:'HALL_EN',5:'ENC_QOD',6:'ENC_3V3'})
    device('U30', {3:'BRAKE_SENSE',4:'BRAKE_REF',1:'BRAKE_OUT',5:'ACT_5V',2:'GND'})
    device('U31', {1:'BRAKE_REF',2:'GND'})
    device('Q5', {1:'BRAKE_GATE',2:'GND',3:'BRAKE_DRAIN'})
    channels = [(1,2,3),(4,5,6),(10,9,8),(13,12,11)]
    for ref, rail, bus, cs, local in [('U24','DRV_AVDD','SPI','CS_DRV8316','DRV'),
                                     ('U26','DRV_AVDD','MOTOR_SPI','CS_ADC2','ADC2'),
                                     ('U29','ENC_3V3','SPI','CS_MA735','ENC')]:
        device(ref, {7:'GND',14:rail,13:rail,12:'GND'})
        for (oe,a,y),source,dest in zip(channels,[bus+'_SCLK',bus+'_MOSI',cs],
                                      [local+'_SCLK_LOCAL',local+'_MOSI_LOCAL',local+'_CS_LOCAL']):
            device(ref, {oe:'GND',a:source,y:dest})
    device('U25', {7:'GND',14:'+3V3',1:'CS_DRV8316',2:'DRV_MISO_LOCAL',3:'SPI_MISO',
                  4:'CS_MA735',5:'ENC_MISO_LOCAL',6:'SPI_MISO',10:'CS_ADC2',9:'ADC2_MISO_LOCAL',8:'MOTOR_SPI_MISO',
                  13:'GND',12:'DRV_FAULT_LOCAL_N',11:'DRV_FAULT_N'})
    passive = {
        'R81':('WHEEL_BUCK_SW','WHEEL_BUCK_OUT'),'R82':('DRV_AVDD','WHEEL_DRVOFF'),
        'R83':('WHEEL_RUN_EN','GND'),'R84':('ACT_DRIVE_EN','GND'),
        'R86':('DRV_AVDD','DRV_CS_LOCAL'),'R87':('DRV_AVDD','DRV_MISO_LOCAL'),
        'R88':('DRV_AVDD','DRV_FAULT_LOCAL_N'),'R89':('DRV_FAULT_LOCAL_N','GND'),
        'R90':('DRV_INHA','GND'),'R91':('DRV_INHB','GND'),'R92':('DRV_INHC','GND'),
        'R98':('DRV_AVDD','ADC2_CS_LOCAL'),'R99':('ENC_3V3','ENC_CS_LOCAL'),
        'R100':('ADC2_MISO_LOCAL','GND'),'R101':('ENC_MISO_LOCAL','GND'),
        'R110':('HALL_EN','GND'),'R125':('ENC_QOD','ENC_3V3'),
        'R111':('ACT_5V','BRAKE_REF'),'R112':('ACT_5V','BRAKE_DIV_TOP'),
        'R113':('BRAKE_DIV_TOP','BRAKE_SENSE'),'R114':('BRAKE_SENSE','GND'),
        'R115':('BRAKE_OUT','BRAKE_FB_1'),'R116':('BRAKE_FB_1','BRAKE_FB_2'),
        'R117':('BRAKE_FB_2','BRAKE_SENSE'),'R119':('BRAKE_OUT','BRAKE_GATE'),'R120':('BRAKE_GATE','GND'),
        'C46':('WHEEL_CP','ACT_5V'),'C47':('WHEEL_CPH','WHEEL_CPL'),
        'C48':('DRV_AVDD','GND'),'C49':('DRV_AVDD','GND'),'C50':('WHEEL_BUCK_OUT','GND'),
        'C56':('DRV_AVDD','GND'),'C57':('DRV_AVDD','GND'),'C58':('ADC2_DECAP','GND'),
        'C62':('ENC_3V3','GND'),'C63':('+3V3','GND'),'C64':('ENC_3V3','GND'),
        'C65':('ACT_5V','GND'),'C66':('BRAKE_REF','GND'),'C67':('BRAKE_SENSE','GND'),
        'C68':('ACT_5V','GND'),'C69':('ACT_5V','GND')}
    for i, phase in enumerate('ABC'):
        passive[f'R{102+i}'] = ('WHEEL_SO'+phase,'WHEEL_I_'+phase)
        passive[f'C{59+i}'] = ('WHEEL_I_'+phase,'GND')
    for i in range(5):
        passive[f'R{105+i}'] = (f'ADC2_SPARE{3+i}','GND')
        check(value(f'R{105+i}') == '0R', 'Spare ADC channel link is not zero ohms')
    for i in range(4):
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

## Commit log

2026-09-08 Add KiCad starter schematic and custom-coil button design
    [01_Power_USB.kicad_sch, 02_MCU.kicad_sch, 03_Buttons.kicad_sch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]
2026-09-08 Resolve KiCad component sourcing and missing footprints
    [01_Power_USB.kicad_sch, 02_MCU.kicad_sch, 03_Buttons.kicad_sch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]
2026-09-08 Implement USB-C power control schematic and validation
    [01_Power_USB.kicad_sch, 02_MCU.kicad_sch, 03_Buttons.kicad_sch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]
2026-09-08 Allocate ESP32-S3 GPIO and peripheral resources
    [01_Power_USB.kicad_sch, 02_MCU.kicad_sch, 03_Buttons.kicad_sch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]
2026-09-08 Start motherboard PCB placement and review workflow
    [MagMouse.kicad_pcb]
2026-09-08 Add wheel control circuitry and autonomous regeneration brake
    [02_MCU.kicad_sch, 09_Interface_Reservations.kicad_sch, 10_Wheel_Driver.kicad_sch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]
2026-09-09 Add IMU and RGB circuits and document optical sourcing
    [14_IMU.kicad_sch, 15_RGB_Status.kicad_sch, MagMouse.kicad_pcb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]
2026-09-09 Add PMW3360 optical circuitry and PCB-first mechanical datum
    [16_Optical_Power.kicad_sch, 17_Optical_Sensor.kicad_sch, MagMouse.kicad_pcb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]
2026-09-09 Place motherboard, add upright encoder PCB and route logic buck
    [12_Wheel_Feedback.kicad_sch, Encoder.kicad_pcb, Encoder.kicad_sch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]
2026-09-09 Route input power and Type-C detection, select PCB stackup
    [05_Protected_Power.kicad_sch, MagMouse.kicad_pcb]
2026-09-09 Route U13 local actuator power and protection
    [05_Protected_Power.kicad_sch, MagMouse.kicad_pcb]
2026-09-10 Route actuator distribution and USB data with copper validation
    [MagMouse.kicad_pcb]
2026-09-10 Route actuator power and analog sensing with layout checks
    [MagMouse.kicad_pcb]
2026-09-10 Review analog routing and plan modular assembly panel
    [Encoder-envelope.kicad_pcb, MagMouse.kicad_pcb, Main-envelope.kicad_pcb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]
2026-09-10 Split modular schematics and route wheel power and analog copper
    [01_Power_USB.kicad_sch, 02_MCU.kicad_sch, 03_Buttons.kicad_sch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]
2026-09-10 Finish wheel routing and place split main PCB
    [Main.kicad_pcb, Wheel.kicad_pcb]
2026-09-11 Complete shaped main PCB routing and return-path checks
    [Main.kicad_pcb]
2026-09-11 Add JLCPCB quote packages and cost reduction assessment
    [Encoder-BOM-QUOTE.csv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]
2026-09-11 Prepare self-assembled bench panel and order-readiness plan
    [Encoder.kicad_pcb, Main.kicad_pcb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]
2026-09-12 Prepare wired Rev-A bench boards and submit manufacturing review
    [01_Power_USB.kicad_sch, 03_Buttons.kicad_sch, 12_Wheel_Feedback.kicad_sch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]
2026-09-13 Repair copper contacts and make manufacturing panel router-compatible
    [Encoder.kicad_pcb, Main.kicad_pcb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]
2026-09-15 Audit repository contents and publish reproducible brake simulation
    [metrics.csv]
2026-11-03 Checkpoint two-layer Main, Wheel and Encoder PCB variants
2026-11-04 Develop compact two-layer stacked boards with passive Hall buttons
    Add 70x100 mm tapered Main placement studies, reduce the Main and Wheel harnesses to 19 wires with three grounds, and shrink routed Wheel to 55x60 mm. Remove button coil circuitry for passive plastic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
2026-11-04 Route stacked main boards and panelize standard 0.3 mm vias
2026-11-04 Checkpoint routed two-layer boards, Wheel profile and power review
2026-11-04 Reorder Main and Wheel passives, route wider power bends and verify final panel
2026-11-05 Record JLCPCB partial assembly quote and cheapest shipping comparison
2026-11-05 Remove superseded PCB revisions and preserve shared dependencies
